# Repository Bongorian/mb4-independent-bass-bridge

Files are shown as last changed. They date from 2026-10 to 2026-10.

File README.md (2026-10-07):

# MB4 — 各弦独立・ピエゾ対応の4弦ベース用ブリッジ

4弦ベースのブリッジを、**1弦ずつ独立したアルミ切削部品と市販ステンレス金物**で構成する試作設計です。各弦に裏面ピエゾを追加でき、高さとオクターブを個別に調整できます。球端から弦を伸ばす構成はRay Rossを参考にしています。

This repository documents a prototype four-string bass bridge with independent modules, optional per-string piezo pickups, adjustable height, and 20 mm of intonation travel. It includes CNC STEP files, drawings, hardware lists, reproducible CAD sources, and the complete Rev A–L design history. Documentation is primarily in Japanese; the current shop drawings and quotation brief are in English.

**最新版はRev Lです。ボールエンド保持部を、丸い入口と半円の奥を持つ一つの座へ再設計しました。球端後方の不要な溝をなくしています。** 汎用Jazz Bass／Precision Bass系を想定していますが、既存のFender系5穴への互換設計ではありません。取付位置は実機で決める、新規穴あけ用の試作です。CADの形状・干渉を確認した段階で、実機強度・耐久性・音響とJLC CNCの正式な加工受託は未確認です。

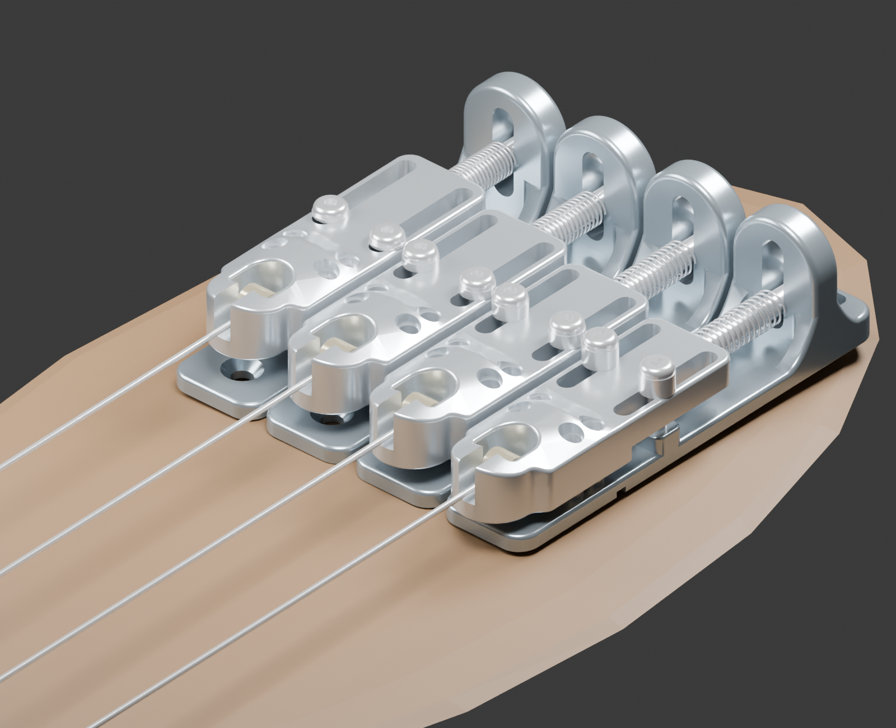
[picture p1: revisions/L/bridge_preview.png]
Rev LのCADプレビュー


## まず読む資料

| 知りたいこと | 資料 |
| --- | --- |
| 仕組み・寸法・設計の狙い | [設計説明](docs/design.md) |
| 組立・弦高・オクターブ調整 | [組立と調整](docs/assembly.md)、[図入りガイド](revisions/L/pdf/MB4_RevL_guide.pdf) |
| CNCの見積・発注に使うファイル | [加工と調達](docs/manufacturing.md) |
| Rev AからLまでの変更 | [開発履歴](docs/revision-history.md) |
| 確認済みの範囲と残る評価 | [検証記録](docs/validation.md) |
| ソースからSTEPなどを作り直す | [再生成手順](docs/reproduction.md) |

## Rev Lの主要仕様

| 項目 | 設計値・構成 |
| --- | --- |
| 弦数・弦間 | 4弦、19 mmピッチ、全幅75 mm |
| 機械加工部品 | B10ベース＋A10アンカー、各弦2部品・合計8部品 |
| 材質 | 両部品ともアルミ6061-T6 |
| 各ベースの外形 | 幅18 × 長さ86 × 最大高さ25 mm |
| アンカーの外形 | 幅18 × 長さ55 × 最大高さ10.5 mm（包絡上限） |
| 参考弦中心高さ | ボディ表面から8〜20 mm。球端と巻き部の実物で変わる |
| オクターブ調整 | 20 mm連続、中央から前後各10 mm |
| 高さ・固定金物 | M4平先4本／弦、M3固定ねじ2本／弦 |
| 後方調整 | M4×45全ねじ＋UY6-35圧縮ばね |
| ボディ固定 | 前1穴＋後1穴／弦、合計8穴 |
| ピエゾ | 各弦裏面にφ12以下、接着・配線込み厚さ1.2 mm以下を想定 |

**ベース板の長さ86 mmと、可動部を含む全長は別です。** 前方限界ではアンカーが15 mm張り出し、モジュール全長は101 mmになります。

機能に必要な取付面・固定座・高さねじの走行面は平面です。凸曲面の仕上げ工程が増えるため、Rev Jと同じ加工費を想定せず見積で確認します。

## ダウンロードと加工用データ

- [Rev L JLC見積用ZIP](downloads/MB4_JLCCNC_upload_RevL.zip)：B10とA10の単品STEP＋対応する英文加工図。各4個。
- [Rev L 6面プレビューZIP](downloads/MB4_RevL_six_views.zip)：同倍率の正投影画像。
- [Releases](https://github.com/Bongorian/mb4-independent-bass-bridge/releases)：Blenderモデルなどを含む元のRev Lフルパッケージも配布。
- [B10ベースSTEP](revisions/L/cad/step/B10_streamlined_base.step)／[B10加工図](revisions/L/pdf/B10_streamlined_base.pdf)
- [A10アンカーSTEP](revisions/L/cad/step/A10_sculpted_ball_anchor.step)／[A10加工図](revisions/L/pdf/A10_sculpted_ball_anchor.pdf)
- [部品表](revisions/L/BOM.csv)、[ミスミ購入候補](revisions/L/MISUMI_purchase_options.csv)、[原寸取付DXF](revisions/L/MB4_mount_template_1to1.dxf)

加工に提出するのは**Rev Lの単品STEPと同名の加工図**です。組立STEP・STL・外観画像は参考資料です。STEPのねじ穴は下穴径なので、加工図のタップ指示も必要です。旧版と最新版の部品・図面を混ぜないでください。

## Rev A〜Iの発展とRev J/K/L

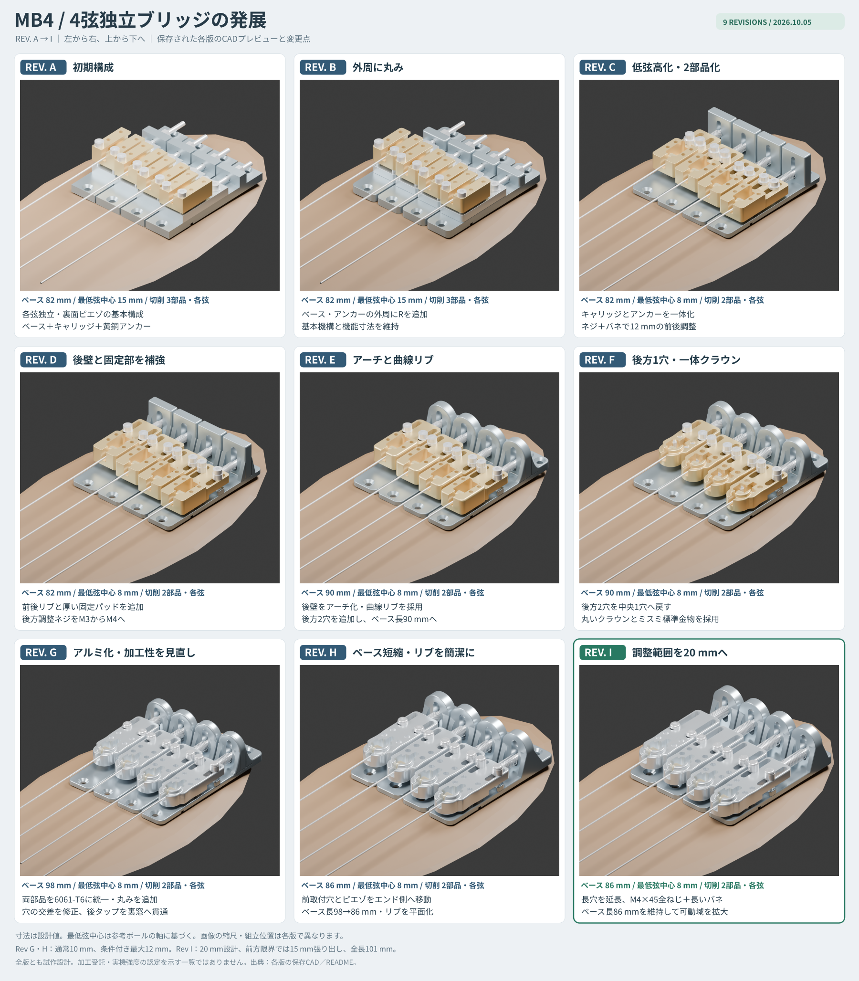
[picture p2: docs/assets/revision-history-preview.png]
Rev A〜Iの開発一覧


[高解像度の一覧PNG](docs/assets/revision-history.png) ／ [変更点の詳細](docs/revision-history.md)

Rev Jでは稜線にRを追加し、Rev Kでは上面を前から後ろへ流線的につなぎました。[Rev I→J](docs/assets/rev-i-to-j.png) ／ [Rev J→K](docs/assets/rev-j-to-k.png)で確認できます。

Rev Lは球端保持部を改訂しました。[保持部の拡大画像](revisions/L/ball_cradle_empty.png)と[装着参考](revisions/L/ball_cradle_loaded.png)を参照してください。

## リポジトリ構成

```text
README.md              プロジェクトの入口と最新版へのリンク
docs/                  設計・組立・加工・検証・履歴の説明
docs/assets/           Rev A〜Iの一覧画像
revisions/A/ ... L/    各版の保存STEP・PDF・ソース・部品表・プレビュー
downloads/             Rev Lの見積用ZIPと6面画像ZIP
tools/                 整合性確認と一覧画像の再生成
```

過去版は開発記録です。各フォルダの元READMEは当時の寸法・判断を保存しています。現行のファイル構成や発注手順はこのREADMEと`docs/`を参照してください。大きなBlenderファイル、再生成できるSTL、作業ログ、ローカルPython環境はGitの管理対象から外しています。

更新日：2026-10-07。試作の実物評価・加工先の審査結果が出たら、対応する改訂版として記録する想定です。

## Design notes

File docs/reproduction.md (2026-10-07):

# 再生成とファイルの扱い

## 環境

現在のSTEPはCadQuery 2.8.0で生成しています。保存プレビューはBlender 4.5.9を使用しています。Python依存の固定バージョンは[Rev L requirements](../revisions/L/cad/requirements.txt)を参照してください。動作確認環境はUbuntu・Python 3.12です。

```bash
python3 -m venv .venv
.venv/bin/pip install -r revisions/L/cad/requirements.txt
```

画像の日本語ラベルにはNoto Sans CJKのフォントが必要です。6面画像の合成ソースはLinuxの標準フォントパスを使用しています。別のOSではフォントパスを環境に合わせて変更します。

## Rev LのCAD再生成

```bash
.venv/bin/python revisions/L/cad/build_bridge.py
.venv/bin/python revisions/L/cad/verify_travel.py
```

部品STEP・組立STEP・プレビュー用STL・scene manifest・検証JSONが`revisions/L/cad/`以下に生成されます。`parameters.json`は設計値の一覧ですが、寸法の一部は生成コード内にもあります。全寸法が自動連動するパラメトリックモデルではありません。形状変更時にはコード・図面・金物選択を合わせて更新します。

保存STEPを生成し直さず検査する場合は、`build_bridge.py --verify-existing`で、現行ソースから作るB-repとの一致と9条件の機能確認を行えます。

## プレビューと加工資料

```bash
blender --background --python-exit-code 1 --python revisions/L/cad/render_bridge.py
blender --background --python-exit-code 1 --python revisions/L/cad/render_ball_cradle.py
blender --background --python-exit-code 1 --python revisions/L/cad/render_six_views.py
.venv/bin/python revisions/L/cad/compose_six_views.py
.venv/bin/python revisions/L/cad/make_documents.py
.venv/bin/python revisions/L/cad/package_outputs.py
```

CAD生成→通常プレビュー→6面プレビュー→画像合成→PDF/部品表→パッケージの順で実行します。`render_six_views.py`は通常プレビューで保存するBlenderモデルを読みます。生成後はPDFの全ページをレンダーし、図・寸法・文字の重なりと、STEPと同じ改訂になっていることを目視確認します。

再生成したZIPは`revisions/L/`以下にできます。トップレベルの`downloads/`は公開用に保存したコピーなので、自動で差し替わりません。変更を配布する場合は対応ZIPをコピーし、資料・保存ファイルのチェックサムを更新してからコミットします。加工形状を変える場合は、新しい改訂として記録することを推奨します。

## 歴史的版

各版は独立した`revisions/<版>/cad/build_bridge.py`と`parameters.json`を持ちます。その版の`requirements.txt`を使用します。過去READMEの相対パスや元の配布名は当時の記録です。現在は`output_revH/...`ではなく`revisions/H/...`を使用します。

Rev HのA06加工図はRev Gから変更せず流用したため、図面の版表示がRev Gです。Rev LはB10/A10双方の新しい図面を持ちます。保存PDFを最新版と混ぜないでください。

## 開発一覧画像

```bash
python3 tools/make_revision_overview.py
```

各版の保存PNGをそのまま配置し、日本語説明を加えたSVGレイアウトを作ります。Ubuntuのlibrsvg・Cairo・Noto Sans CJKを使用してPNGへ描画します。画像の形状を生成AIで描き直す処理はありません。

## 資料の整合性確認

```bash
python3 tools/check_repository.py
```

このチェックは標準ライブラリだけで実行できます。リンクと配布物の整合性を確認し、加工可否や実物の強度判定は行いません。

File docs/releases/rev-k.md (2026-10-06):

# Rev K — 流線的な外形と高さ穴の縁

丸い前部から低い後部へ滑らかにつながる上面と、単純なアーチ・曲線リブを持つ試作版です。アンカー中央の盛り上がった筋や、支柱の別の座ボスを設けず、穴の縁が外周や隣の加工部へ切れない形に整理しました。

- 上面は連続したBezier面、後部は一段の固定平面Z8。上限10.5 mm（切欠き後のSTEP最高値は約10.42 mm）。
- 後壁は厚さ6のR9アーチ、前後縁R1.2。一続きの3 mm曲線リブを支柱内部へ2 mm重ね、固定パッド根元も底板へつなげます。
- 高さ穴をアンカー座標X±5.5/Y19・24へ移し、入口φ4.2・床Z8に変更。床周囲0.5 mm、タップ主径周囲0.8 mmの材料をCAD確認。
- ベース86 mm、参考弦中心8〜20 mm、オクターブ20 mm、木ねじ・ピエゾ位置、市販金物候補を維持。

加工対象はB09_streamlined_baseとA09_streamlined_anchor、両方6061-T6、各4個です。最新版の単品STEPと同名英文PDFを併用してください。前方限界の張り出し15 mm、モジュール全長101 mmです。

## ダウンロード

- `MB4_CNC_prototype_RevK.zip`：CAD・STEP・図面・部品表・ガイド・Blender・STL・プレビューの一式。
- `MB4_JLCCNC_upload_RevK.zip`：B09/A09の単品STEP＋同名英文加工図、計4ファイル。
- `MB4_RevK_six_views.zip`：6面プレビューと画像生成ソース。
- `rev-j-to-k.png`：Rev JとKの同条件のCADレンダー比較。

[README](https://github.com/Bongorian/mb4-independent-bass-bridge#readme)から設計説明・組立・調達・検証・再生成手順を読めます。過去版は保存しています。

## 確認範囲

9つの位置／高さ条件、1 mm刻み21位置、入口床の縁とねじ周囲の材料、高さ足の接地、座面接触、STEP再読込を確認しました。元CADとSTEPの両方向の形状差分は0、外形座標差は1e-5 mm未満です。体積数値積分は診断値として記録します。

曲面仕上げの加工量は増えます。JLCの工具到達性・受託可否・価格、実物の強度・疲労・弦の球端適合・木部保持・ピエゾ性能は未確認です。STEP＋対応図面で手動見積審査を依頼する資料です。

## 配布物のSHA-256

```text
04e64b7c81280b9260a139cd08f7b878d53910644a1df4d1c6e72b4872af992e  MB4_CNC_prototype_RevK.zip
0aff2bb30ec78b04c7777be666f19021fa927c6372cc8626bd08be98724e24f5  MB4_JLCCNC_upload_RevK.zip
40939c0831099249c68dbce3949f1855e0372b30fb1f3a133ace95b778d89680  MB4_RevK_six_views.zip
6c2ca22163dc0604c4ab6a724325f499ec6b36fb4377719d1634a07c94e5cb18  rev-j-to-k.png
```

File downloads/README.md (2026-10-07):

# Rev Lのダウンロード

- [MB4_JLCCNC_upload_RevL.zip](MB4_JLCCNC_upload_RevL.zip)：B10とA10の単品STEPと同名PDF、計4ファイル。各4個で見積依頼するための資料。
- [MB4_RevL_six_views.zip](MB4_RevL_six_views.zip)：6面画像、一覧画像、視点情報、説明と画像生成ソース。
- [Releases](https://github.com/Bongorian/mb4-independent-bass-bridge/releases)：元のRev Lフルパッケージ。CADソース、Blenderモデル、プレビュー、加工資料、組立ガイド等を含む。

最新版の仕様と未評価事項は[トップREADME](../README.md)と[加工説明](../docs/manufacturing.md)を参照してください。見積用ZIPの存在はJLCの加工受託や発注完了を示しません。

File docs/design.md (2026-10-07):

# 設計説明 — MB4 Rev L

## 何を作る設計か

MB4は、4弦ベースの各弦を独立したブリッジモジュールで保持する試作設計です。複雑な専用金物を増やさず、アルミ部品2種類と市販のねじ・座金・圧縮ばねで、高さ・オクターブ調整とピエゾ取付を成立させることを目的としています。

弦間は19 mm、各ベース幅18 mmなので、隣のベースとの間に1 mmあります。中央の弦間基準に対する各弦のX座標は−28.5、−9.5、9.5、28.5 mmです。

## 1弦分の構成

| 構成要素 | 役割 |
| --- | --- |
| B10ベース | 木部へ固定する板、調整ねじを受ける後壁、リブ、固定ねじのパッド、裏面ピエゾ窪み |
| A10アンカー | 凸上面とカプセル状の球端保持部、弦の逃げ、前後移動用長穴、高さねじ、後方M4タップ |
| M4平先4本 | アンカーをベース上に支持し、高さを変える |
| M3固定ねじ2本 | 長穴を通して位置を固定する |
| 後方M4×45＋ばね | 前後位置を調整する。ねじを締めるとエンド側へ引き、緩めるとばねが前へ押す |
| 前後の木ねじ | モジュールをボディへ固定する |

Ray Rossの球端から弦を伸ばす構成を参考に、従来のサドルに相当する保持部を一体の保持部にしています。メーカー製品のtone pinと同じ機構・音響特性を再現したと確認した設計ではありません。実際の支点は球端・巻き部によって変わるため、実弦で評価します。

## ボールエンド保持部の再設計

Rev Lは、角丸四角形の窪みと後方へ延びる細溝を、一つのカプセル状の保持座へ整理しました。前には弦張力を受ける肩を残し、奥は大きな半円、上面との境界は実形状のR0.6でつなぎます。後方の不要な細溝をなくしたため、球端の後ろに連続した材料が残ります。

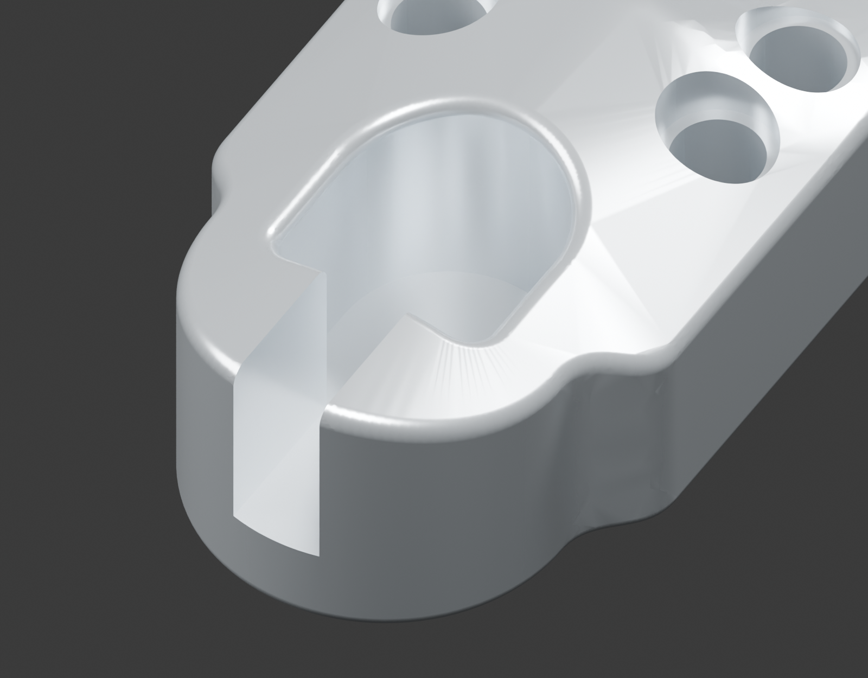
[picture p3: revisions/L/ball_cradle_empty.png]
球端保持座の拡大


窪みの基準形状は幅8.2、Y6〜15、底Z2、前内隅R1.1、奥R4.1（中心Y10.9）です。前の保持肩はY6、幅6を前向きの幅3.4の弦出口で二分します。弦出口の底Z3.3は維持し、後方へは延ばしません。入口のRによる広がりはSTEPを参照します。

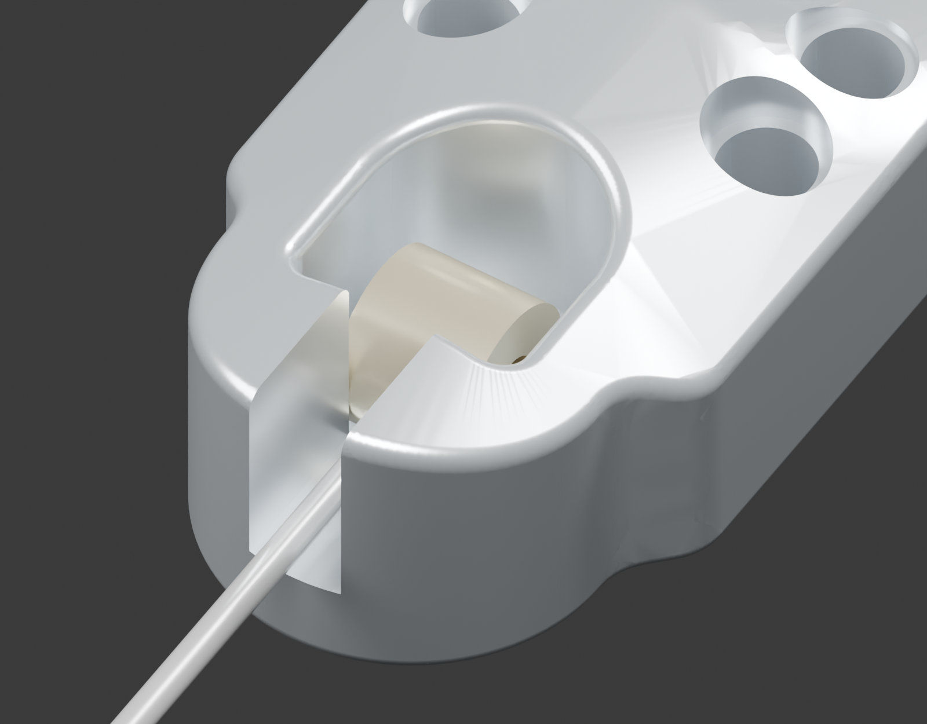
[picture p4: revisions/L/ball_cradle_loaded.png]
球端装着の参考


球端を上からY11へ入れ、前の肩へ寄せます。参考球端は外径6・横幅4.75の円筒、横軸X、着座中心Y9/Z5です。CADでは縦挿入とY11から9への移動、肩による前方への抜け止め、前方の弦出口を確認しました。弦張力で肩に保持する構成であり、球端を締め付ける追加のねじはありません。無張力で上方へ取り出せるため、完全な包囲や無張力時の脱落防止は保証しません。

実物の球端・巻き部の寸法と接触は未確定です。市販の全弦に対応するとの保証ではなく、使用弦で収まり・接触・弦高・必要なオクターブ補正を評価します。保持肩Y6と底Z2を保ち、参考弦高8〜20 mmと調整20 mmは維持しています。B10ベースはRev KのB09と同形状で、A10との組合せを明確にするため品番・版を揃えています。

## 低い弦高と調整域

ベース下面をZ0、主板上面をZ3とします。アンカー下面と主板上面の隙間を`g`とすると、参考弦中心は`H = 8 + g` mmです。`g = 0〜12`で参考高さ8〜20 mmになります。後壁の高さ25 mmは構造物の全高であり、最低弦高ではありません。

各アンカーの前端位置を、ベース前端Y0に対して`q`とします。Rev Lでは`q = −15〜5`、移動量20 mmです。中央は`q = −5`です。固定長穴は全長23.4 mm・幅3.4 mmで、M3軸中心が20 mm移動した両端に公称0.2 mmの余裕を持たせています。

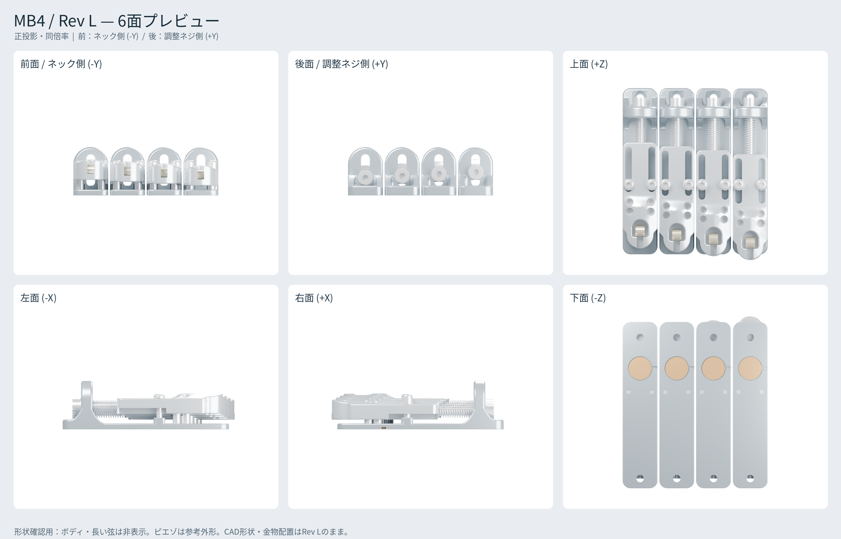
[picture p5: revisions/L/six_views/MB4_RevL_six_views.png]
Rev Lの6面図


Rev Iでベース長を増やさず可動域を広げるため、アンカー長を50→55 mm、後壁位置を7.5 mmエンド側へ移し、ネジ先端が移動できる裏面開放窓を延長しました。Rev Lでもその機構を維持しています。前方限界ではアンカーが15 mm張り出し、モジュール全長は101 mmです。ネック側の余白とピックガードとの干渉も取付時に確認します。

## 流線的な外形と穴の縁

Rev Kから継続して、丸い前部から低い後部へつながる一枚の上面を持ちます。前側は放物線の断面で、側端X±9/Z7.8、頂部X0/Z10.5です。Y21〜27.8で接線が滑らかにつながる面を使い、後部上面Z8へ下げます。独立した円柱クラウン、後部中央の盛り上がった筋と、個別の固定座の段差をなくしました。最高部は10.5 mm、弦の保持位置は維持するので参考最低弦高は8 mmです。

支柱は厚さ6の単純なR9アーチ、前後縁R1.2です。座金・ばねは前後の平面で受け、追加の座ボスを設けません。左右の3 mmリブは一続きの曲線で支えます。外稜線R0.8、内側縦根元R2、内稜線はC0.2 MAXのバリ取りです。曲線の詳細はSTEPを基準にします。根元下の装飾的な溝は作りません。

高さ穴をX±5.5/Y19・24へ移し、上側入口をφ4.2にしています。輪郭のくびれをなくし、外周・隣の穴・固定座へ入口が切れ込む形を避けました。床Z8から下面まで8 mmのM4ねじ領域を保ち、入口床周囲の0.5 mm材料と、タップ主径周囲の0.8 mm材料をCAD確認します。穴周辺の最終バリ取り・丸みは図面指示の範囲で行います。

必要な取付面・固定座・走行面・接着面は平面です。曲面仕上げが増えるため、加工費と工具到達性は手動見積審査で確認します。リブの曲線化後の荷重下剛性と疲労は未評価です。材料ガードのCAD確認を実物強度保証として扱いません。

## 各弦ピエゾ

ベース裏面の中心X0/Y24にφ12.5・深さ1.5 mmの窪みがあります。φ12以下の素子を金属面へ接着し、接着・配線を含めた厚さを1.2 mm以下にする想定です。木部と挟み込む構成ではありません。

4個の素子を各々の高インピーダンス入力・バッファへ接続する想定です。具体的なピエゾ品番と電子回路はこのリポジトリでは確定していません。機械的に独立したモジュールでも共通木部から振動が回り込むため、完全な弦間分離を保証しません。

## 座標と取付

各部品のX0は幅の中央、Y0はその部品のネック側前端、Z0は下面です。アンカーの寸法とベースの寸法はそれぞれの原点で記載します。アンカーをベースへ組むときはY方向へ`q`、Z方向へ`3 + g`移動します。

ベースの木ねじ中心はX0/Y8とX0/Y81、前後間隔73 mmです。既存ブリッジを交換する場合にも取付位置の実測が必要です。参考保持肩はベース座標で`Y = q + 6`です。最終位置は実弦、ネック、必要な補正量から決定してください。

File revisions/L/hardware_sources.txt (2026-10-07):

REV L NOTE / 2026-10-07: hardware choices unchanged from Rev J.
Catalogue/price dates below are historical; no new live price claim.

Rev J：市販金物はRev Iから変更なし。以下は2026-10-05に確認した参照記録です。

MB4 Rev I / MISUMI reference / 2026-10-05

Rev Iで後方ねじとばねを変更。型式と仕様を公式公開表で確認。新2品の現在価格・見積は未取得、注文はしていません。
以下の従来金物の価格は同日Rev Hで確認した条件付きの参考値です。購入時に数量・納期・送料を再確認。

1. 後方ねじ：ミスミ SNSS-M4X45-FT（メーカー NBK SNSS-M4-45-FT）
https://jp.misumi-ec.com/vona2/detail/221000236253/
https://www.nbk1560.com/products/specialscrew/nedzicom/captivescrew/SNSS-FT/SNSS-M4-FT/
SUSXM7（SUS304相当）、A2-50、M4x0.7、全ねじ45、頭径7、高さ4、六角3。4本。
通常の半ねじSCB4-45は使用不可。首下の非ねじ部がタップ域へ入るためです。
公称ボルト先端Y32。最前q=-15で全周8のかかり、長さが短い側0.5なら7.5。
最後q=5で先端はアンカー局所Y27。長い側0.5なら26.5で、開放窓内に収まる。
メーカー表示価格とミスミ表示価格は条件が違うため購入合計として混同しません。

2. ばね：ミスミ UY6-35
https://jp.misumi-ec.com/vona2/detail/110302604820/
OD6、線径0.4、自由長35±1.5、k0.098±10% N/mm、密着長参考6.8、許容たわみ26.25。
SUS304-WPB。クローズエンド無研削。UY6-20/E-GUY6-20は20 mm案に流用しない。
作動長15.5-q =30.5〜10.5。最短の自由長33.5でも最前位置に予圧3が残る。
最長の自由長36.5・最短作動10.5でたわみ26.0≤26.25。CAD公称の残り0.25なので実寸でも確認。
寸法公差・加工座位置の積み重なりで可動端を少し制限する場合があります。密着まで潰さない。
参考ねじ内径：OD下限5.5-線径2x0.4=4.7。線径・端部の実物適合は別途照合。

3. 高さ：MSSFS4-8 / MSSFS4-12 / MSSFS4-16（SUSXM7、平先）
https://jp.misumi-ec.com/vona2/detail/110302679970/?HissuCode=MSSFS4-8
https://jp.misumi-ec.com/vona2/detail/110302679970/?HissuCode=MSSFS4-12
https://jp.misumi-ec.com/vona2/detail/110302679970/?HissuCode=MSSFS4-16
六角2、各弦4本。g≤4は8、4<g≤8は12、8<g≤12は16。
10〜199本の通常価格は8が117円、12/16が118円。納期割引はいずれも38円／本。1〜9本は通常160円、納期割引80円。必要4本なら320円、10本380円より少額。必要12本なら12本456円。
単価4〜7円のエコノミーE-GMSSFSは最低500本等なので、1本分の試作では購入総額が増える。M3×16のSSHH-SUS品は販売終了、推奨代替SSHHI-SUS-M3-16は1000本箱14,743円の表示だったため、M4標準3長さへ変更した。

4. 固定：SCB3-16（安価なキャップ頭の代案）（SUS304相当、A2-70）
https://jp.misumi-ec.com/vona2/detail/110300239250/?HissuCode=SCB3-16
画像初期設定g=5/4/3/2は全8本L16。10本通常550円、納期割引150円。
gを大きく変える場合はSCB3-12/20/25もガイド3頁から選択。シリーズ規格表で寸法候補を確認、これら3型番の個別価格は未確認。L25の半ねじ18はクランプの通し長穴では使える（基部Z0〜6はねじ域）。

5. 小径座金：WSJS-SUS-M3 / WSJS-SUS-M4（SUS304）
https://jp.misumi-ec.com/vona2/detail/221000552007/?HissuCode=WSJS-SUS-M3
https://jp.misumi-ec.com/vona2/detail/221000552007/?HissuCode=WSJS-SUS-M4
M3はOD6/ID3.3/t0.5、固定ねじの高さ合わせに重ねる。画像初期設定はt0.5/1.5/2.5/3.5を各2組、計32枚。50枚×60円=3000円、100枚×30円=3000円（確認した数量別価格表の計算）。100枚のほうが追加高さ調整に使える。厚さは実測し、ねじ先端の突出を避ける。
M4はOD8/ID4.5/t0.5、後方4枚×228円=912円。
座金は今回のミスミ小ロット金物費の大きい部分。同寸法の手持ちSUS品を使える。大径M3座金へ無条件に置換せず、外径6以下を守る。
厚いUUW-0306-35は外径6/内径3.2/t3.5が適合するが50個以上、薄いUUW-0306-05Hは1個からでも表示314円。初期4弦用ではJIS小形の厚さスタックを候補とする。

6. 木ねじ：コノエ270011003520
https://jp.misumi-ec.com/vona2/detail/221006330995/?HissuCode=270011003520
ステンレス皿木ねじ3.5×20、85本入り1パック1200円、6日目。前4＋後4=8本使用。頭径・90°皿との適合は購入前または現物で照合（掲載寸法の3.5/20と材質は確認、頭径の詳細は未確認）。木部の下穴・厚さ・空洞・既存穴との位置を実測する。

7. 丸い低頭の固定ねじ（Rev Iの参考組立）
https://jp.misumi-ec.com/vona2/detail/110302280450/
SSBCB3-12 / SSBCB3-16 / SSBCB3-20（SUS316、A4-070）、SBCB3-25（SUSXM7、A2-50）。M3頭径5.7/高さ1.65、六角2。系列の規格表と寸法表で確認。SSBCBのM3に25はなく、SBCBのM3に16はありません。型番を混同しないこと。
個別の現在価格は未確認。系列の価格表には「25年8月時点」と記載されているため、それを現在の見積額として採用していません。初期画像は8本ともSSBCB3-16。購入前に8本・10本・20本の総額と納期を比較。価格優先なら、確認済みSCB3-16の10本150円（納期割引条件）はCADを変えずに使える代案。
ボタン頭の外形は丸い参考モデルで、メーカーCADそのものではありません。頭径・高さ・六角を公称包絡に合わせています。

8. 初期配置
q=3/1/-1/-3、g=5/4/3/2。高さM4x12を4本、x8を12本。固定M3x16を8本、座金0.5を32枚。
後方M4x45全ねじ4本、M4座金4枚、UY6-35を4個、木ねじ8本。
価格合計は未確定。旧Rev F/G/Hの合計は新構成の購入額として使用しません。

Rev L: cradle only changed; hardware candidates retained from Rev K. No fresh price/stock lookup on 2026-10-07.

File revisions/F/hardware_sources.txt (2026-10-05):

MB4 Rev F — MISUMI部品参照・購入メモ（2026-10-05）

公開ページと「価格を確認」の見積表示を確認。発注・カート追加は行っていません。税別、購入時再確認。価格には表示上の特別配送料が含まれる場合があります。送料・アカウント条件・在庫・出荷日は注文時に確認。以下は確認した候補内での購入総額比較で、ミスミ全商品中の最安を保証する選定ではありません。

1. ばね：UY6-20（SUS304-WPB）
https://jp.misumi-ec.com/vona2/detail/110302604820/?HissuCode=UY6-20
OD6、線径0.35、内径公称5.3、L20、k0.098 N/mm、密着長参考3.85、許容たわみ15、端面非研削。外径0/−0.5、L±1.5、k±10%。外径下限と公称線径からの内径参考4.8はM4より大きい（線径公差・ばね端の実物適合は別途）。
通常250円／個。納期割引10日目：1〜3個125円、4〜9個87円。1弦試作1個125円、4弦4個348円。
代案E-GUY6-20：
https://jp.misumi-ec.com/vona2/detail/110310903599/?HissuCode=E-GUY6-20
公称寸法・荷重は同じ。通常78円／個、10個単位・最低10。購入10個780円。急ぐ場合はUY4個通常1000円より少額。
作動長17〜5は公称寸法。実測自由長−作動長≤15を守る。L21.5なら最短6.5（q最大18.5）。密着長まで潰して使わない。固定する弦張力とは別の小荷重ばねです。

2. 後方調整ねじ：SCB4-30（SUS304相当、A2-70）
https://jp.misumi-ec.com/vona2/detail/110300239250/?HissuCode=SCB4-30
M4×30、半ねじ20、頭D7/H4、六角3。10〜29本：通常77円、納期割引19円。使用4本でも10本買190円は、4本×140円=560円より少額。1弦試作では1本140円が少額。
M4×35の半ねじは同じ20でも首下15がタップ域に入り得るため、そのまま置換しない。M4×30に合わせCADを改訂。公称重なり6.5〜18.5、首下とアンカー最大後端の隙間1.5。実物の有効ねじ6以上を確認する。

3. 高さ：MSSFS4-8 / MSSFS4-12 / MSSFS4-16（SUSXM7、平先）
https://jp.misumi-ec.com/vona2/detail/110302679970/?HissuCode=MSSFS4-8
https://jp.misumi-ec.com/vona2/detail/110302679970/?HissuCode=MSSFS4-12
https://jp.misumi-ec.com/vona2/detail/110302679970/?HissuCode=MSSFS4-16
六角2、各弦4本。g≤4は8、4<g≤8は12、8<g≤12は16。
10〜199本の通常価格は8が117円、12/16が118円。納期割引はいずれも38円／本。1〜9本は通常160円、納期割引80円。必要4本なら320円、10本380円より少額。必要12本なら12本456円。
単価4〜7円のエコノミーE-GMSSFSは最低500本等なので、1本分の試作では購入総額が増える。M3×16のSSHH-SUS品は販売終了、推奨代替SSHHI-SUS-M3-16は1000本箱14,743円の表示だったため、M4標準3長さへ変更した。

4. 固定：SCB3-16（SUS304相当、A2-70）
https://jp.misumi-ec.com/vona2/detail/110300239250/?HissuCode=SCB3-16
画像初期設定g=5/4/3/2は全8本L16。10本通常550円、納期割引150円。
gを大きく変える場合はSCB3-12/20/25もPDF5頁から選択。シリーズ規格表で寸法候補を確認、これら3型番の個別価格は未確認。L25の半ねじ18はクランプの通し長穴では使える（基部Z0〜6はねじ域）。

5. 小径座金：WSJS-SUS-M3 / WSJS-SUS-M4（SUS304）
https://jp.misumi-ec.com/vona2/detail/221000552007/?HissuCode=WSJS-SUS-M3
https://jp.misumi-ec.com/vona2/detail/221000552007/?HissuCode=WSJS-SUS-M4
M3はOD6/ID3.3/t0.5、固定ねじの高さ合わせに重ねる。画像初期設定はt0.5/1.5/2.5/3.5を各2組、計32枚。50枚×60円=3000円、100枚×30円=3000円（確認した数量別価格表の計算）。100枚のほうが追加高さ調整に使える。厚さは実測し、ねじ先端の突出を避ける。
M4はOD8/ID4.5/t0.5、後方4枚×228円=912円。
座金は今回のミスミ小ロット金物費の大きい部分。同寸法の手持ちSUS品を使える。大径M3座金へ無条件に置換せず、外径6以下を守る。
厚いUUW-0306-35は外径6/内径3.2/t3.5が適合するが50個以上、薄いUUW-0306-05Hは1個からでも表示314円。初期4弦用ではJIS小形の厚さスタックを候補とする。

6. 木ねじ：コノエ270011003520
https://jp.misumi-ec.com/vona2/detail/221006330995/?HissuCode=270011003520
ステンレス皿木ねじ3.5×20、85本入り1パック1200円、6日目。前4＋後4=8本使用。頭径・90°皿との適合は購入前または現物で照合（掲載寸法の3.5/20と材質は確認、頭径の詳細は未確認）。木部の下穴・厚さ・空洞・既存穴との位置を実測する。

7. 初期設定の購入総額の例
MISUMI_initial_setup_example.csv：g=5/4/3/2、q=18/16/14/12（画像の配置）。納期割引を適用できるものに適用し、公開数量別価格から計算すると金物合計6576円（税別）。CNC2部品、ピエゾ、接着・配線・電子部品は含まない。1台完成までの総費用や見積確定額ではありません。高い弦高へ交換するM4×16とM3の別長さはこの初期購入例に含まない。

8. Ray Ross参照
開発者の説明： https://www.deviser.co.jp/rayross/about
Kemp2023研究： https://journals.plos.org/plosone/article?id=10.1371/journal.pone.0292515
本案は独自の一体クラウン保持部。Ray Rossのtone pin構造と同一ではなく、同じ音響特性を認定していません。

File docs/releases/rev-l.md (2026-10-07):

# Rev L — ボールエンド保持部の再設計

ボールエンドの保持部を、前の平らな肩と奥の大きな半円を持つ一つのカプセル座にしました。上面との入口境界を実形状R0.6でつなぎ、球端の後方へ延びていた不要な細い溝をなくしています。

- 保持窪み：幅8.2、Y6〜15、前内隅R1.1、奥R4.1、底Z2。
- 保持肩Y6と参考弦軸Z5を維持。弦出口は幅3.4・底Z3.3の前方だけです。
- 外径6・幅4.75の参考円筒球端で、縦挿入、前の肩へ寄せる経路、前方抜け止めをCAD確認。
- 参考弦中心8〜20 mm、オクターブ20 mm、ベース86 mmと市販金物を維持。
- B10ベースはRev KのB09と同形状。保持部を変えたA10と版・品番を揃えています。

加工対象はB10_streamlined_baseとA10_sculpted_ball_anchor、6061-T6、各4個です。同名の単品STEPと英文加工図を併用します。最前位置の張り出し15 mm、モジュール全長101 mmです。

## ダウンロード

- `MB4_CNC_prototype_RevL.zip`：CAD・STEP・加工図・部品表・ガイド・Blender・STL・通常／拡大プレビューの一式。
- `MB4_JLCCNC_upload_RevL.zip`：B10/A10単品STEPと同名英文加工図、計4ファイル。
- `MB4_RevL_six_views.zip`：6面プレビューと画像生成ソース。
- `ball_cradle_empty.png`：球端保持座を空の状態で確認するCAD拡大画像。

[README](https://github.com/Bongorian/mb4-independent-bass-bridge#readme)から設計説明・組立・調達・検証・再生成手順を読めます。過去版は保存しています。

## 確認範囲

各部品の有効性とSTEP再読込、9つの位置／高さ条件、1 mm刻み21位置、4本の高さ足、ねじ周辺の材料、機能座面と入口床の縁を確認しました。球端の縦挿入11高さと着座経路11位置を参考形状で検査し、前方へ0.3 mm変位した球端が保持肩に当たることを確認しました。新旧ベースの両方向Boolean差分体積は0です。

弦張力で肩へ保持する開放構造です。締め付けねじや無張力時の上方脱落防止機構は追加していません。実物の球端・巻き部適合、接触、強度・疲労、木部保持、ピエゾ性能、JLCの加工受託・価格は未確認です。CADは試作見積資料であり、発注はしていません。

## 配布物のSHA-256

```text
0f81e32088d3af8071832b93dffd80d3daf665328a75f05430c7ffd8c2e29471  MB4_CNC_prototype_RevL.zip
52262cb1fd562b846dd3924ec171d557de436239c5b17c7e62464229f67fe6eb  MB4_JLCCNC_upload_RevL.zip
172108623f4a4e9c7c14cdda41dab48ba1f72c3cf8765c681fdd490755602e7f  MB4_RevL_six_views.zip
cac7d3ac1d2cf34d5facabf0720da819a4b5480ff3ed958083c93bca99c99a80  ball_cradle_empty.png
```

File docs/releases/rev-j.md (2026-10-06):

# Rev J — 外周・アーチ・リブとアンカーの丸み

Rev Iの機構を維持し、外周と後壁・リブ・アンカーの稜線を一定Rで丸めた試作版です。

- 後壁アーチ縁R1.2、リブ外側R0.8・内側R0.5、自由な前板上縁R0.5。
- アンカー上縁R1.2・下縁R0.6、クラウン上縁R1.2・根元R0.6。
- ベース長86 mm、20 mmのオクターブ調整、参考弦中心8〜20 mm、穴位置・ピエゾ位置・金物はRev Iと共通。
- リブの基本面は簡潔な平面を維持。曲線の膨らみや根元下の溝は追加していません。

加工対象はB08_rounded_baseとA08_rounded_anchor、両方6061-T6、各4個です。新しい単品STEPと同名の英文加工図を併用してください。前方限界ではアンカーが15 mm張り出し、モジュール全長101 mmです。

## ダウンロード

- `MB4_CNC_prototype_RevJ.zip`：CAD・STEP・図面・部品表・ガイド・Blender・STL・プレビューの一式。
- `MB4_JLCCNC_upload_RevJ.zip`：B08/A08の単品STEP＋同名英文PDF、計4ファイル。
- `MB4_RevJ_six_views.zip`：6面プレビューと生成ソース。
- `rev-i-to-j.png`：Rev IとJの比較画像。

[README](https://github.com/Bongorian/mb4-independent-bass-bridge#readme)に、文脈なしで読める設計説明・組立・調達・検証・再生成手順を整理しています。過去版は開発履歴として保存しています。

## 確認範囲

9つの前後位置・高さ条件、1 mm刻み21位置、M4周辺材料、高さ足の接地、STEP再読込を確認しました。丸みの曲面について元ソリッドとSTEPの両方向Boolean差分は体積0、外形座標差は1e-5 mm未満です。

一定Rの仕上げパスは増えます。JLCの加工受託・工具到達性・価格、実物の強度・疲労・球端適合・木部保持・ピエゾ性能は未確認です。Rev Iの図面とは混ぜないでください。

## SHA-256

```text
7b65bbe42676a487e3f9052490c8d40ead28eaad107a8ed2b524325313ed0627  MB4_CNC_prototype_RevJ.zip
ab7b4e9c57ca968b28b27881d6b1a4822d5bbc315503f346f7cf4f189f40c46a  MB4_JLCCNC_upload_RevJ.zip
ab24897194916a0cecbef8d11a3664640be46f4d6773b3b2e711626f29d4ee69  MB4_RevJ_six_views.zip
d7162a3460deec55edbec67f03354f49b57dc14550c576853ecbbd51c6a71e0d  rev-i-to-j.png
```

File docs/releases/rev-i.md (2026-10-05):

# Rev I — 20 mm調整とRev A〜Iの設計資料

各弦独立・ピエゾ対応の4弦ベース用ブリッジの試作設計です。ベース長86 mmのままオクターブ調整範囲を20 mmへ拡大したRev Iと、Rev A〜Iの保存CAD・図面・開発履歴を公開します。

[README](https://github.com/Bongorian/mb4-independent-bass-bridge#readme)から設計説明、組立・調整、加工・部品調達、検証範囲、再生成手順へ進めます。

## 添付ファイル

- `MB4_CNC_prototype_RevI.zip`：元のRev Iフルパッケージ。STEP、加工PDF、部品表、ガイド、CADソース、STL、Blenderモデル、プレビュー。元の配布ディレクトリ構成を保持しています。
- `MB4_JLCCNC_upload_RevI.zip`：B07ベースとA07アンカーの単品STEP＋英文加工図、計4ファイル。2種類を各4個で見積依頼します。
- `MB4_RevI_six_views.zip`：6面プレビューと視点情報・生成ソース。
- `revision-history.png`：Rev A〜Iの発展一覧、3600×4110 px。

GitHubのSource code ZIP/TARは整理後のリポジトリ全体で、A〜Iの保存データと新しい説明資料を含みます。元のフルパッケージとファイル配置が異なります。

## 仕様と評価段階

両切削部品はアルミ6061-T6、弦間19 mm、各弦2部品、参考弦中心8〜20 mm。前方限界ではアンカーが15 mm張り出し、モジュール全長101 mmです。後方はM4×45全ねじとUY6-35ばねを使用します。

CADの干渉確認・STEP再読込を実施しています。荷重・疲労・実弦適合・木部保持・ピエゾの感度と分離度は未評価です。JLCの見積・加工受託・発注は未実施です。旧版の部品や図面と混ぜないでください。

## 添付ファイルのSHA-256

```text
319a7b376d95de474a8513af2a0e5a0c840293bac8c61157ca2935c93aa96914  MB4_CNC_prototype_RevI.zip
324d667b94bea5a883e1dbc90f82b83b5c560085ba9352a642665661eed917d0  MB4_JLCCNC_upload_RevI.zip
baa7da487169ea34584f2419ecf6429733881d2921c9ffcfaab547fe5ae87ecc  MB4_RevI_six_views.zip
ae5dc7ef1dc507fb8415ac4d3a79e0a0bd267b09a514d441e56a566cd063f4fe  revision-history.png
```

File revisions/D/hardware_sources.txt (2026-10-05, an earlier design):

MB4 Rev D 金物の仕様参照（2026-10-05調査）
型番例は寸法と規格の参照。価格・国内在庫・発送先は未確認。
同等規格の一般的なステンレス金物から調達してください。

M4×35全ねじ 六角穴付：Accu SSCF-M4-35-A2-BL 等
https://www.accu.co.uk/metric-cap-head-screws/159430-SSCF-M4-35-A2-BL
標準キャップ頭φ7×4、六角3、ピッチ0.7。全ねじ指定が必要。

M3小径座金：DIN433 φ6/内径3.2/厚0.5
https://www.accu.co.uk/metric-flat-washers/404911-HRDW-M3-A4
M4小径座金：DIN433 φ8/内径4.3/厚0.5
https://www.accu.co.uk/metric-flat-washers/404944-HRDW-M4-A4-BL
M3は一般φ7では隣弦の座金との余裕が小さいため、外径6以下を使用。

圧縮ばね：MBA CS-0500-0200-03-S4-C
https://minibearings.com/products/5-20-0-3-springs-cs0500020003s4c
メーカーPDF p.20：
https://files.minibearings.au/pdf/catalogues/Springs.pdf
OD5、自由長20、線0.3、内径4.4参考、作動5で荷重1.47 N、密着3.15、定数0.1 N/mm。
外形だけで代用せず、M4軸の通過と使用作動長5〜17の条件を購入品で確認。

ねじ引張応力断面積：Bossard Materials screws & nuts の並目ねじ表
M3 5.03 mm2、M4 8.78 mm2。
https://www.bossard.com.cn/-/media/bossard-group/website/documents/technical-resources/en/f-009-en.pdf
参照寸法は概算比較用。強度等級・締付け・局所応力を含む全体強度保証ではありません。

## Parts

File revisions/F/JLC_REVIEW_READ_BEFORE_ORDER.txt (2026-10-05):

MB4 Rev F / JLCCNC加工性確認 / 2026-10-05

結論
アルミ製ブリッジをJLCCNCへ依頼する方向は成立する。ただし現行Rev Fは、そのまま確定発注する版として扱わない。
公開加工条件とローカルSTEPを照合した設計側の判定。JLCCNCによる個別ファイルの受注承認、見積回答、CAM確認は取得していない。

対象
B04_single_rear_base：18×90×25 mm、板厚3、固定パッド6、後方座面5。
A05_crown_anchor：18×42×10 mm、本体8。
ユーザーの希望はアルミ。両部品6061-T6を試作の見積候補とする。JLCCNCは6061と7075に対応する。
現行Rev FのPDF、BOM、features.csvではアンカーがC3604真鍮。両部品をアルミにする発注用図面へ改訂が必要。材質変更だけでは、以下の形状の問題は解消しない。

修正が必要：高さタップと窪みの重なり
前側M4高さタップ：中心(±5,15)、ボール窪み側壁X±4、窪み底Z2。
M4の外径半径2に対し、タップ中心から窪み側壁まで1しかないため、内側で約1 mm重なる。
STEPのφ3.3下穴も窪みに開口する。上部の穴は全周を囲まれたタップではない。
実STEP検査：右前穴の内側点(2.98,15,1)には材料があり、(2.98,15,3)/(2.98,15,6)には材料がない。左前穴も同様。
前穴の全周を囲む部分は公称約2 mmに限られる。高い設定でねじ掛かりが上部だけになる場合もある。
後側穴(±5,20.5)も、下面の逃げへねじ外径の後方が一部開口する。実点(±5,22.52,1)に材料なし。
タップ位置、窪み幅・長さ、裏逃げを同時に変更し、ねじ外径に対する連続した肉厚と各高さでの掛かりを再確認する。
この欠肉は前回のCAD干渉確認で拾えていなかった問題。ソリッドが有効であることは、タップの加工性や強度の保証ではない。
検査ログ：jlc_thread_wall_check.json / 再検査：cad/check_jlc_thread_walls.py。
図解：JLC_thread_wall_issue.png。

技術審査が必要：後尾の深いM4
A05後端Y42、X0/Z4からM4×0.7-6H、有効20 mm、下穴φ3.3深さ22＋先端1。
有効ねじ長20はM4の呼び径の5倍。JLCCNCの推奨3D以内という目安を超える。
特殊工具・追加費用・加工時間の懸念があるが、推奨値を超えたことだけで加工不可能とは断定しない。
現行M4×30の最大公称侵入18.5に対応するため、単にタップを12へ浅くする変更は不可。
盲穴底の余長も確認し、ねじ／調整幅／アンカー形状をまとめて見直すか、現行深さの受注可否をJLCへ確認する。

内側の角と小R
B04：壁とリブの交点X±6/Y67およびY73に、鋭角の内側縦エッジが残る。
STEPの直線縦エッジ：前Z3.8〜13.6298、後Z3〜14.0939。上方から加工する場合の到達深さと工具径を併せて検討。
この壁・リブ内隅に工具用の平面Rを設計側で追加し、ばねと座金の包絡域を再確認する。
重要：中央根元R0.8は底面と壁の丸み。平面の内隅Rと異なり、R0.8だけを根拠に工具径φ1.6しか使えないとは判断しない。コーナR付きエンドミルなどで加工する方法があり、JLCの工具・段取り確認が必要。
A05：弦スリット幅3.4、底Z3.3、終端Y22の内側縦角は工具Rの指示が必要。終端を丸める場合、後尾タップと球受けの機能を再確認する。
球受けはR1.5、最大深さ8。小径工具での加工候補だが、工具長・加工費は個別審査。
クラウン根元R0.4の仕上げ方法は確認対象。外周の凸R、底面・壁のR、平面内隅Rを混同して判定しない。
指定R±0.05を外観用の全Rへ要求すると費用が増える可能性がある。機能に必要なRを特定し、外観Rの許容差は別にする。

公開条件上、見通しがよい部分
部品全体寸法はJLCCNCの寸法範囲内。
板厚3、後方座面5、ピエゾ窪み底の残厚1.5は、金属壁厚推奨0.8を上回る。ただしこれは加工上の目安でありブリッジの許容荷重ではない。
ピエゾ窪みφ12.5深さ1.5、配線溝幅2.2深さ1.2は浅い開放形状。
M3×0.5貫通6、M4×0.7貫通8は一般的なサイズ。ただし周囲の肉の問題を解消してから依頼する。
先端R7、後壁R9、有機的な輪郭は切削できる種類の形状。段取り・工具パスの費用は別途。

発注データの整え方
1. B04とA05を別々の単一ソリッドSTEPで登録。MB4_assembly.stepは製作登録に使わない。
2. 部品ごとにSTEPと同名のPDFを用意し、両方の材質をアルミへ統一する。
3. Web選択をThreads=YES、材質6061-T6、数量各1個（試作）または各4個にする。
4. PDFへM3×0.5-6H / M4×0.7-6H、位置、貫通／有効深さ、必要公差を明記。現行のφ2.5／φ3.3下穴表現はJLCの要求に合う。
5. 一般寸法±0.10と機能寸法±0.05の範囲を図示。必要面だけ平面度・Raを指定。
6. ボール保持肩・接触面・支持面・穴口は、標準の約0.2 mmバリ取りではなく必要なC0.1以下などを個別指定する。
7. 初回は無処理を見積候補にする。アルマイトを選ぶ場合はタップ、支持・固定面、ピエゾ接着面、電気的導通箇所と仕上がり寸法を合わせて確認する。
8. JLCの技術審査が完了し、形状変更と材料指定が一致してから確定発注する。
従来のMB4_CNC_order_RevF.zipは一般の試作見積用で、上記問題を修正したJLC確定発注版ではない。JLCはアップロードZIPの中身をSTEP/PDF/DWG/DXF等の対応形式に限定しているため、CSV・画像・READMEを含む旧ZIPをそのままアップロードしない。

JLCへの確認用メモ（未送信）
Both parts are intended to be machined in Aluminum 6061-T6. Please review each single-body STEP with its matching PDF.
Please confirm the available internal corner radii and tool access at the wall/rib intersections, the crown root, and the end of the string slot.
Please confirm whether the rear M4x0.7-6H hole with 20 mm minimum usable thread and a 22 mm cylindrical pilot depth is supported, and whether it adds tooling costs.
Please identify any required radius, blind-hole clearance or tolerance changes before manufacturing.
The current height-hole/pocket overlaps are under design revision; do not release the unchanged Rev F geometry for production.

参照：2026-10-05閲覧のJLCCNC公式情報
設計ガイド：https://jlccnc.com/help/article/cnc-machining-design-guideline
タップ穴：https://jlccnc.com/help/article/threaded-hole-guideline
注文・ファイル・優先規則：https://jlccnc.com/help/article/cnc-machining-ordering-guidelines
加工能力：https://jlccnc.com/capabilities/cnc-machining-service
6061：https://jlccnc.com/help/article/aluminum-6061-cnc-machining
7075：https://jlccnc.com/help/article/aluminum-7075-cnc-machining

未確認
実機工具・CAM・治具・受注可否・価格・納期、実弦のボール端／巻き部、強度・疲労・木ねじ保持力、アルミでの接触部摩耗とねじ寿命、ピエゾの出力とクロストーク。

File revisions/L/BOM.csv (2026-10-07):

ID | item | quantity_for_4_strings | specification
B10 | Streamlined arch base 6061-T6 | 4 | 18x86x25; STEP + matching PDF
A10 | Refined ball-end anchor 6061-T6 | 4 | 18x55x10.5; STEP + matching PDF
H01 | SNSS-M4X45-FT | 4 | M4x45; FULL THREAD required; capheadD7/H4
H02 | WSJS-SUS-M4 | 4 | OD8/ID4.5/t0.5
H03 | UY6-35 | 4 | SUS304-WPB; OD6/wire0.4/L35+/-1.5/k0.098/solid6.8/deflection26.25
H04 | MSSFS4-8/12/16 | 16 | 4/string; length by g; flat end
H05 | SSBCB3-12/16/20 or SBCB3-25 | 8 | 2/string; buttonheadD5.7/H1.65; 2mm hex; length by g
H06 | WSJS-SUS-M3 | height dependent | OD6/ID3.3/t0.5; stack by g; OD6 maximum
H07 | 270011003520 | 8 | SUS flathead wood screw3.5x20; verify headD<=7/90deg
P01 | Piezo reference envelope | 4 | OD<=12; total mounted thickness<=1.2; individual channels

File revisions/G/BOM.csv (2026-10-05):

ID | item | quantity_for_4_strings | specification
B05 | Smooth base 6061-T6 | 4 | 18x98x25; STEP + matching PDF
A06 | Smooth anchor 6061-T6 | 4 | 18x50x10; STEP + matching PDF
H01 | SCB4-30 | 4 | M4x30; threaded20/plain10; capheadD7/H4
H02 | WSJS-SUS-M4 | 4 | OD8/ID4.5/t0.5
H03 | UY6-20 | 4 | SUS304-WPB; OD6/wire0.35/L20/k0.098/solid3.85
H04 | MSSFS4-8/12/16 | 16 | 4/string; length by g; flat end
H05 | SSBCB3-12/16/20 or SBCB3-25 | 8 | 2/string; buttonheadD5.7/H1.65; 2mm hex; length by g
H06 | WSJS-SUS-M3 | height dependent | OD6/ID3.3/t0.5; stack by g; OD6 maximum
H07 | 270011003520 | 8 | SUS flathead wood screw3.5x20; verify headD<=7/90deg
P01 | Piezo reference envelope | 4 | OD<=12; total mounted thickness<=1.2; individual channels

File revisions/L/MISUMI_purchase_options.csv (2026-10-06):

用途 | 型番 | 価格適用数量 | 販売単位 | 最小注文数量 | 通常単価_税別円 | 納期割引単価_税別円 | 納期条件 | 仕様と選び方（Rev J：金物同じ） | 確認状態 | 確認日 | URL
後方オクターブねじ | SNSS-M4X45-FT | 4個見積要確認 | 本 | 1 |  |  | 現在見積は未取得 | NBK SNSS-M4-45-FT; SUSXM7/A2-50; M4x45 FULL THREAD; headD7/H4/hex3 | 公開仕様・規格表確認。現価格は未確認 | 2026-10-05 | https://jp.misumi-ec.com/vona2/detail/221000236253/
圧縮ばね | UY6-35 | 4個見積要確認 | 個 | 1 |  |  | 現在見積は未取得 | SUS304-WPB; OD6/wire0.4/L35+/-1.5/k0.098/solid6.8/Fmax26.25 | 公開仕様・規格表確認。23年価格は現在価格として採用しない | 2026-10-05 | https://jp.misumi-ec.com/vona2/detail/110302604820/
固定：価格優先のキャップ頭代案 | SCB3-16 | 10〜29 | 本 | 1 | 55 | 15 | 1日目／納期割引10日目 | M3x16; SUS304相当 A2-70; 全ねじ; 頭D5.5 H3 hex2.5; 8本使用 | 数量10の見積表示確認 | 2026-10-05 | https://jp.misumi-ec.com/vona2/detail/110300239250/?HissuCode=SCB3-16
高さ調整：gで長さ選択 | MSSFS4-8 | 10〜199 | 本 | 1 | 117 | 38 | 1日目／納期割引10日目 | SUSXM7; M4x0.7; 平先; hex2; L8; 有効掛かり公称4..8 | 数量10または20の見積表示確認 | 2026-10-05 | https://jp.misumi-ec.com/vona2/detail/110302679970/?HissuCode=MSSFS4-8
高さ調整：必要数購入 | MSSFS4-8 | 1〜9 | 本 | 1 | 160 | 80 | 1日目／納期割引10日目 | 同上。4本使用なら4本320円、10本380円より少額 | 見積表示の公開数量別価格表 | 2026-10-05 | https://jp.misumi-ec.com/vona2/detail/110302679970/?HissuCode=MSSFS4-8
高さ調整：gで長さ選択 | MSSFS4-12 | 10〜199 | 本 | 1 | 118 | 38 | 1日目／納期割引10日目 | SUSXM7; M4x0.7; 平先; hex2; L12; 有効掛かり公称4..8 | 数量10または20の見積表示確認 | 2026-10-05 | https://jp.misumi-ec.com/vona2/detail/110302679970/?HissuCode=MSSFS4-12
高さ調整：必要数購入 | MSSFS4-12 | 1〜9 | 本 | 1 | 160 | 80 | 1日目／納期割引10日目 | 同上。4本使用なら4本320円、10本380円より少額 | 見積表示の公開数量別価格表 | 2026-10-05 | https://jp.misumi-ec.com/vona2/detail/110302679970/?HissuCode=MSSFS4-12
高さ調整：gで長さ選択 | MSSFS4-16 | 10〜199 | 本 | 1 | 118 | 38 | 1日目／納期割引10日目 | SUSXM7; M4x0.7; 平先; hex2; L16; 有効掛かり公称4..8 | 数量10または20の見積表示確認 | 2026-10-05 | https://jp.misumi-ec.com/vona2/detail/110302679970/?HissuCode=MSSFS4-16
高さ調整：必要数購入 | MSSFS4-16 | 1〜9 | 本 | 1 | 160 | 80 | 1日目／納期割引10日目 | 同上。4本使用なら4本320円、10本380円より少額 | 見積表示の公開数量別価格表 | 2026-10-05 | https://jp.misumi-ec.com/vona2/detail/110302679970/?HissuCode=MSSFS4-16
固定：価格優先のキャップ頭代案 | SCB3-12 | 選択数 | 本 | 1 |  |  | 型番確定後確認 | M3x0.5; Lはガイド3頁で選択。L25半ねじも可（基部はねじ域） | シリーズ規格表の寸法候補。個別価格未確認 | 2026-10-05 | https://jp.misumi-ec.com/vona2/detail/110300239250/?HissuCode=SCB3-12
固定：価格優先のキャップ頭代案 | SCB3-20 | 選択数 | 本 | 1 |  |  | 型番確定後確認 | M3x0.5; Lはガイド3頁で選択。L25半ねじも可（基部はねじ域） | シリーズ規格表の寸法候補。個別価格未確認 | 2026-10-05 | https://jp.misumi-ec.com/vona2/detail/110300239250/?HissuCode=SCB3-20
固定：価格優先のキャップ頭代案 | SCB3-25 | 選択数 | 本 | 1 |  |  | 型番確定後確認 | M3x0.5; Lはガイド3頁で選択。L25半ねじも可（基部はねじ域） | シリーズ規格表の寸法候補。個別価格未確認 | 2026-10-05 | https://jp.misumi-ec.com/vona2/detail/110300239250/?HissuCode=SCB3-25
固定M3の座金スタック | WSJS-SUS-M3 | 100〜9999 | 個 | 1 | 30 |  | 1日目／納期割引10日目 | SUS304; OD6/ID3.3/t0.5。画像の初期設定は計32枚、100枚3000円 | 数量50見積の公開数量別価格表。100枚合計は計算 | 2026-10-05 | https://jp.misumi-ec.com/vona2/detail/221000552007/?HissuCode=WSJS-SUS-M3
固定M3の座金スタック | WSJS-SUS-M3 | 50〜99 | 個 | 1 | 60 |  | 1日目／納期割引10日目 | 同上。50枚も3000円。100枚購入なら追加調整にも使える | 数量50の見積表示確認 | 2026-10-05 | https://jp.misumi-ec.com/vona2/detail/221000552007/?HissuCode=WSJS-SUS-M3
後方M4の小形座金 | WSJS-SUS-M4 | 4 | 個 | 1 | 228 |  | 1日目／納期割引10日目 | SUS304; OD8/ID4.5/t0.5。4枚912円 | 数量4の見積表示確認 | 2026-10-05 | https://jp.misumi-ec.com/vona2/detail/221000552007/?HissuCode=WSJS-SUS-M4
ボディ取付・木ねじ | 270011003520 | 1 | パック(85本) | 1 | 1200 |  | 6日目 | コノエSUS皿木ねじ3.5x20。85本入り、8本使用。頭径/皿角は実物照合 | 数量1パックの見積表示確認 | 2026-10-05 | https://jp.misumi-ec.com/vona2/detail/221006330995/?HissuCode=270011003520
厚い座金の代案（少量非推奨） | UUW-0306-35 | 50以上 | 個 | 50 | 63 |  | 8日目 | SUS303; OD6/ID3.2/t3.5。50個3150円は表示単価の計算。用途ごとMOQを確認 | 仕様・最小注文数・通常表示価格確認。見積未確認 | 2026-10-05 | https://jp.misumi-ec.com/vona2/detail/221006201172/?HissuCode=UUW-0306-35
薄い座金の代案（個別購入高価） | UUW-0306-05H | 1以上 | 個 | 1 | 314 |  | 1日目／納期割引10日目 | SUS304; OD6/ID3.2/t0.5。形状適合候補 | 仕様・最小注文数・通常表示価格確認。見積未確認 | 2026-10-05 | https://jp.misumi-ec.com/vona2/detail/221006201172/?HissuCode=UUW-0306-05H
固定：丸いボタン頭 | SSBCB3-12 | 見積要確認 | 本 | 1 |  |  | 現在見積は未取得 | 頭D5.7/H1.65/六角2; 首下長に応じ座金スタック | 公開シリーズ寸法確認・現在価格未確認 | 2026-10-05 | https://jp.misumi-ec.com/vona2/detail/110302280450/
固定：丸いボタン頭 | SSBCB3-16 | 見積要確認 | 本 | 1 |  |  | 現在見積は未取得 | 頭D5.7/H1.65/六角2; 首下長に応じ座金スタック | 公開シリーズ寸法確認・現在価格未確認 | 2026-10-05 | https://jp.misumi-ec.com/vona2/detail/110302280450/
固定：丸いボタン頭 | SSBCB3-20 | 見積要確認 | 本 | 1 |  |  | 現在見積は未取得 | 頭D5.7/H1.65/六角2; 首下長に応じ座金スタック | 公開シリーズ寸法確認・現在価格未確認 | 2026-10-05 | https://jp.misumi-ec.com/vona2/detail/110302280450/
固定：丸いボタン頭 | SBCB3-25 | 見積要確認 | 本 | 1 |  |  | 現在見積は未取得 | 頭D5.7/H1.65/六角2; 首下長に応じ座金スタック | 公開シリーズ寸法確認・現在価格未確認 | 2026-10-05 | https://jp.misumi-ec.com/vona2/detail/110302280450/

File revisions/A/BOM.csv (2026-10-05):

ID | 品名・材質 | 4弦分の数量 | 備考
B01 | 固定ベース A6061-T6 | 4 | 18×82×12
C01 | キャリッジ A6061-T6 | 4 | 18×40×5
A01 | アンカー C3604 | 4 | 18×26×10
H01 | M3×10 平先 六角穴付き止めねじ SUS | 16 | 高さ調整
H02 | M3×16 六角穴付きボルト SUS | 8 | アンカー保持 g<=3
H03 | M3×20 六角穴付きボルト SUS | 8予備 | アンカー保持 g>3
H04 | M3×10 六角穴付きボルト SUS | 8 | キャリッジ固定
H05 | M3 DIN562 薄形四角ナット SUS | 8 | 5.5角×厚さ1.8
H06 | M3全ねじ棒 SUS、長さ40 | 4 | キャリッジへ10ねじ込む
H07 | M3六角ナット SUS | 8 | 後面調整＋ジャムロック
H08 | M3平座金 φ7×厚さ0.5 SUS | 12 | 固定用8、後面用4
H09 | M3小形平座金 φ6×厚さ0.5 SUS | 32予備 | アンカー保持用の長さ合わせ
H10 | 3.5×20 皿木ねじ SUS | 8 | 頭φ7以下／下穴は木部に合わせる
P01 | φ12以下・接着型ピエゾ接触センサ | 4別途 | 参考外形、品番未確定

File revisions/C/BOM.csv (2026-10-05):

ID | 品名 | 4弦数量 | 仕様
B01 | 固定ベース A6061-T6 | 4 | 18×82×23、板厚3、一体切削
A02 | 一体アンカー C3604 | 4 | 18×42×10、後尾高さ6
H01 | SUS M3×30 六角穴付 全ねじ | 4 | 後方調整用、頭φ5.5×3、六角2.5
H02 | SUS M3用座金 φ7/3.2/t0.5 | 4 | 後方ねじ用
H03 | SUS圧縮ばね OD5/線径0.3/自由長20 | 4 | 使用長5〜17、密着長3.15、定数0.1 N/mm
H04 | SUS M3平先止めねじ×10 | 16 | g=0〜6、高さ用、六角1.5
H05 | SUS M3平先止めねじ×16 | 16 | g>6〜12用の交換セット
H06 | SUS M3全ねじ×10/12/16/20/25 | 8使用 | 高さに応じて5ページから選択
H07 | SUS M3座金／標準スペーサ | 8組 | OD7以下、ID3.2程度、合計t0.5〜5.5
H08 | SUS皿木ねじ3.5×20 | 8 | 頭φ7以下、木部厚・下穴は実測
P01 | ピエゾφ12以下＋接着・配線 | 4 | 実装総厚1.2以下、接触センサとして接着

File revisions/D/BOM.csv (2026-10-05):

ID | 品名 | 4弦数量 | 仕様
B02 | 補強ベース A6061-T6 | 4 | 18×82×25、板3／固定部6
A03 | 強化アンカー C3604 | 4 | 18×42×10、後尾8／裏逃げ3
H01 | SUS M4×35 六角穴付 全ねじ | 4 | A2-70等、頭φ7×4、六角3
H02 | SUS DIN433 M4座金 | 4 | φ8/4.3/t0.5、後方用
H03 | SUS圧縮ばね OD5/線径0.3/自由長20 | 4 | 作動5〜17、内径4.4参考、密着3.15
H04 | SUS M3平先止めねじ×10 | 16 | g=0〜6、高さ用、六角1.5
H05 | SUS M3平先止めねじ×16 | 16 | g>6〜12への交換セット
H06 | SUS M3全ねじ×12/16/20/25 | 8使用 | gに応じて5ページから選択
H07 | SUS DIN433 M3座金／スペーサ | 8組 | 外径6以下、内径3.2、t0.5〜5.5
H08 | SUS皿木ねじ3.5×20 | 8 | 頭φ7以下、木部厚と下穴は実測
P01 | ピエゾφ12以下＋接着・配線 | 4 | 実装総厚1.2以下、各弦個別

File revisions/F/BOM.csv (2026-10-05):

ID | 品名 | 4弦数量 | 仕様
B04 | 一穴・曲線ベース A6061-T6 | 4 | 18×90×25、板3／固定6／後座5
A05 | 一体クラウン C3604 | 4 | 18×42×10、本体8／裏逃げ3
H01 | SCB4-30 SUS M4×30 半ねじ | 4 | ねじ部20、頭φ7×4／六角3
H02 | WSJS-SUS-M4 小形座金 | 4 | φ8/4.5/t0.5、後方用
H03 | UY6-20 または E-GUY6-20 | 4 | OD6/線径0.35/L20、k0.098 N/mm
H04 | MSSFS4-8/12/16 SUS平先 | 16使用 | 高さ用、六角2、gで交換
H05 | SCB3-12/16/20/25 SUS | 8 | 固定用、gに応じ5頁から選択
H06 | SUS小径座金／スペーサ | 8組 | OD6以下／ID3.2以上、合計t選択
H07 | SUS皿木ねじ 3.5×20 | 8 | 前4＋後4、頭φ7以下／90°
P01 | ピエゾφ12以下＋接着・配線 | 4 | 実装総厚1.2以下、各弦個別

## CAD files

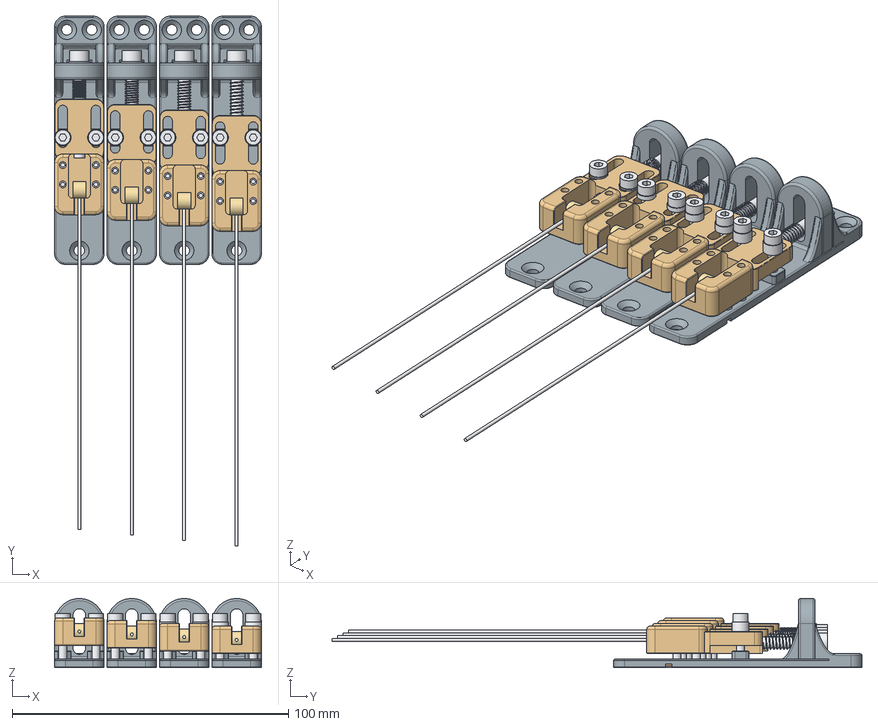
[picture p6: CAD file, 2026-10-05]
revisions/E/cad/step/MB4_assembly.step
75.0 x 192.0 x 25.0 mm
S1_B03_organic_base_0
S1_A04_organic_anchor_1
S1_clamp_washer_stack_2
S1_clamp_M3_3
S1_clamp_washer_stack_4
S1_clamp_M3_5
S1_height_M3_6
S1_height_M3_7
S1_height_M3_8
S1_height_M3_9
S1_intonation_M4x35_10
S1_intonation_washer_11
S1_compression_spring_REFERENCE_12
S1_string_reference_13
S1_ball_reference_ONLY_14
S1_piezo_envelope_ONLY_15
S2_B03_organic_base_0
S2_A04_organic_anchor_1
S2_clamp_washer_stack_2
S2_clamp_M3_3
S2_clamp_washer_stack_4
S2_clamp_M3_5
S2_height_M3_6
S2_height_M3_7
S2_height_M3_8
S2_height_M3_9
S2_intonation_M4x35_10
S2_intonation_washer_11
S2_compression_spring_REFERENCE_12
S2_string_reference_13
S2_ball_reference_ONLY_14
S2_piezo_envelope_ONLY_15
S3_B03_organic_base_0
S3_A04_organic_anchor_1
S3_clamp_washer_stack_2
S3_clamp_M3_3
S3_clamp_washer_stack_4
S3_clamp_M3_5
S3_height_M3_6
S3_height_M3_7
S3_height_M3_8
S3_height_M3_9
S3_intonation_M4x35_10
S3_intonation_washer_11
S3_compression_spring_REFERENCE_12
S3_string_reference_13
S3_ball_reference_ONLY_14
S3_piezo_envelope_ONLY_15
S4_B03_organic_base_0
S4_A04_organic_anchor_1
S4_clamp_washer_stack_2
S4_clamp_M3_3
S4_clamp_washer_stack_4
S4_clamp_M3_5
S4_height_M3_6
S4_height_M3_7
S4_height_M3_8
S4_height_M3_9
S4_intonation_M4x35_10
S4_intonation_washer_11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

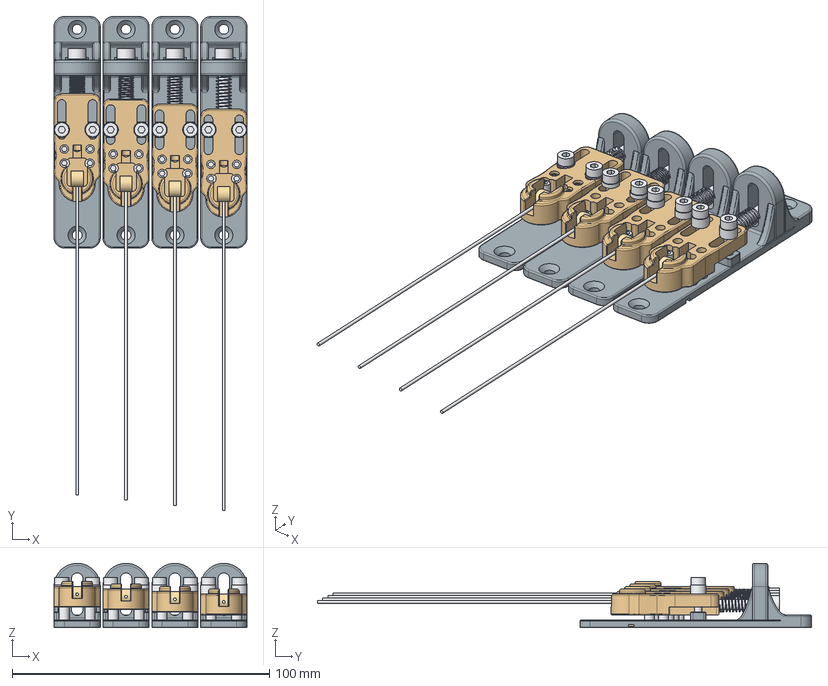
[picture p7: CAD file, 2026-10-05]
revisions/F/cad/step/MB4_assembly.step
75.0 x 192.0 x 25.0 mm
S1_B04_single_rear_base_0
S1_A05_crown_anchor_1
S1_clamp_washer_stack_2
S1_clamp_M3_3
S1_clamp_washer_stack_4
S1_clamp_M3_5
S1_height_M4_6
S1_height_M4_7
S1_height_M4_8
S1_height_M4_9
S1_intonation_M4x30_10
S1_intonation_washer_11
S1_compression_spring_REFERENCE_12
S1_string_reference_13
S1_ball_reference_ONLY_14
S1_piezo_envelope_ONLY_15
S2_B04_single_rear_base_0
S2_A05_crown_anchor_1
S2_clamp_washer_stack_2
S2_clamp_M3_3
S2_clamp_washer_stack_4
S2_clamp_M3_5
S2_height_M4_6
S2_height_M4_7
S2_height_M4_8
S2_height_M4_9
S2_intonation_M4x30_10
S2_intonation_washer_11
S2_compression_spring_REFERENCE_12
S2_string_reference_13
S2_ball_reference_ONLY_14
S2_piezo_envelope_ONLY_15
S3_B04_single_rear_base_0
S3_A05_crown_anchor_1
S3_clamp_washer_stack_2
S3_clamp_M3_3
S3_clamp_washer_stack_4
S3_clamp_M3_5
S3_height_M4_6
S3_height_M4_7
S3_height_M4_8
S3_height_M4_9
S3_intonation_M4x30_10
S3_intonation_washer_11
S3_compression_spring_REFERENCE_12
S3_string_reference_13
S3_ball_reference_ONLY_14
S3_piezo_envelope_ONLY_15
S4_B04_single_rear_base_0
S4_A05_crown_anchor_1
S4_clamp_washer_stack_2
S4_clamp_M3_3
S4_clamp_washer_stack_4
S4_clamp_M3_5
S4_height_M4_6
S4_height_M4_7
S4_height_M4_8
S4_height_M4_9
S4_intonation_M4x30_10
S4_intonation_washer_11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

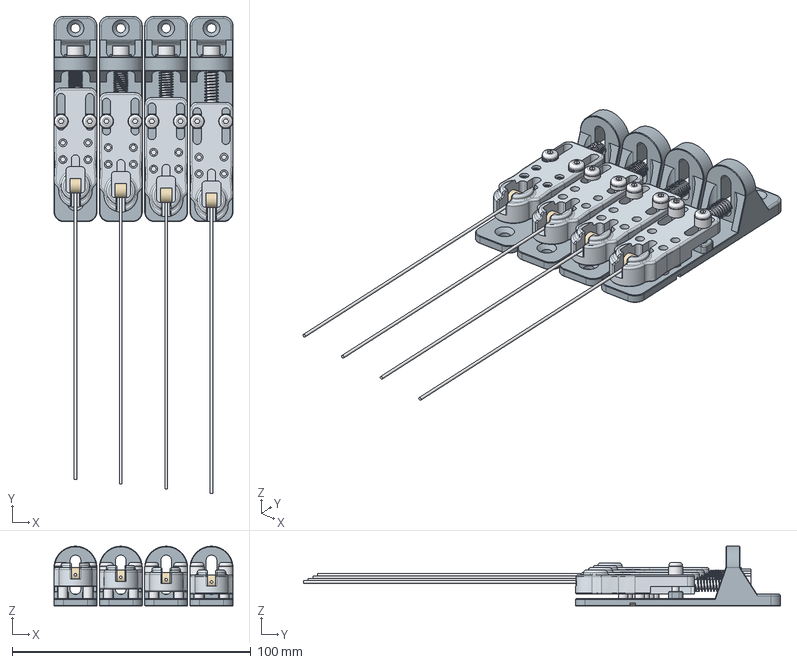
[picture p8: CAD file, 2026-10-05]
revisions/H/cad/step/MB4_assembly.step
75.0 x 200.0 x 25.0 mm
S1_B06_compact_base_0
S1_A06_smooth_anchor_1
S1_clamp_washer_stack_2
S1_clamp_M3_3
S1_clamp_washer_stack_4
S1_clamp_M3_5
S1_height_M4_6
S1_height_M4_7
S1_height_M4_8
S1_height_M4_9
S1_intonation_M4x30_10
S1_intonation_washer_11
S1_compression_spring_REFERENCE_12
S1_string_reference_13
S1_ball_reference_ONLY_14
S1_piezo_envelope_ONLY_15
S2_B06_compact_base_0
S2_A06_smooth_anchor_1
S2_clamp_washer_stack_2
S2_clamp_M3_3
S2_clamp_washer_stack_4
S2_clamp_M3_5
S2_height_M4_6
S2_height_M4_7
S2_height_M4_8
S2_height_M4_9
S2_intonation_M4x30_10
S2_intonation_washer_11
S2_compression_spring_REFERENCE_12
S2_string_reference_13
S2_ball_reference_ONLY_14
S2_piezo_envelope_ONLY_15
S3_B06_compact_base_0
S3_A06_smooth_anchor_1
S3_clamp_washer_stack_2
S3_clamp_M3_3
S3_clamp_washer_stack_4
S3_clamp_M3_5
S3_height_M4_6
S3_height_M4_7
S3_height_M4_8
S3_height_M4_9
S3_intonation_M4x30_10
S3_intonation_washer_11
S3_compression_spring_REFERENCE_12
S3_string_reference_13
S3_ball_reference_ONLY_14
S3_piezo_envelope_ONLY_15
S4_B06_compact_base_0
S4_A06_smooth_anchor_1
S4_clamp_washer_stack_2
S4_clamp_M3_3
S4_clamp_washer_stack_4
S4_clamp_M3_5
S4_height_M4_6
S4_height_M4_7
S4_height_M4_8
S4_height_M4_9
S4_intonation_M4x30_10
S4_intonation_washer_11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

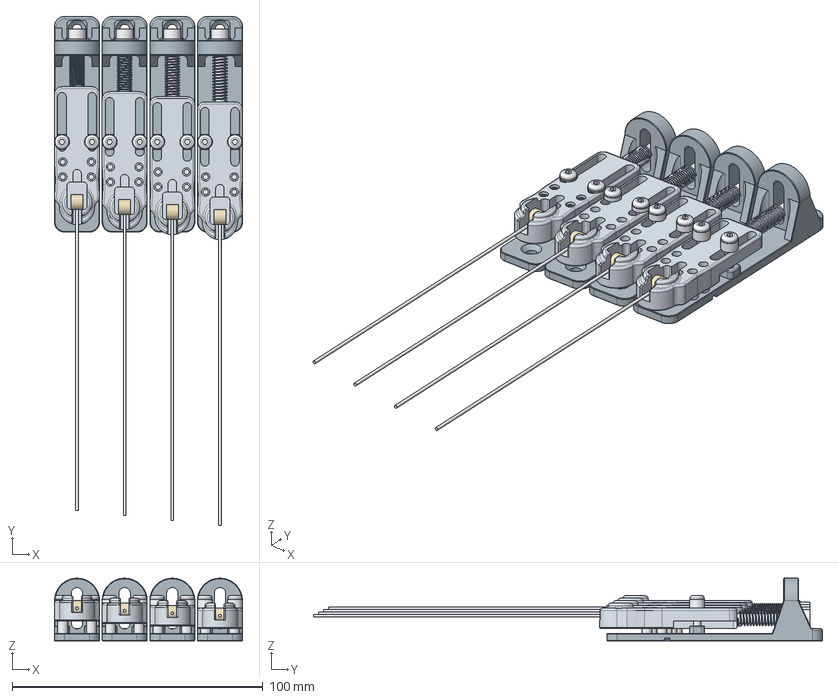
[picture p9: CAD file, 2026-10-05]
revisions/I/cad/step/MB4_assembly.step
75.0 x 203.0 x 25.0 mm
S1_B07_long_travel_base_0
S1_A07_long_travel_anchor_1
S1_clamp_washer_stack_2
S1_clamp_M3_3
S1_clamp_washer_stack_4
S1_clamp_M3_5
S1_height_M4_6
S1_height_M4_7
S1_height_M4_8
S1_height_M4_9
S1_intonation_M4x45_FULL_THREAD_10
S1_intonation_washer_11
S1_compression_spring_REFERENCE_12
S1_string_reference_13
S1_ball_reference_ONLY_14
S1_piezo_envelope_ONLY_15
S2_B07_long_travel_base_0
S2_A07_long_travel_anchor_1
S2_clamp_washer_stack_2
S2_clamp_M3_3
S2_clamp_washer_stack_4
S2_clamp_M3_5
S2_height_M4_6
S2_height_M4_7
S2_height_M4_8
S2_height_M4_9
S2_intonation_M4x45_FULL_THREAD_10
S2_intonation_washer_11
S2_compression_spring_REFERENCE_12
S2_string_reference_13
S2_ball_reference_ONLY_14
S2_piezo_envelope_ONLY_15
S3_B07_long_travel_base_0
S3_A07_long_travel_anchor_1
S3_clamp_washer_stack_2
S3_clamp_M3_3
S3_clamp_washer_stack_4
S3_clamp_M3_5
S3_height_M4_6
S3_height_M4_7
S3_height_M4_8
S3_height_M4_9
S3_intonation_M4x45_FULL_THREAD_10
S3_intonation_washer_11
S3_compression_spring_REFERENCE_12
S3_string_reference_13
S3_ball_reference_ONLY_14
S3_piezo_envelope_ONLY_15
S4_B07_long_travel_base_0
S4_A07_long_travel_anchor_1
S4_clamp_washer_stack_2
S4_clamp_M3_3
S4_clamp_washer_stack_4
S4_clamp_M3_5
S4_height_M4_6
S4_height_M4_7
S4_height_M4_8
S4_height_M4_9
S4_intonation_M4x45_FULL_THREAD_10
S4_intonation_washer_11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

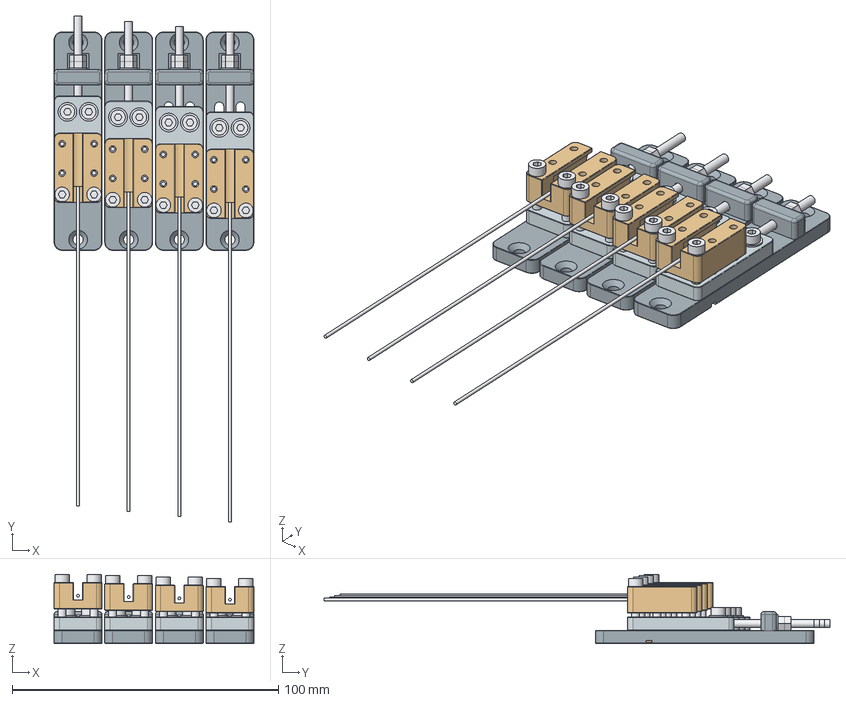
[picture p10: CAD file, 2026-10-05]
revisions/B/cad/step/MB4_assembly.step
75.0 x 190.0 x 26.0 mm
S1_B01_base_0
S1_C01_carrier_1
S1_A01_anchor_2
S1_slide_clamp_3
S1_slide_washer_4
S1_DIN562_nut_5
S1_slide_clamp_6
S1_slide_washer_7
S1_DIN562_nut_8
S1_height_M3x10_9
S1_height_M3x10_10
S1_hold_M3_11
S1_height_M3x10_12
S1_height_M3x10_13
S1_hold_M3_14
S1_intonation_M3x40_15
S1_intonation_washer_16
S1_intonation_nut_17
S1_intonation_jam_nut_18
S1_string_reference_19
S1_piezo_envelope_ONLY_20
S2_B01_base_0
S2_C01_carrier_1
S2_A01_anchor_2
S2_slide_clamp_3
S2_slide_washer_4
S2_DIN562_nut_5
S2_slide_clamp_6
S2_slide_washer_7
S2_DIN562_nut_8
S2_height_M3x10_9
S2_height_M3x10_10
S2_hold_M3_11
S2_height_M3x10_12
S2_height_M3x10_13
S2_hold_M3_14
S2_intonation_M3x40_15
S2_intonation_washer_16
S2_intonation_nut_17
S2_intonation_jam_nut_18
S2_string_reference_19
S2_piezo_envelope_ONLY_20
S3_B01_base_0
S3_C01_carrier_1
S3_A01_anchor_2
S3_slide_clamp_3
S3_slide_washer_4
S3_DIN562_nut_5
S3_slide_clamp_6
S3_slide_washer_7
S3_DIN562_nut_8
S3_height_M3x10_9
S3_height_M3x10_10
S3_hold_M3_11
S3_height_M3x10_12
S3_height_M3x10_13
S3_hold_M3_14
S3_intonation_M3x40_15
S3_intonation_washer_16
S3_intonation_nut_17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

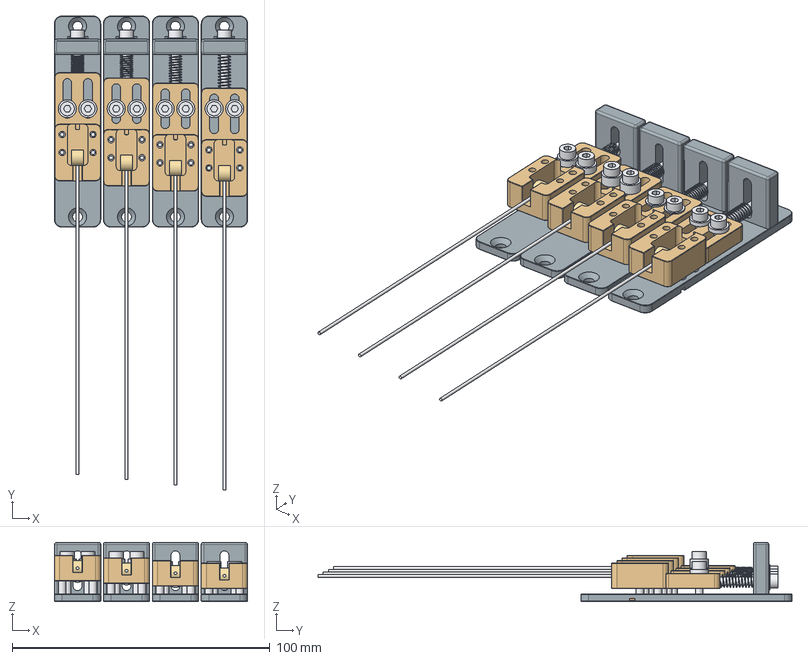
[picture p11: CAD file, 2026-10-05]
revisions/C/cad/step/MB4_assembly.step
75.0 x 184.0 x 23.0 mm
S1_B01_base_0
S1_A02_integrated_anchor_1
S1_clamp_washer_stack_2
S1_clamp_M3_3
S1_clamp_washer_stack_4
S1_clamp_M3_5
S1_height_M3_6
S1_height_M3_7
S1_height_M3_8
S1_height_M3_9
S1_intonation_M3x30_10
S1_intonation_washer_11
S1_compression_spring_REFERENCE_12
S1_string_reference_13
S1_ball_reference_ONLY_14
S1_piezo_envelope_ONLY_15
S2_B01_base_0
S2_A02_integrated_anchor_1
S2_clamp_washer_stack_2
S2_clamp_M3_3
S2_clamp_washer_stack_4
S2_clamp_M3_5
S2_height_M3_6
S2_height_M3_7
S2_height_M3_8
S2_height_M3_9
S2_intonation_M3x30_10
S2_intonation_washer_11
S2_compression_spring_REFERENCE_12
S2_string_reference_13
S2_ball_reference_ONLY_14
S2_piezo_envelope_ONLY_15
S3_B01_base_0
S3_A02_integrated_anchor_1
S3_clamp_washer_stack_2
S3_clamp_M3_3
S3_clamp_washer_stack_4
S3_clamp_M3_5
S3_height_M3_6
S3_height_M3_7
S3_height_M3_8
S3_height_M3_9
S3_intonation_M3x30_10
S3_intonation_washer_11
S3_compression_spring_REFERENCE_12
S3_string_reference_13
S3_ball_reference_ONLY_14
S3_piezo_envelope_ONLY_15
S4_B01_base_0
S4_A02_integrated_anchor_1
S4_clamp_washer_stack_2
S4_clamp_M3_3
S4_clamp_washer_stack_4
S4_clamp_M3_5
S4_height_M3_6
S4_height_M3_7
S4_height_M3_8
S4_height_M3_9
S4_intonation_M3x30_10
S4_intonation_washer_11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

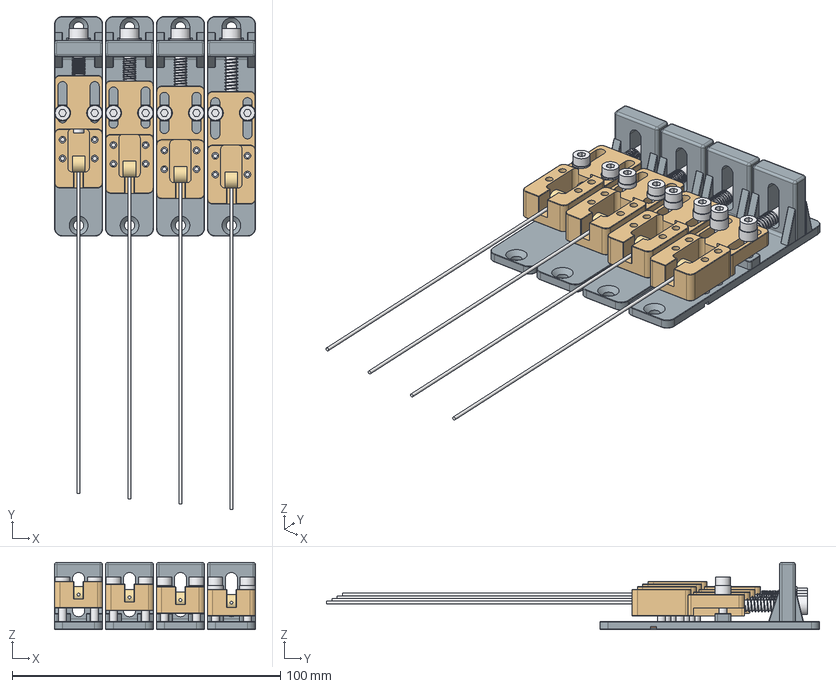
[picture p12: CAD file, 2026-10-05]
revisions/D/cad/step/MB4_assembly.step
75.0 x 184.0 x 25.0 mm
S1_B02_reinforced_base_0
S1_A03_strengthened_anchor_1
S1_clamp_washer_stack_2
S1_clamp_M3_3
S1_clamp_washer_stack_4
S1_clamp_M3_5
S1_height_M3_6
S1_height_M3_7
S1_height_M3_8
S1_height_M3_9
S1_intonation_M4x35_10
S1_intonation_washer_11
S1_compression_spring_REFERENCE_12
S1_string_reference_13
S1_ball_reference_ONLY_14
S1_piezo_envelope_ONLY_15
S2_B02_reinforced_base_0
S2_A03_strengthened_anchor_1
S2_clamp_washer_stack_2
S2_clamp_M3_3
S2_clamp_washer_stack_4
S2_clamp_M3_5
S2_height_M3_6
S2_height_M3_7
S2_height_M3_8
S2_height_M3_9
S2_intonation_M4x35_10
S2_intonation_washer_11
S2_compression_spring_REFERENCE_12
S2_string_reference_13
S2_ball_reference_ONLY_14
S2_piezo_envelope_ONLY_15
S3_B02_reinforced_base_0
S3_A03_strengthened_anchor_1
S3_clamp_washer_stack_2
S3_clamp_M3_3
S3_clamp_washer_stack_4
S3_clamp_M3_5
S3_height_M3_6
S3_height_M3_7
S3_height_M3_8
S3_height_M3_9
S3_intonation_M4x35_10
S3_intonation_washer_11
S3_compression_spring_REFERENCE_12
S3_string_reference_13
S3_ball_reference_ONLY_14
S3_piezo_envelope_ONLY_15
S4_B02_reinforced_base_0
S4_A03_strengthened_anchor_1
S4_clamp_washer_stack_2
S4_clamp_M3_3
S4_clamp_washer_stack_4
S4_clamp_M3_5
S4_height_M3_6
S4_height_M3_7
S4_height_M3_8
S4_height_M3_9
S4_intonation_M4x35_10
S4_intonation_washer_11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

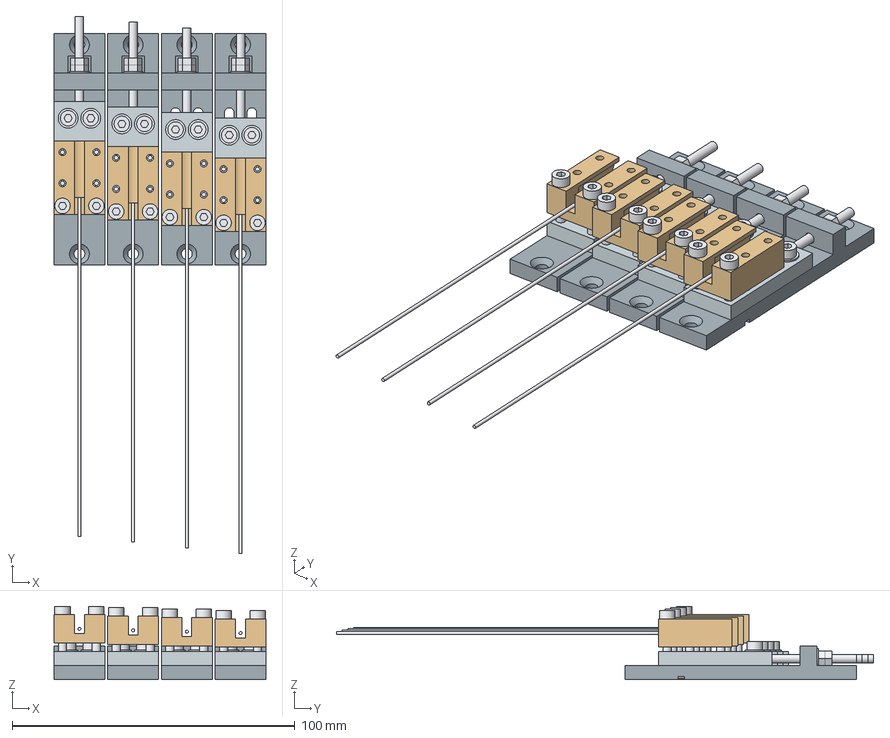
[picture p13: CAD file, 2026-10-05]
revisions/A/cad/step/MB4_assembly.step
75.0 x 190.0 x 26.0 mm
S1_B01_base_0
S1_C01_carrier_1
S1_A01_anchor_2
S1_slide_clamp_3
S1_slide_washer_4
S1_DIN562_nut_5
S1_slide_clamp_6
S1_slide_washer_7
S1_DIN562_nut_8
S1_height_M3x10_9
S1_height_M3x10_10
S1_hold_M3_11
S1_height_M3x10_12
S1_height_M3x10_13
S1_hold_M3_14
S1_intonation_M3x40_15
S1_intonation_washer_16
S1_intonation_nut_17
S1_intonation_jam_nut_18
S1_string_reference_19
S1_piezo_envelope_ONLY_20
S2_B01_base_0
S2_C01_carrier_1
S2_A01_anchor_2
S2_slide_clamp_3
S2_slide_washer_4
S2_DIN562_nut_5
S2_slide_clamp_6
S2_slide_washer_7
S2_DIN562_nut_8
S2_height_M3x10_9
S2_height_M3x10_10
S2_hold_M3_11
S2_height_M3x10_12
S2_height_M3x10_13
S2_hold_M3_14
S2_intonation_M3x40_15
S2_intonation_washer_16
S2_intonation_nut_17
S2_intonation_jam_nut_18
S2_string_reference_19
S2_piezo_envelope_ONLY_20
S3_B01_base_0
S3_C01_carrier_1
S3_A01_anchor_2
S3_slide_clamp_3
S3_slide_washer_4
S3_DIN562_nut_5
S3_slide_clamp_6
S3_slide_washer_7
S3_DIN562_nut_8
S3_height_M3x10_9
S3_height_M3x10_10
S3_hold_M3_11
S3_height_M3x10_12
S3_height_M3x10_13
S3_hold_M3_14
S3_intonation_M3x40_15
S3_intonation_washer_16
S3_intonation_nut_17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

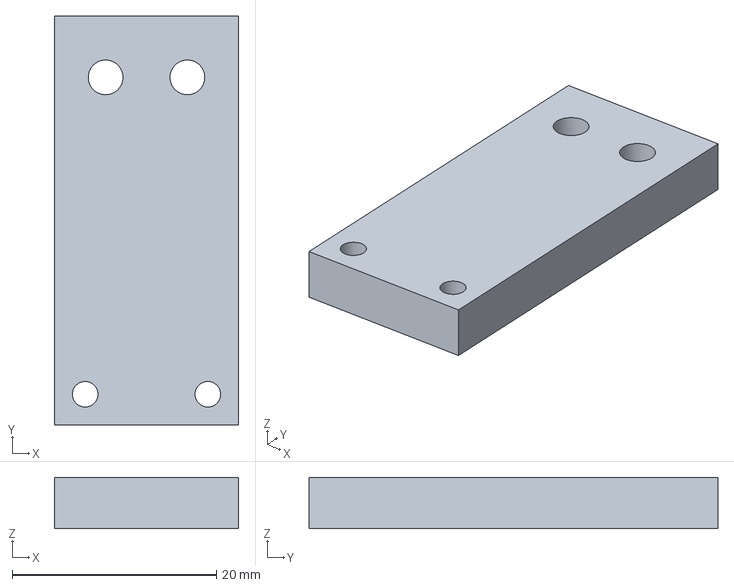
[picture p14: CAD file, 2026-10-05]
revisions/A/cad/step/C01_carrier.step
18.0 x 40.0 x 5.00 mm

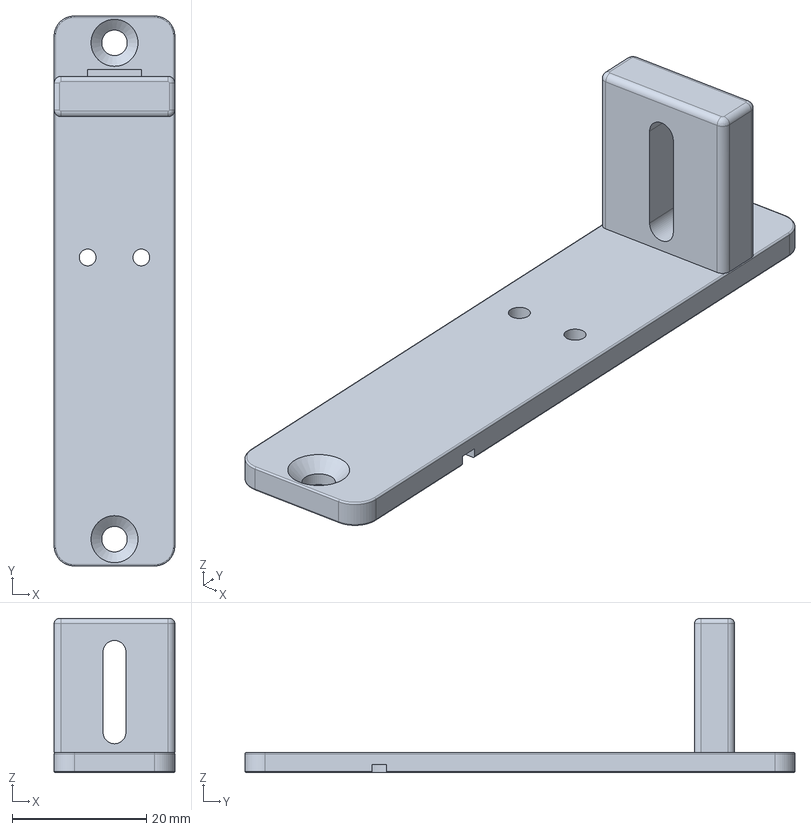
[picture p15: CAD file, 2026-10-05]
revisions/C/cad/step/B01_base.step
18.0 x 82.0 x 23.0 mm

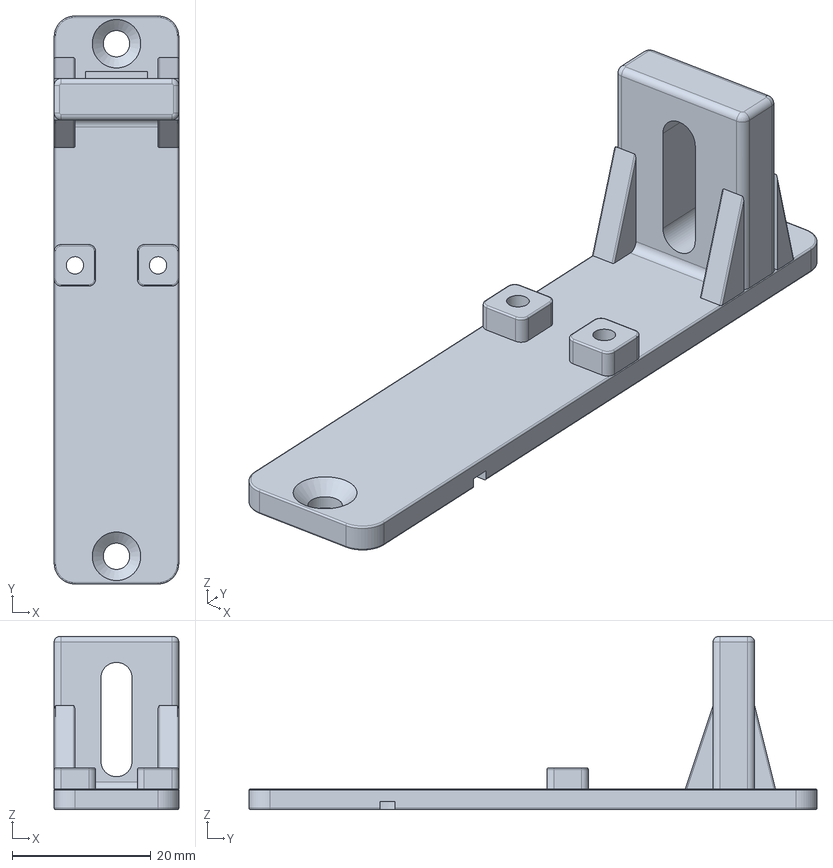
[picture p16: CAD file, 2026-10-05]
revisions/D/cad/step/B02_reinforced_base.step
18.0 x 82.0 x 25.0 mm

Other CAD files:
revisions/K/cad/step/MB4_assembly.step
revisions/J/cad/step/MB4_assembly.step
revisions/G/cad/step/MB4_assembly.step
revisions/L/cad/step/MB4_assembly.step
revisions/B/cad/step/C01_carrier.step
revisions/A/MB4_mount_template_1to1.dxf
revisions/A/cad/step/A01_anchor.step
revisions/A/cad/step/B01_base.step
revisions/B/MB4_mount_template_1to1.dxf
revisions/B/cad/step/A01_anchor.step
revisions/B/cad/step/B01_base.step
revisions/C/MB4_mount_template_1to1.dxf
revisions/C/cad/step/A02_integrated_anchor.step
revisions/D/MB4_mount_template_1to1.dxf
revisions/D/cad/step/A03_strengthened_anchor.step
revisions/E/MB4_mount_template_1to1.dxf
revisions/E/cad/step/A04_organic_anchor.step
revisions/E/cad/step/B03_organic_base.step
revisions/F/MB4_mount_template_1to1.dxf
revisions/F/cad/reference/RevE_A04_anchor.step
revisions/F/cad/reference/RevE_B03_base.step
revisions/F/cad/step/A05_crown_anchor.step
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

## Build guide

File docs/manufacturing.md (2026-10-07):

# 加工と調達 — Rev L

## CNCへ渡す2品

| 部品 | 材料・数量 | 加工データ |
| --- | --- | --- |
| B10ベース | 6061-T6、4個 | [STEP](../revisions/L/cad/step/B10_streamlined_base.step)、[英文加工図](../revisions/L/pdf/B10_streamlined_base.pdf) |
| A10アンカー | 6061-T6、4個 | [STEP](../revisions/L/cad/step/A10_sculpted_ball_anchor.step)、[英文加工図](../revisions/L/pdf/A10_sculpted_ball_anchor.pdf) |

[JLC見積用ZIP](../downloads/MB4_JLCCNC_upload_RevL.zip)にはこの4ファイルだけを収録しています。B10とA10を別々の品目として各4個で見積依頼します。全組立を表す`MB4_assembly.step`は切削対象として提出しません。

まず1弦分を実物評価する場合は各1個で見積依頼してください。Rev K以前のアンカーSTEP・図面は最新版の加工には使用しません。Rev LのB10ベースはRev KのB09と同形状です。保持部を変えたA10は新しい図面が必要です。

## 見積設定と図面の役割

材料はAluminum 6061-T6、単位mm、表面はAs-machined、ねじ加工はYESを想定します。一般寸法はISO 2768-m、図面で指定する機能軸・幅は±0.05 mm、ボディ座面平面度0.05 mm、Ra3.2目標です。詳細は各加工図が優先します。

STEPのねじ穴は下穴径で表現しています。M3下穴φ2.5、M4下穴φ3.3のまま納品する指示ではありません。加工図どおりM3×0.5-6H、M4×0.7-6Hに加工します。STEPは3D形状、同名PDFはねじ・寸法公差・仕上げ指示を担います。

[英文見積依頼文](../revisions/L/RFQ_JLC.txt)と[加工フィーチャー表](../revisions/L/features.csv)も参照してください。図面にはリブを削除しないこと、機能座面を研磨しないこと、指定逃げとRを維持することを記載しています。

## 球端保持部の加工

A10の保持座は幅8.2、Y6〜15、底Z2、前内隅R1.1、奥R4.1、入口R0.6です。上面から加工する開放ポケットとし、球端後方の細溝を削除しました。前の保持肩Y6、弦出口幅3.4・底Z3.3を保ちます。入口RはSTEPでモデル化しています。工具径と到達性は業者の審査で確認してください。球端・巻き部の実適合と表面接触は試作で評価します。

## 丸みと加工上の確認点

Rev Kから継続する外形は、丸い前部から低い後部へ滑らかにつながるBezier上面と、単純なアーチ支柱・曲線リブを持ちます。多重の膨らみ、追加の座ボスや中央の筋を設けません。ボールエンドミル等による3D仕上げパスは増えるため、従来と同じ加工費は想定しません。

M3固定は一段の後部平面Z8、高さ穴の入口はφ4.2・床Z8です。高さねじの軸をX±5.5/Y19・24へ調整し、入口が外周や隣の加工部へ欠けないようにしています。タップねじ領域Z0〜8と後壁の座金・ばね受け面、ボディ取付面とピエゾ接着面を保護します。

上面・下面・後端の加工段取りを想定します。後方M4はY55から−Yへ下穴経路12 mm、裏面開放窓へ抜けます。全周ねじ領域Y47〜55は8 mm、出口の一部ねじ壁もタップし、下面からバリ取りします。細い逃げ・リブ根元・曲面の工具到達と固定は業者へ審査依頼します。受託と価格は確定していません。

**JLCへ送信・見積確定・発注はしていません。** 保存図面は試作見積用です。設計・ねじガイドは2026-10-06に再読込、注文・材料ガイドは2026-10-05に確認したJLC公式資料は次のとおりです。最新条件は依頼時に確認してください。

- [CNC注文ガイド](https://jlccnc.com/help/article/cnc-machining-ordering-guidelines)
- [CNC設計ガイド](https://jlccnc.com/help/article/cnc-machining-design-guideline)
- [ねじ穴ガイド](https://jlccnc.com/help/article/threaded-hole-guideline)
- [Aluminum 6061](https://jlccnc.com/help/article/aluminum-6061-cnc-machining)

## 市販金物

数量と高さによる長さの選択は[部品表](../revisions/L/BOM.csv)、[購入候補表](../revisions/L/MISUMI_purchase_options.csv)、[参照元と選定理由](../revisions/L/hardware_sources.txt)に記載しています。

| 用途 | Rev Lの候補 | 4弦分 |
| --- | --- | --- |
| 後方調整ねじ | NBK SNSS-M4-45-FT／ミスミSNSS-M4X45-FT、M4×45全ねじ | 4本 |
| 後方座金 | WSJS-SUS-M4、外径8・厚さ0.5 | 4枚 |
| 圧縮ばね | UY6-35、SUS304-WPB、外径6・自由長35 | 4個 |
| 高さ調整 | MSSFS4-8/12/16、M4平先 | 使用高さで計16本 |
| 固定ねじ | SSBCB3-12/16/20、25 mmのみSBCB3-25 | 計8本 |
| 固定座金 | WSJS-SUS-M3、外径6・厚さ0.5、必要枚数を積層 | 高さによる |
| ボディ木ねじ | ステンレス皿3.5×20候補、頭φ7以下・90° | 8本 |

後方ねじを半ねじM4×45で代用すると、非ねじ部がアンカーへ入り成立しません。ばねも長さだけで置換せず、外径・線径・許容たわみと自由長公差を確認します。表中の金物はステンレスですが、鋼種や強度区分は品番ごとに異なります。

購入候補表の価格確認日は2026-10-05です。新しい後方全ねじとUY6-35の現在の見積価格は未取得です。過去版の価格・品番を最新版へ読み替えないでください。

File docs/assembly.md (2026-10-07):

# 組立と調整 — Rev L

図で確認する場合は[4ページの組立ガイド](../revisions/L/pdf/MB4_RevL_guide.pdf)と[6面プレビュー](../revisions/L/six_views/MB4_RevL_six_views.png)を参照してください。

## 組立順序

1. 実機のネック・弦間・必要な弦高・スケール補正量を測り、取付位置を決めます。[原寸DXF](../revisions/L/MB4_mount_template_1to1.dxf)を使い、印刷する場合は50 mmの確認枠を測ります。木部の厚さ、空洞、既存穴、ボディ端の余白も確認します。
2. ピエゾを使う場合は金属裏面の窪みへ接着し、必要な配線経路を確保します。素子・接着・配線の総厚を1.2 mm以下にし、木部と挟み込みません。
3. **アンカーと後方調整ボルトを付ける前に、前後の木ねじでベースを固定します。** 前木ねじはアンカーの下、後木ねじの工具域は調整ボルト頭と重なります。皿頭を座面Z3に完全に収めます。
4. 高さM4平先4本をアンカーへ入れ、ベース上で4本とも支持するように合わせます。
5. ばね・後方M4×45全ねじ・後方座金を組み、固定M3ねじ2本と座金を長穴に通します。
6. 使用する実弦の球端と巻き部が保持ポケットに適合することを確認して装填します。弦を緩めた状態で高さ・前後位置を調整し、固定してチューニングします。

ピエゾを付けない状態でも機械部は組み立てられます。使用する木ねじや木部下穴はボディの材質・厚さ・既存穴を踏まえて決めます。金属のφ3.8穴は木部の下穴径ではありません。

球端は上から保持座に入れ、前方の肩へ寄せて弦張力で保持します。参考モデルでは中心Y11からY9への着座経路を確認しています。球端を締め付ける専用ねじはありません。使用弦の球端・巻き部が入ることと、前方出口で弦を傷めないことを試作で確認します。無張力では上から取り出せます。

## 高さ調整

参考弦中心は`8 + g` mmです。高さ調整はX±5.5/Y19・24にある4本の平先を均等に当て、M3固定ねじを緩めて行います。高くするほど長い高さねじ・固定ねじと座金厚の変更が必要です。

| 隙間g mm | 参考弦中心 mm | 高さM4長さ mm | 固定M3長さ mm | 固定座金合計厚 mm |
| --- | --- | --- | --- | --- |
| 0 | 8 | 8 | 12 | 1.5 |
| 2 | 10 | 8 | 16 | 3.5 |
| 4 | 12 | 8 | 16 | 1.5 |
| 6 | 14 | 12 | 20 | 3.5 |
| 8 | 16 | 12 | 20 | 1.5 |
| 10 | 18 | 16 | 25 | 4.5 |
| 12 | 20 | 16 | 25 | 2.5 |

表は公称寸法の例です。固定ねじ先端は`Z = 11 + g + 座金合計厚 − ねじ長さ`で計算します。ガイドでは先端Z0.2〜0.7を目安とし、例はZ0.5です。実物のねじ長・座金厚を測り、ベース下面から木部へ突出させません。座金やスペーサの外径は6 mm以下とします。

## オクターブ調整

弦を緩め、長穴のM3固定ねじ2本を緩めてから、後方M4を回します。締めるとエンド側へ引き、緩めるとばねが前方へ押します。M4×0.7なので公称1回転0.7 mm移動します。調整後にM3を固定し、再チューニングしてオクターブを確認します。

アンカー前端`q = −15〜5`が設計調整域です。前方限界で15 mm張り出すため、弦張力を掛ける前に周辺との干渉を確認します。参考肩位置は`q + 6`ですが、必要なスケール補正量を全弦同じとは考えません。

UY6-35の公称作動長は30.5〜10.5 mmです。自由長公差±1.5 mmの長い側では最大たわみ26.0 mm、許容26.25 mmまでの余裕は公称0.25 mmです。実物のばね・座面を測り、許容を超える場合は端位置を制限します。密着するまで締め込みません。

## 脱着と実物評価

ベースを外す際は、先に弦を緩め、アンカーと後方ボルトを外して木ねじに工具を届かせます。締付トルクはこの設計では確定していません。

初回の試作では、球端保持、4本の高さ足の接地、タップ掛かり、調整の全域、木ねじ保持、緩み・変形、ピエゾ感度と弦間の回り込みを確認します。CADの干渉確認だけで実機の耐久性が確定するものではありません。

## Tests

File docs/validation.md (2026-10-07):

# 検証記録と未評価事項

## Rev Lで確認したこと

| 確認項目 | 方法・記録 |
| --- | --- |
| 参考球端の装着・保持 | 外径6・幅4.75の円筒で、上からの挿入とY11→9の着座移動、前方への抜け止め、弦出口を確認。実弦適合は未確認 |
| ベースの継続 | Rev K B09とRev L B10の両方向Boolean差分体積0。品番・版を揃えた同形状 |
| CNC部品の有効性 | B10/A10各1ソリッド。STEP再読込、両方向の差分体積1e−6 mm³未満、外形座標差1e−5 mm未満。曲面の体積数値積分差は診断値として記録し、形状一致は差分と外形で判定 |
| 組立参考モデル | 64ソリッドの組立 |
| 位置・高さの組合せ | q=−15/−5/5とg=0/6/12の9条件で部品・金物・ばね外径包絡の干渉を確認 |
| 移動途中の確認 | 輸出STEPをq=−15〜5、1 mm刻み21位置、g=0で検査 |
| 高さの支持 | 全4本のφ4平先の全面接地を確認 |
| 長穴と後方ねじ | M3が連続長穴を通ること、長さ45.5 mm側の後方ねじが当たらないことを確認 |
| 入口の縁 | 高さ穴の入口床周囲0.5 mmの連続材料を確認 |
| 穴と材料 | 実下穴、指定タップ主径の周囲0.8 mm材料ガード、リブ根元の材料連続性 |
| 金物の高さ選択 | g=0〜12を0.01 mm刻みの1201点で選択・先端位置を確認 |
| 流線形部の機能座 | M3平面座を5位置で、後壁の座金座・ばね座を3高さで接触確認 |
| 木ねじと工具 | 皿頭の包絡と、アンカー・後方ボルトを付ける前の工具域を確認 |

元の記録：[geometry_check.json](../revisions/L/cad/geometry_check.json)、[travel_sweep_check.json](../revisions/L/cad/travel_sweep_check.json)。検査ソース：[build_bridge.py](../revisions/L/cad/build_bridge.py)、[verify_travel.py](../revisions/L/cad/verify_travel.py)。

ねじの噛合いに相当する指定主径領域は、干渉判定から除外しています。ばねは外径包絡と作動長で確認し、レンダーの螺旋は参考形状です。21位置の確認と直線長穴の寸法関係に基づく検証であり、全位置の荷重下の挙動を実測した結果ではありません。

凸曲面・フィレットのSTEP再パラメータ化で、体積の数値積分結果に微小差が生じます。そのためRev Lも積分値だけでなく、元ソリッドと再読込STEPの両方向のBoolean差分と外形座標も検査しています。積分公差を厳しくしても、曲面の数値積分差が残る場合があります。両方向の形状差分を確認します。合否は有効な差分体積と外形で判定し、積分値の差だけで同一形状を否定しません。結果をgeometry_check.jsonに記録します。

## 未評価の事項

- 特定のJazz/P Bassボディへの取付位置・高さ・穴・空洞・木部厚。
- 使用する弦の球端、巻き部分、弦軸と保持肩の接触状態。
- 荷重下の剛性、応力集中、疲労、アルミねじと木ねじの保持、緩み。
- ピエゾの品番、接着方法、出力、周波数特性と弦間の振動の回り込み。
- JLCの工具到達性・固定方法・加工可否・価格・納期。

球端保持部を変更したRev Lの強度は未検証です。CNC形状とねじ周辺の材料が残ることは確認していますが、強度保証と同じ意味ではありません。

## リポジトリと配布ZIPの整合性

`python3 tools/check_repository.py`で、ローカルMarkdownリンク、各版の保存ファイルのSHA-256、Rev L見積ZIPと元STEP/PDFの一致、ZIPのCRC、12版の揃いを確認できます。これは資料と配布ファイルの整合性確認です。

`python revisions/L/cad/verify_travel.py`はCadQueryが必要なCAD確認です。ソースを変更した場合はSTEPを再生成してから検査します。CADを変更していない資料整理だけで、すべての歴史的版の強度計算や加工見積をやり直したと解釈しません。

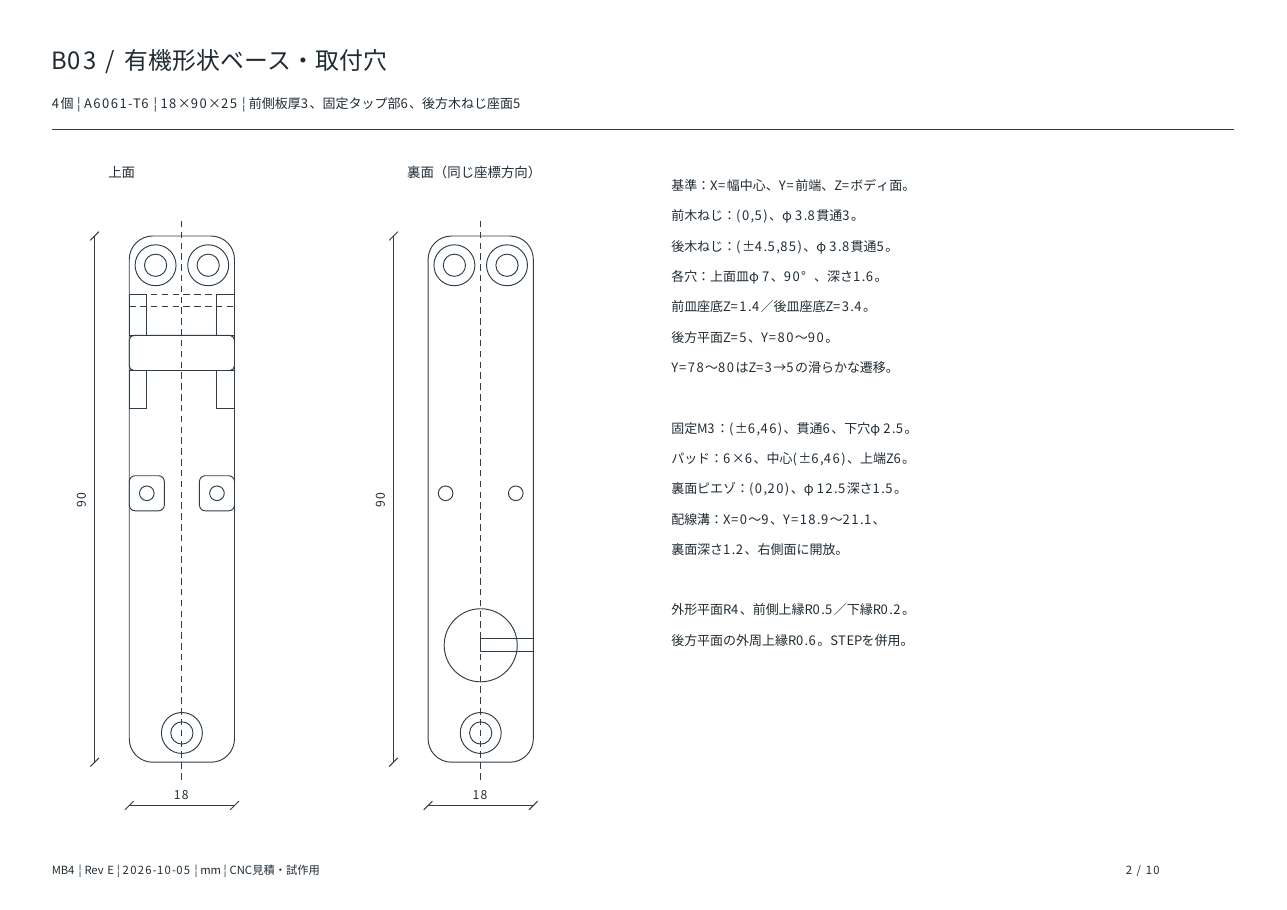
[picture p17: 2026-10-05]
revisions/E/pdf/qa/page-02.png

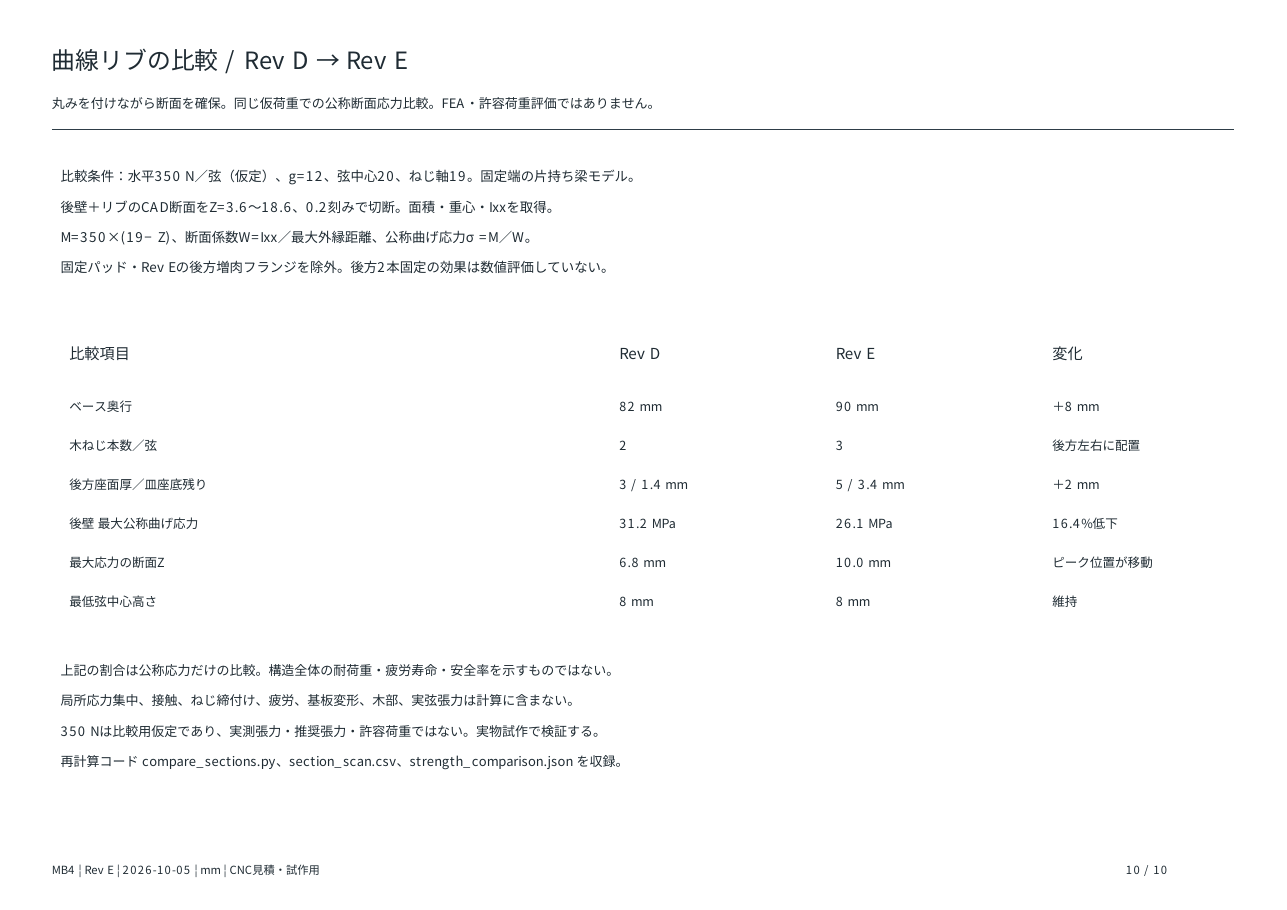
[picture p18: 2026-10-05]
revisions/E/pdf/qa/page-10.png

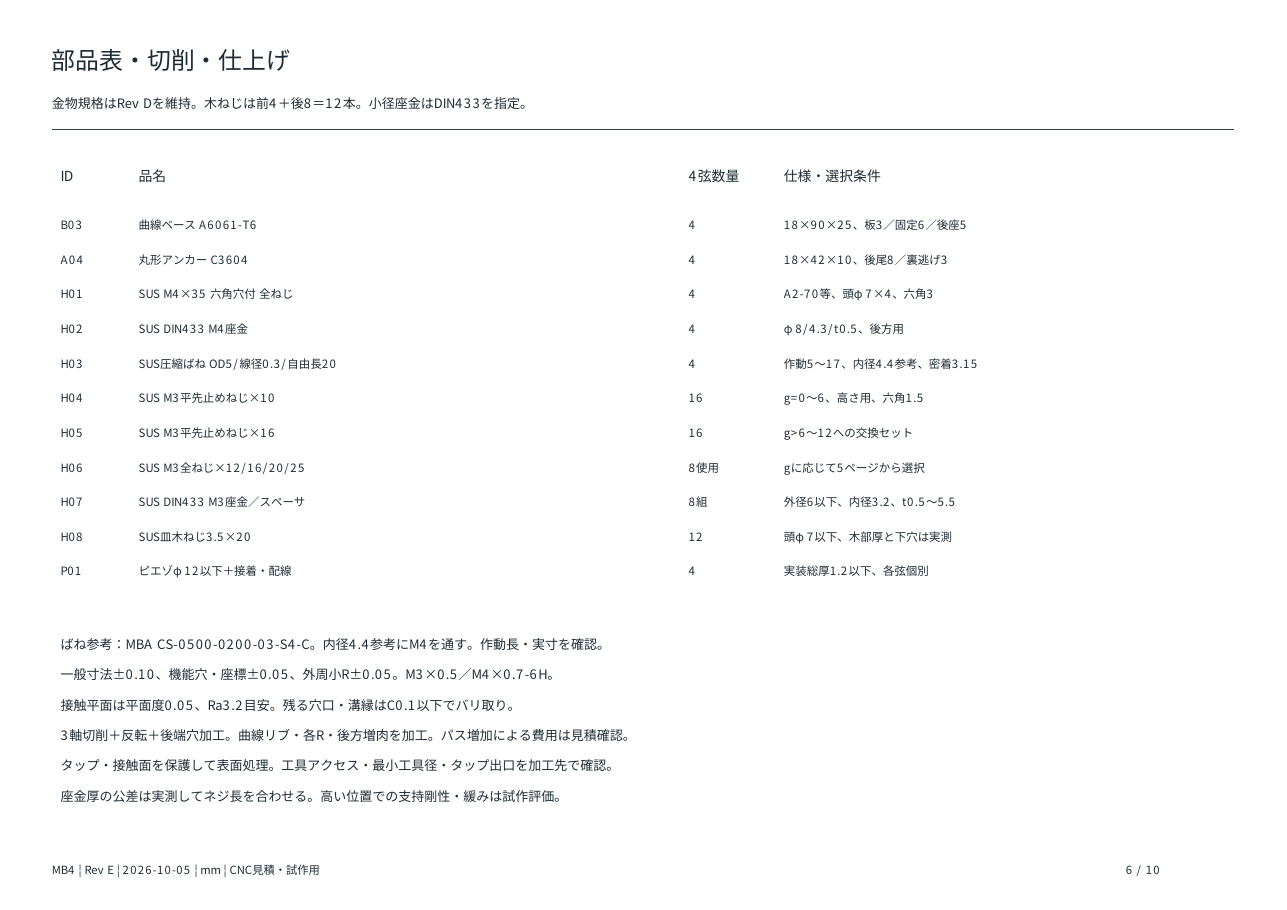
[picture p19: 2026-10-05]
revisions/E/pdf/qa/page-06.png

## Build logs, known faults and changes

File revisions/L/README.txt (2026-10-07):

MB4 Rev L / refined ball-end cradle / 2026-10-07 / mm

ボールエンド保持部の再設計版。B10_streamlined_baseとA10_sculpted_ball_anchor。
6061-T6、各4個。B10はRev KのB09と同じ形状、版と品番を揃えて再出力。
最新版STEPと同名英文PDFを併用し、旧版のアンカー図面と混ぜない。

保持部
角丸四角形の窪みを、前に平らな保持肩、奥に大きな半円を持つカプセル座へ変更。
幅8.2、前Y6、奥Y15、前の内隅R1.1、奥R4.1（中心Y10.9）。
上面との境界は実形状のR0.6でつなぐ。底Z2、前の保持肩Y6を維持。
弦出口は幅3.4、底Z3.3、Y-2..8の前方だけ。球端の後方へ延びる不要な細溝を削除。
球端は上からY11へ入れ、前のY9へ寄せる。押さえねじで締め付ける構成ではない。
参考球端は外径6・横幅4.75の円筒、軸X、着座中心Y9/Z5。
実際の弦の球端・巻き部寸法は未確定で、互換性と実接触は実弦で確認が必要。
参考モデルの縦挿入、前への移動、保持肩による前方抜け止め、前方弦出口をCAD確認。
無張力時の球端脱落防止や完全な把持を保証するものではない。

継続仕様
ベース18x86x25、アンカー18x55x最高10.5、弦間19、全幅75。
参考弦中心8..20、オクターブ20mm(q=-15..5)、最前位置全長101mm。
高さ穴X+/-5.5/Y19・24、入口D4.2・床Z8、M4タップ深さ8。
木ねじX0/Y8・81、ピエゾX0/Y24、各弦2穴。裏窓と市販金物はRev Kと同じ。
後壁は厚6のR9アーチ、縁R1.2。3mmの曲線リブ、外R0.8、内縦根元R2。
金物M4x45全ねじ、UY6-35、M4平先、M3ボタン頭は従来の候補を継続。
CAD9条件、STEP21移動位置、ねじ肉厚、足の接地、座面・入口床の材料、再読込を確認。
実物強度/疲労・球端適合・ピエゾ性能・JLC工具アクセス/受託/価格は未確認。
加工費と工具の到達性は、STEPと対応図面で手動見積審査を依頼。

再生成
python cad/build_bridge.py
python cad/verify_travel.py
blender --background --python-exit-code 1 --python cad/render_bridge.py
blender --background --python-exit-code 1 --python cad/render_ball_cradle.py
blender --background --python-exit-code 1 --python cad/render_six_views.py
python cad/compose_six_views.py
python cad/make_documents.py
python cad/package_outputs.py

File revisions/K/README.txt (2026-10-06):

MB4 Rev K / streamlined exterior, intact access mouths / 2026-10-06 / mm

B09_streamlined_baseとA09_streamlined_anchor。6061-T6、各4個。
STEPと同名英文PDFを併用し、旧版と混ぜない。
上面は複数の膨らみを重ねず、前側の丸みから低い後部まで一枚の滑らかな面にする。
前側上面Z=7.8+2.7*(1-(X/9)^2)、Y0..21。後部上面Z8。
Y21..27.8はt=(Y-21)/6.8、G=1-3t^2+2t^3、
Z=8+G*(-0.2+2.7*(1-(X/9)^2))。両端で傾きが滑らかにつながる。
先端の円柱クラウン、後部の盛り上がった筋、個別の固定座段差は設けない。
外周上縁R0.7・下縁R0.6。取付面・固定座・ねじ走行面・接着面は平面を保護。

支柱は単純なR9アーチ、厚6、頂部Z25、前後縁R1.2。追加の座ボスはない。
リブは幅3で一続きの三次曲線。内側縦根元R2、外稜線R0.8、内稜線C0.2 MAX。
前リブ(Y,Z)：(64,3),(68,3),(71.5,11),(72.5,16)。
後リブ：(81.5,5),(79.5,5),(75.5,11),(74.5,16)。STEPが正。
固定パッド根元はZ2まで底板へ重ね、パッド下の縁Rによる隙間を埋める。
底板上縁R0.8は自由縁に続く。支持の根元下に装飾的な溝は作らない。

穴の欠け対策
アンカーの左右輪郭のくびれをなくし、高さ穴をX+/-5.7から+/-5.5へ内側へ移動。
後列はY25からY24へ。穴はY19・24。上面の入口D4.5からD4.2、床Z8。
高さタップM4x0.7-6HはZ8からZ0の8mmを維持。入口床周囲に0.5mmの材料をCAD確認。
固定長穴への接続・外縁の欠けを避け、穴間と外周に肉を残す。

ベース18x86x25、アンカー18x55x最高10.5、弦間19、全幅75。
参考弦中心8..20、オクターブ20mm(q=-15..5)、最前位置全長101mm。
木ねじX0/Y8・81、ピエゾX0/Y24、各弦2穴。金物・球受け・裏窓を維持。
金物M4x45全ねじ、UY6-35、M4平先、M3ボタン頭はRev Jの候補を継続。
CAD9条件、STEP21移動位置、ねじ肉厚、足の接地、座面と入口床の材料、再読込を確認。
実物強度/疲労・球端適合・ピエゾ性能・JLC工具アクセス/受託/価格は未確認。
曲面加工パスは増える。CNCの加工費を従来同等とは想定せず手動見積審査を依頼。

再生成
python cad/build_bridge.py
python cad/verify_travel.py
blender --background --python-exit-code 1 --python cad/render_bridge.py
blender --background --python-exit-code 1 --python cad/render_six_views.py
python cad/compose_six_views.py
python cad/make_documents.py
python cad/package_outputs.py

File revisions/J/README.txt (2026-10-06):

MB4 Rev J / rounded exterior, 20 mm travel / 2026-10-06 / mm

Rev Iの機構と取付位置を維持し、外周と後壁・リブ・アンカーの稜線を丸めた試作改訂。
加工対象：B08_rounded_baseとA08_rounded_anchor。6061-T6、各4個。
単品STEPと同名英文PDFを併用。Rev Iの加工図とは混ぜない。

外形の変更
後壁アーチの前後縁：C0.25からR1.2。
リブ外側の斜辺：C0.25からR0.8。内側の斜辺：R0.5を追加。
自由な前板上縁：C0.25からR0.5。下面外縁R0.2と後端R0.9は維持。
アンカー上縁R0.8からR1.2、下縁R0.4からR0.6。
クラウン上縁R1.0からR1.2、根元R0.8からR0.6。
高さ2 mmのクラウン内で上縁と根元のRを重ねない組合せ。
リブの基本形は平面のまま。二次曲線の膨らみ・段差・根元下の溝は設けない。

維持する寸法
ベース18x86x25、アンカー18x55x最高10、弦間19、全幅75。
オクターブ20 mm（q=-15..5）、参考弦中心8..20（g=0..12）。
最前位置の前方張り出し15 mm、モジュール全長101 mm。
木ねじX0/Y8・81、裏面ピエゾX0/Y24、取付は各弦2穴、計8穴。
M4高さX+/-5.7/Y19・25、M3長穴X+/-6/Y41、固定パッドY36。
後壁Y70.5..76.5、幅3のリブ、壁との内角R2を維持。
球受け、保持肩、長穴、裏窓、ねじ座、接着面を機能寸法として保護。
金物はRev Iと共通：SNSS-M4X45-FT全ねじ、UY6-35、M4平先、M3ボタン頭。

組立
アンカーと後方ボルトを付ける前に前後の木ねじでベースを固定する。
球端や巻き部の実物で適合と弦中心を確認。調整時は弦とM3固定を緩める。
ピエゾはphi12以下、接着配線込み厚1.2以下、金属裏へ接着し木部と挟まない。
具体的な加工受託・価格・実機強度・疲労・ピエゾ分離度は未確認。

再生成
python cad/build_bridge.py
python cad/verify_travel.py
blender --background --python-exit-code 1 --python cad/render_bridge.py
blender --background --python-exit-code 1 --python cad/render_six_views.py
python cad/compose_six_views.py
python cad/make_documents.py
python cad/package_outputs.py
Python依存はcad/requirements.txt。生成後は同じ版のSTEP・図面・プレビューを確認。

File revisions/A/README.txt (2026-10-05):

MB4 / 4弦独立サドルレス・ブリッジ 試作設計 Rev A
================================================
用途：汎用ジャズベ／プレベを想定した、新規取付穴を使う試作。
弦間19 mm。既存Fender系5穴への互換性はありません。
完成品寸法・実弦・木部の状態を確認する前の量産発注用ではありません。
まずPDFの1ページ目と、仕様・組立手順をご覧ください。

cad/step/ の部品STEP 3種類を各4個ずつ加工します。
ねじ穴はCAD上では下穴径。M3x0.5の指示はPDFとfeatures.csvが優先します。
STEPはmmのソリッドです。STLとblendは説明・表示用で、CNCの加工原本ではありません。
assembly STEPには市販金物の簡略形状とピエゾの参考外形を含みます。
弦高はボディ表面から15-20 mmを想定。弦の実際の支点はボールエンド／巻き部分で
変わるため、最後は実弦で高さ・オクターブを測ります。

cad/parameters.json と cad/build_bridge.py が再生成用ソースです。
python -m venv .venv
.venv/bin/pip install -r cad/requirements.txt
.venv/bin/python cad/build_bridge.py
弦間はparameters.jsonで変更できます。その他寸法を変える際は、穴座標・逃げ寸法も
build_bridge.pyとPDF生成用ソースで合わせて更新してください。

加工のポイント：ベース／キャリッジはA6061-T6、アンカーは快削黄銅C3604。
3軸フライス＋反転＋側面の穴加工で作成。旋盤専用部品、5軸加工、特殊なリングは不要。
ただしM3下穴・長穴には細径工具を使います。必ず加工業者に保持方法を含めて見積依頼。
各弦のピエゾは接着型の接触センサ用。張力を薄いセラミックに直接負担させません。
ピエゾ品番・接着層・出力・分離度は未確定。ポケットはφ12以下の参考外形用です。

納品物：PDF図面、部品／組立STEP、原寸DXF、部品表CSV、穴・加工フィーチャーCSV、
再生成ソース、Blender表示モデル、外観PNG、geometry_check.json。
PDFで示す組立寸法・標準金物寸法を参照。ソリッド整合性と可動限界の干渉は確認済。
実機取付、強度保証、音質保証、完全な各弦分離、CAM工具経路の保証は含みません。
ボールは外径6 mm、厚さ4.75 mmを参考にφ8の穴を設計。
上側スリットから抜けないため、ボールの最小厚さ3.8 mm以上を想定します。
この寸法は全メーカー共通の保証値ではありません。使用する弦で必ず確認してください。

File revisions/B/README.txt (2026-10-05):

MB4 / 4弦独立サドルレス・ブリッジ 試作設計 Rev B
================================================
用途：汎用ジャズベ／プレベを想定した、新規取付穴を使う試作。
弦間19 mm。既存Fender系5穴への互換性はありません。
完成品寸法・実弦・木部の状態を確認する前の量産発注用ではありません。
外周にRを追加した改訂版です。まずPDFの1ページ目と9ページ目をご覧ください。

cad/step/ の部品STEP 3種類を各4個ずつ加工します。
ねじ穴はCAD上では下穴径。M3x0.5の指示はPDFとfeatures.csvが優先します。
STEPはmmのソリッドです。STLとblendは説明・表示用で、CNCの加工原本ではありません。
assembly STEPには市販金物の簡略形状とピエゾの参考外形を含みます。
弦高はボディ表面から15-20 mmを想定。弦の実際の支点はボールエンド／巻き部分で
変わるため、最後は実弦で高さ・オクターブを測ります。

cad/parameters.json と cad/build_bridge.py が再生成用ソースです。
python -m venv .venv
.venv/bin/pip install -r cad/requirements.txt
.venv/bin/python cad/build_bridge.py
弦間はparameters.jsonで変更できます。その他寸法を変える際は、穴座標・逃げ寸法も
build_bridge.pyとPDF生成用ソースで合わせて更新してください。

加工のポイント：ベース／キャリッジはA6061-T6、アンカーは快削黄銅C3604。
3軸フライス＋反転＋側面の穴加工で作成。旋盤専用部品、5軸加工、特殊なリングは不要。
ただしM3下穴・長穴には細径工具を使います。必ず加工業者に保持方法を含めて見積依頼。
各弦のピエゾは接着型の接触センサ用。張力を薄いセラミックに直接負担させません。
ピエゾ品番・接着層・出力・分離度は未確定。ポケットはφ12以下の参考外形用です。

納品物：PDF図面、部品／組立STEP、原寸DXF、部品表CSV、穴・加工フィーチャーCSV、
再生成ソース、Blender表示モデル、外観PNG、geometry_check.json。
PDFで示す組立寸法・標準金物寸法を参照。ソリッド整合性と可動限界の干渉は確認済。
実機取付、強度保証、音質保証、完全な各弦分離、CAM工具経路の保証は含みません。
ボールは外径6 mm、厚さ4.75 mmを参考にφ8の穴を設計。
上側スリットから抜けないため、ボールの最小厚さ3.8 mm以上を想定します。
この寸法は全メーカー共通の保証値ではありません。使用する弦で必ず確認してください。

Rev Bの追加形状：
ベース外周四隅R3、キャリッジ／アンカー外周四隅R2、外周の上下稜線R0.2。
後壁の四隅R1.5、上面外周R1。アンカー上側のスリット長辺にR0.2。
これらのRは加工用STEPに含まれます。外周平面Rは輪郭加工、稜線Rは仕上げパスを追加。
主要穴・溝の寸法と、座面・弦保持肩・ピエゾ接着面の高さはRev Aから維持。
残る穴口等はC0.1以下でバリ取り。PDFとfeatures.csvの指定Rは省略しないでください。
2D図では小Rと側面Rの遷移を簡略表示しています。STEPとR一覧を合わせて参照。

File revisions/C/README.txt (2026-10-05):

MB4 Rev C - 4弦独立・低弦高・ネジ＋バネ・サドルレス試作
2026-10-05 / mm

変更点
・設計弦中心高さ8〜20 mm（Rev Bは15〜20 mm）。ベース板厚3＋ボール軸5＋隙間g。
・1弦の切削部品をベースB01と一体アンカーA02の2点に統合。
・後方M3×30全ねじと標準SUS圧縮ばねで前後12 mm調整。
・高さ追従の後壁縦長穴。後壁全高23 mmは弦中心高さとは別。
・ボールを上から入れる8×16開放ポケットにし、横φ8穴の加工を廃止。
・外周R3/R2、外周稜線R0.2、後壁外形R1・上面R0.8をSTEPに反映。
・各弦ピエゾ用の裏面φ12.5窪み・配線溝を維持。

同梱
cad/step/B01_base.step：アルミ固定ベース、数量4。
cad/step/A02_integrated_anchor.step：黄銅一体アンカー、数量4。
cad/step/MB4_assembly.step：4弦全体、汎用金物と参考弦・ボール・ピエゾを含む。
pdf/MB4_design_and_drawings.pdf：8ページの寸法・調整・部品表・原寸取付図。
BOM.csv / features.csv / RFQ.txt：調達と加工先への指示。
MB4_mount_template_1to1.dxf：mm・原寸取付配置。
cad/MB4_RevC_preview.blend / bridge_preview.png：外観確認用。
cad/build_bridge.py / parameters.json / geometry_check.json：再生成・設計値・検証記録。
STLは外観用。CNC見積にはSTEPと図面、加工指示を一緒に送る。

加工
ねじはモデリングせず下穴φ2.5を表現。M3×0.5-6Hのタップ加工が必要。
ベース取付穴φ3.8は木部下穴ではない。木部厚・材質に応じて下穴を決める。
一般寸法±0.10、機能穴・座標±0.05、平面度0.05、Ra3.2目安。
加工先で工具アクセスとタップ有効長を確認。最初は1弦分の試作を推奨。

金物・調整
高さg=0〜6：M3平先×10。g>6〜12：M3平先×16へ交換（4本とも）。
固定はM3全ねじ2本／弦。L10/12/16/20/25から高さに合わせる。
座金・標準スペーサの合計厚tを調整：先端Z=9＋g＋t−Lが0.2〜0.7。
金物厚の公差を実測して木部へ突出させない。最小タップ掛かり2.3 mm。
ばねOD5・線径0.3・自由長20・密着長3.15・作動長5〜17・定数0.1 N/mm。
参考MBA CS-0500-0200-03-S4-C。同じ外形だけで異なる線径のばねに置換しない。
CADばねは定ピッチ参考形状。閉じ端と購入品の実寸・荷重曲線は現物確認。
ネジを締めると後へ引き、緩めるとばねが前へ押す。バネは弦張力を負担しない。
弦を緩めて高さとオクターブを調整し、最後に固定ねじ2本を軽く締める。

取付
弦間19 mm、全幅75、各ベース18×82、X=-28.5/-9.5/9.5/28.5。
各弦取付穴Y=4,78。既存5穴とは非互換、新規穴あけ用。
アンカー前端q=8〜20、保持肩Y=14〜26。
前端位置はナットからスケール長−16 mmを初期候補とし実弦で補正範囲を確認。
配線落とし穴候補は各弦X+7,Y20,φ3。内部配線と干渉を確認して決定。

検証と限界
9条件で切削部品・金物の干渉、STEP再読込を確認（ねじの噛合い部を除く）。
0〜12 mmの高さ1201点で固定ねじ先端Zを確認。
参考φ6×厚4.75のボールでポケット5位置の装填・移動の干渉を確認。
8 mmはこの参考ボール中心の設計値。実弦のボール・巻き形状で変わり得る。
既存J/Pボディへの取付、張力・疲労強度、音響・ピエゾ出力は未検証。
各ピエゾを接着し個別バッファで読み出す。木部を介するクロストークは残る。

再生成
Python環境にcad/requirements.txtをインストール。
python cad/build_bridge.py
blender --background --python-exit-code 1 --python cad/render_bridge.py
python cad/make_documents.py
parameters.jsonは設計値の一覧。一部はコード内の固定寸法であり、全寸法の自動変更には未対応。

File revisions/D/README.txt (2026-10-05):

MB4 Rev D - 補強・低弦高・各弦独立サドルレスブリッジ試作
2026-10-05 / mm

Rev Cからの補強
・後壁左右に前後各2本、計4本の三角リブを一体切削。中央前根元R1。
・固定M3タップを厚さ6のパッドに移し、掛かりを2.3〜2.8から5.3〜5.8 mmへ。
・固定長穴をX±4からX±6へ移し、アンカー中央の連結部を幅広にする。
・後尾高さを6から8へ、後方調整ネジをM3からM4×35全ねじへ。
・アンカー裏面に深さ3の逃げを設け、ベース増肉を避けて弦中心8〜20を維持。
・後壁高さ23から25へ。M4座金の支持面を最高弦高まで確保。
・1弦あたり切削部品2個。前後調整12、ネジ＋バネ、外周R、ピエゾ用窪みを維持。

主な寸法
ベースB02：A6061-T6、18×82×25。前部板厚3、固定タップ部厚さ6。
アンカーA03：C3604、18×42×10、後尾高さ8。
弦間19、全幅75、各弦X=-28.5/-9.5/9.5/28.5。
木部取付穴は各弦(0,4),(0,78)金属φ3.8、上面皿座φ7 90°。
既存J/Pの5穴とは非互換。新規穴あけ位置は実機で決定。
アンカー前端q=8〜20、保持肩Y=q+6=14〜26。
前端位置はナットからスケール長−16を初期候補とし実弦で補正範囲を確認。

ファイル
cad/step/B02_reinforced_base.step：各4個。最初の試作は1個。
cad/step/A03_strengthened_anchor.step：各4個。最初の試作は1個。
cad/step/MB4_assembly.step：全体、参考金物・弦・ボール・ピエゾ付き。
pdf/MB4_design_and_drawings.pdf：9ページの加工図・調整・部品・補強比較。
BOM.csv / features.csv / RFQ.txt：調達・加工指示。
MB4_mount_template_1to1.dxf：原寸mm取付パターン。
bridge_preview.png / cad/MB4_RevD_preview.blend：外観確認。
cad/build_bridge.py / parameters.json / geometry_check.json：再生成・寸法・検査記録。
cad/compare_sections.py / strength_comparison.json / section_scan.csv：比較計算。
cad/reference/RevC_B01_base.step：比較用旧形状のみ、発注対象ではありません。
STLは表示用。CNC発注は個別STEPとPDF、RFQ、features.csvを併用。

加工
STEPはM3下穴φ2.5／M4下穴φ3.3の表現。M3×0.5-6H、M4×0.7-6Hへタップ。
基本は3軸切削＋反転＋後端穴加工。追加はリブ斜面・根元R・増肉・裏面逃げのパス。
一般寸法±0.10、機能穴・座標±0.05、小R±0.05、接触平面平面度0.05、Ra3.2目安。
残る穴口と溝縁C0.1以下バリ取り。前肩と機能座面を削り過ぎない。

汎用金物
後方：SUS M4×35全ねじ、頭φ7×4、六角3、DIN433 M4座金φ8/4.3/t0.5。
部分ねじのM4×35は代用不可。全ねじを指定して購入。
圧縮ばね：OD5、線0.3、自由長20、密着3.15、内径4.4参考、定数0.1 N/mm。
作動5〜17。MBA CS-0500-0200-03-S4-C参考。寸法だけで他線径へ代用しない。
M4軸を通すためばね内径、端末形状、荷重曲線を現物確認。CADは定ピッチ参考。
高さ：M3平先×10（g=0〜6）、M3平先×16（g>6〜12）、4本とも同じ高さへ。
固定：M3全ねじ×12/16/20/25から選択、2本／弦。
固定座金はDIN433 M3 φ6/3.2/t0.5、スペーサも外径6以下。
固定の頭下高さ=11+g+t。先端Z=11+g+t−Lを0.2〜0.7に調整。
ベース厚さ6なので掛かり=6−先端Z=5.3〜5.8。
ねじ長・座金厚の公差を実測し木部への突出を避ける。

組立・調整
まずベースを木部に固定。後側木ねじの工具空間のため後方M4は後で入れる。
アンカー、高さねじ、固定ねじ、ばね、後方M4を組み立てる。
φ6×厚4.75参考ボールは中央Y14付近から入れ、前肩Y6まで滑らせる。
弦を緩める→固定ねじを緩める→弦高→オクターブ→固定ねじを締める。
M4後方ねじ1回転で0.7移動。締めて後ろへ、緩めてバネで前へ。
弦張力を受けるのは後方ねじ。バネは位置決め用。

比較の結果と限界
仮荷重350 N/弦、g12（弦中心20）、後壁を固定端片持ち梁として比較。
実CAD断面Z3.6〜18.6、0.2刻み。固定パッドは断面から除外。
最大公称曲げ応力：C51.0 MPa、D31.2 MPa、約39%減。
後尾中央有効断面概算20.5→48.4 mm2（約2.36倍）。後方ねじ谷径相当を控除。
M3/M4ねじ引張応力断面積5.03/8.78 mm2（約1.75倍）。構造全体の耐荷重倍率ではない。
局所応力集中・ねじ締付・支持/接触/ベース剛性・木部・疲労を含まない簡易比較。
350 Nは比較仮定で実弦荷重の測定値でも許容荷重でもありません。FEAと実試験は未実施。

CAD検査
9組の高さ・前後位置で部品/金物の干渉（ねじ噛合い除外）、STEP再読込。
1201高さ点で固定ネジ先端Z、参考ボール4装填位置の通過を確認。
実弦ボール/巻き部分の適合、木部保持、強度/疲労、音響は初回1弦試作で評価。
弦中心8はφ6参考ボールによる設計値。実弦形状で変わり得る。
各ピエゾは裏面に接着、個別バッファで読み出す。木部経由のクロストークは残る。

再生成
cad/requirements.txtをPython環境にインストールして実行。
python cad/build_bridge.py
python cad/compare_sections.py
blender --background --python-exit-code 1 --python cad/render_bridge.py
python cad/make_documents.py
parameters.jsonは主要設計値一覧で、一部寸法はコード内に固定されています。

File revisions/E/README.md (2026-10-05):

# MB4 Rev E — 曲線・後方左右固定の試作設計

4弦ベース用、弦間19 mm、各弦独立、CNC切削2部品／弦。Jazz Bass／Precision Bass系の新規穴あけ用の提案です。特定機種・既存取付穴への適合は未確認です。単位mm。2026-10-05。

## 今回の変更

後壁頂部を真円R9のアーチへ変更し、左右リブを押出しの二次曲線にしました。リブの露出縁R0.6、壁の前後外周R0.8、中央前根元R1。ベース外形R4、前上縁R0.5、後方上縁R0.6。アンカー外形R3、前上縁R1.2、下面R0.3。丸みは表示だけでなく個別STEPの実ソリッドに含まれます。ねじ座・ボール保持肩・支持平面は機能寸法を優先します。

後リブの後ろに左右2穴を採用。各弦は前1＋後2＝3本、4弦で12本の木ねじです。後方穴はX=±4.5,Y=85、座面板厚5、皿座深さ1.6、底残り3.4。中央のM4調整ねじ頭から離して、組立状態で縦にφ6のドライバー進入域を確認しました。

この配置のため奥行82→90 mmに延長。前穴も(0,4)→(0,5)へ移動しました。旧版のテンプレートは使用せず、Rev E専用のPDF／DXFで位置を実測してください。全幅75 mm、弦中心X=−28.5,−9.5,9.5,28.5。既存5穴とは非互換です。

## 維持する機構

- 弦中心高さH=8+g、g=0〜12、設計上の最低8／最高20 mm。φ6×厚4.75の参考ボールに基づくため、実弦の巻き・ボール形状で弦軸は変わります。
- アンカー前端q=8〜20、肩Y=q+6=14〜26、前後調整12 mm。
- M4×35全ねじ＋DIN433小径座金＋圧縮ばね。ばね作動長17〜5。弦張力は後方ねじが受け、ばねは位置決め用です。
- 高さはM3平先4本／弦。固定はM3全ねじ2本／弦、座金／スペーサ外径6以下。高さに応じた長さと座金厚はPDF5頁で選択。
- 裏面φ12.5／深さ1.5の個別ピエゾ窪み。素子・接着・配線の総厚1.2以下を想定。4chの信号読出しは個別バッファを使用し、共通木部からのクロストークは実測評価します。

## 加工・発注

`cad/step/B03_organic_base.step`（A6061-T6）×4、`A04_organic_anchor.step`（C3604）×4。組立STEPは組付け参照用で、金物・弦・ボール・ピエゾ外形は参考形状です。タップはCADでは下穴のみ：図面指示どおりM3×0.5-6H／M4×0.7-6Hへ加工してください。

`RFQ_CNC.md`、`features.csv`、10頁PDFをSTEPと一緒に渡してください。曲線は平面押出しと一定Rを中心に構成し、3軸切削・反転・後端穴加工を想定しています。曲線・R・増肉の加工パスは増えるため、加工先で工具径・段取り・費用を確認します。今回は試作見積用であり、量産・実機強度の認定済み設計ではありません。

## 確認済みと評価範囲

個別部品の有効ソリッドとSTEP再読込、64ソリッドの組立、q=8/14/20×g=0/6/12の9条件で干渉を確認しました（ねじの嵌合は除外）。高さ1201点で固定ねじ先端Z0.2〜0.7、参考ボールの装填4位置、後方工具進入域も確認。`cad/geometry_check.json`に記録しています。

350 N／弦、最大弦高20、同じM4軸高さ19の片持ち梁断面比較では、後壁の最大公称曲げ応力はRev D 31.2→Rev E 26.1 MPa、約16.4%低下しました。断面係数からの簡易比較でありFEAではありません。後方増肉フランジ・固定パッドを除外し、局所応力集中・ねじ締付け・接触・基板変形・疲労・木部を考慮していません。後方木ねじ追加の強度効果は定量化していません。350 Nは比較用仮定で、実測・推奨・許容張力ではありません。

まず1弦分を試作し、実弦保持・支持剛性・木ねじ保持力・緩み・疲労・ピエゾの感度と分離度を評価してください。ボディ端余白、穴位置、木部厚、既存穴や空洞、必要な弦高は実機で確認します。

## データの再生成

CadQuery/OCP・ezdxf・ReportLab等は`cad/requirements.txt`参照。Blenderは別途必要です。

```bash
.venv/bin/python output_revE/cad/build_bridge.py
.venv/bin/python output_revE/cad/compare_sections.py
blender --background --python-exit-code 1 --python output_revE/cad/render_bridge.py
.venv/bin/python output_revE/cad/make_documents.py
```

`parameters.json`は設計寸法の一覧で、全寸法が自動連動するパラメトリックモデルではありません。形状変更には`build_bridge.py`のスケッチ・R選択と図面も更新し、干渉検査を再実行してください。`cad/reference/RevD_B02_base.step`は断面比較の参照専用で、発注対象外です。

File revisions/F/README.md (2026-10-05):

# MB4 Rev F — 後方1穴・一体クラウン・ミスミ標準金物

4弦、弦間19 mm、各弦独立、CNC切削2部品／弦。汎用Jazz/P Bass系の新規穴あけ用の試作案です。特定機種・既存穴への適合は未確認。単位mm、2026-10-05。

## 変更点

- 後方の木ねじ穴を左右2穴から中央1穴（X0/Y85）へ。前X0/Y5と合わせて2本／弦、計8本。後方座面厚5、皿座底残り3.4、曲線リブを維持。奥行90は工具域を残すため維持。
- アンカーを先端R7・丸いφ12クラウン・ゆるいくびれへ変更。本体高さ8、保持部だけ最高10。一体加工なので別のtone pin、横穴、止め輪は追加しません。球受けの窪みをY6〜17へ短くして後方タップ前の肉を残しました。
- 高さはM4平先（穴X±5/Y15,20.5）へ。MSSFS4-8/12/16を小ロットで購入でき、M3×16の1000本箱を避けられます。外側の肉を残すため穴を内側へ移動。
- 後方ねじはM4×35全ねじから、汎用SCB4-30（M4×30・半ねじ20）へ。前後の調整12 mmを維持し、首下の非ねじ部がアンカーへ入らない配置にしました。
- ばねはMISUMI UY6-20（急ぐ場合はE-GUY6-20）を参照。外径6、線径0.35、自由長20、k=0.098 N/mm。中央壁の前根元Rを0.8にして最低位置のばね外径を逃がしました。

丸みはSTEPの実ソリッドに含まれます。Ray Rossの球端から弦を伸ばす構成を参考にした独自のクラウン保持構造です。同製品のtone pin機構、音質、低摩擦、弦寿命を再現したとの評価はしていません。

## 調整と購入

弦中心H=8+g、g=0〜12（公称8〜20）。φ6×厚4.75参考ボールの軸に基づくため、実弦の結び・巻き部で弦軸は変わり得ます。高さ平先はg≤4でL8、4<g≤8でL12、8<g≤12でL16。ねじ掛かりは公称4〜8。

前端q=8〜20、保持肩Y=q+6=14〜26。SCB4-30の頭座Y73.5、先端Y43.5。アンカーへの公称ねじ重なり6.5〜18.5、非ねじ部先端Y63.5とアンカー最大後端Y62の隙間1.5。実物の面取りと不完全ねじを除いた有効掛かり6以上、首下の干渉を試作で確認します。

ばね作動長17〜5。公称力0.294〜1.47 N。自由長公差±1.5を考慮し、作動長≥実測自由長−15に合わせます。自由長21.5の場合は最短6.5、q最大18.5まで。**12 mmは公称寸法での前後調整幅で、全ロットで保証する幅ではありません。** ばねは位置を戻す部品で、弦張力の受けは後方ねじと固定部です。

固定用はM3頭付き2本／弦。長さ12/16/20/25と外径6以下の座金・スペーサで合わせます。PDF5頁の式・表を使い、ねじ先端Z0.2〜0.7に調整して木部への突出を防止。実測したgと金物の公差で厚さを微調整します。高い弦高では金物の交換が必要です。

MISUMI_purchase_options.csvに型番、数量条件、通常価格・納期割引価格、確認状態とURLを記載。hardware_sources.txtには小ロット向けの選び方を記載。価格は2026-10-05の公開表示・見積表示、税別、購入時再確認。発注・購入は行っていません。

## CNC発注

個別STEP：cad/step/B04_single_rear_base.step（A6061-T6）×4、A05_crown_anchor.step（C3604）×4。まず各1個の試作推奨。RFQ_CNC.md、features.csv、10頁PDFを併用。組立STEPの金物、弦、ばね、ピエゾは参考外形で切削対象外。ねじは螺旋を省略し、タップは下穴のみ表現：M3×0.5／M4×0.7-6Hで加工。

平面曲線の押出し、円筒、一定Rを中心に3軸切削＋反転＋後端穴加工を想定。Rは工具パス・段取りが増えるため、加工先で精度・工具径・費用を確認します。一般寸法±0.10、機能穴・座標±0.05、指定R±0.05、接触面平面度0.05／Ra3.2目安。

PDF7頁とDXFは新規取付用。全幅75、奥行90、弦中心X=−28.5,−9.5,9.5,28.5。既存5穴とは非互換。原寸100%で印刷して50 mm枠を実測し、ボディ端余白・木部厚・既存穴・空洞・スケール補正量を確認して穴位置を決定します。

## ピエゾと確認範囲

裏面φ12.5深さ1.5の窪みへ、各φ12以下の素子を金属裏面に接着。素子・接着・配線の総厚1.2以下、木部まで0.3以上離して圧壊を避けます。各素子を別バッファで読み、共通木部を通るクロストークを4ch録音で評価します。

個別STEPの有効ソリッドと再読込、64ソリッドの組立、q=8/14/20×g=0/6/12の9条件、高さ1201点、参考ボールの装填4位置を確認。後方のドライバーφ6進入域とばね外径φ6の包絡域を9条件で追加確認。cad/geometry_check.jsonとcatalogue_envelope_check.jsonに記録。ねじ嵌合部分は干渉判定から除外。

実物の公差、球端・巻き部との適合、強度、疲労、緩み、木ねじ保持力、音響は未検証。Rev Eの簡易断面応力値を本版の強度値に転用していません。まず1弦分で確認後に4弦へ進みます。

## 再生成

```bash
.venv/bin/python output_revF/cad/build_bridge.py
.venv/bin/python output_revF/cad/verify_catalogue_envelopes.py
blender --background --python-exit-code 1 --python output_revF/cad/render_bridge.py
.venv/bin/python output_revF/cad/make_documents.py
```

parameters.jsonは寸法一覧。多数の寸法はbuild_bridge.py内のスケッチに直接記載され、全寸法が自動連動するモデルではありません。形状変更時は図面・購入表も更新し、干渉確認を再実行。cad/referenceは前版参照用で発注対象外。

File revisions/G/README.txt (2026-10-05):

MB4 Rev G - smooth aluminum independent bass bridge prototype
2026-10-05 / mm

今回の版はRev FのJLC加工確認で見つかった穴の交差と長い止まりタップを修正し、外観の丸みを増した試作版です。Rev FのSTEPは今回の発注には使用しないでください。

製作対象：
B05_smooth_base: 6061-T6、18×98×25、4個
A06_smooth_anchor: 6061-T6、18×50×最高10、4個
各部品は単一の有効ソリッド。組立STEPは金物参考形状を含む64ソリッドで、JLCへは提出しません。

見た目：後壁外周R1.4、壁とリブの内角R2、外側の曲線リブ稜線R0.8、アンカー本体上縁R0.8/下縁R0.4、クラウン上縁R1/根元R0.8。弦溝後端も丸くしました。固定M3を高さ1.65のボタン頭にした参考組立。部品を追加せず2種類/弦を維持。

修正：
高さM4穴をX±5.25、Y20/27へ移し、ボール窪みと側面裏逃げから離しました。
後方M4をY50から裏面開放窓へ通すタップに変更。下穴加工経路12、全周有効ねじ8以上（Y42..50）。出口の一部ねじ部分もタップを通して加工します。
中央裏窓は幅4.4×長15×深6.3。屋根の残り1.7。後方ネジは窓内を移動。高さM4主径から窓まで公称の最小バルク肉厚1.05。
ベース長90→98、アンカー長42→50。調整量と最低高さを維持するため後壁・固定パッドを8移動。後木ネジはリブ後ろ中央1穴、X0/Y93。前X0/Y5と合わせ2穴/弦（4弦計8）。

調整：
弦中心参考H=8+g、g=0..12（実弦とボール・巻き部により変わる）。
通常の前後位置q=8..18、10 mm調整。ばねを実測して条件を満たす場合だけq=20まで、公称12 mm。
UY6-20自由長20±1.5、許容たわみ15なので、作動長25-q >= 実測自由長-15。
M4×30頭座Y81.5、先端Y51.5、首下非ねじ先端Y71.5。アンカー後端はq+50。
後方タップの全周ねじ領域との公称重なりは6.5..8。先端面取りを含む実際の有効掛かり6以上を確認。
高さM4平先長8（g<=4）、12（4<g<=8）、16（8<g<=12）。公称掛かり4..8。4本/弦。
固定M3長12/16/20/25とOD6以下の座金スタックはガイド表から選択。公称先端Z0.2..0.7。公差を含め現物で木部に突き出さないことを確認。

JLCへ：
jlc_upload内の各部品専用ZIPはSTEPと同名PDFだけです。2種類を別々の品目として各4個で見積。
材料6061-T6、Threads=YES、As-machined。図面のねじ/位置/表面条件をWeb設定にも一致させてください。
JLCは複数部品の組立ファイルを受け付けないため、cad/step/MB4_assembly.stepはアップロードしません。
価格・工具到達性・受託可否は手動審査で確定。こちらからアップロード・見積送信・発注はしていません。

確認：
cad/geometry_check.json：STEP再読込有効、体積一致（相対1e-6）、9条件の組立干渉確認、バネ外径6の包絡、後木ネジD6工具域、1201高さ点の金物選択。
高さタップはZ1..7、後タップはY42..50で、主径4の周囲0.8の全周材料ガードを確認。これは切削肉厚の確認であり、強度試験ではありません。

未評価：
特定のJazz/P Bassの取付高さ・穴・木部厚と空洞、実際の弦端の装填、荷重下の変形・疲労、ねじ/木部保持、ピエゾ信号と弦間分離。まず1弦分の実物で検証してください。
ピエゾは金属底へ接着し、厚さ総計1.2以下。木部との間に0.3以上の隙間を残す。各弦を個別の高インピーダンス入力で読み出す。木部を通じた振動の回り込みは残ります。
Ray Rossを参考にした独自の球端保持クラウン。メーカーのtone pinと同一の機構や音響特性の証明ではありません。

再生成：
Python: cad/requirements.txt（CadQuery/ezdxf/reportlab/svglib/Pillow）
python cad/build_bridge.py
blender --background --python-exit-code 1 --python cad/render_bridge.py
blender --background --python-exit-code 1 --python cad/render_six_views.py
python cad/compose_six_views.py
python cad/make_documents.py
PDF作成時は使用する実行環境のPDFスキルのマーカー手順に従ってください。

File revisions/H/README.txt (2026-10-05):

MB4 Rev H / compact base and simple planar webs / 2026-10-05 / mm

CNC parts for4 strings:
B06_compact_base, Aluminum6061-T6, quantity4, 18x86x25.
A06_smooth_anchor, Aluminum6061-T6, quantity4, unchanged local geometry from RevG.
Use the separate single-part STEP and matching PDF files for quotation.
The A06 component drawing is reused unchanged and is labelled RevG; this is intentional.
Do not use B05 or the RevG mounting template for the new base.

今回の変更：
ベースの前端を12 mm詰め、長さ98→86。
後壁を基準にした移動量：前木ねじ15 mm、ピエゾ16 mmをエンド側へ移動。
旧版座標では前木ねじY5→20、ピエゾY20→36、新しいベース前端は旧Y12。
新座標：前木ねじX0/Y8、後木ねじX0/Y81、ピエゾX0/Y24、固定パッドX±6/Y42。
前後木ねじ間73、木部への固定穴は引き続き2個/弦、4弦で計8個。
リブは幅3、上端Z16を維持。上辺を直線、側面を平面へ変更。
複雑な曲面Rの重なりと、リブ根元に入り込んでいたベース上縁のRを除去。
壁とリブの内角R2は工具のために保持。露出斜辺・アーチ稜線・前板上縁はC0.25。
リブとベースの外側面は一枚の平面としてつながる。斜視図では隠れ線を省略。
アンカーのクラウン、丸み、4本の高さねじ、長穴、裏面開放窓は変更なし。
ステンレスねじ、M4×30後方ネジ、ばね、座金もRevGと同じ。

組立：
前木ねじがアンカーの下に入るので、ベースをボディに固定してからアンカーを組む。
前取付穴はアンカーを装着したまま締める用途ではない。取り外す際は先にアンカーを外す。
前の木ねじの頭を皿座へ収め、金属上面から突出しないようにする。
ピエゾを金属裏面の窪みへ接着。φ12以下、接着・配線を含む厚さ1.2以下。
木部まで公称0.3以上離す。ピエゾを木部と金属で挟み込まない。
各弦を個別の高インピーダンス入力で読む。木部を通る弦間の振動は残る。

可動域：
新座標のアンカー前端q=-4..8。通常q=-4..6、10 mm。公称最大12 mmはばね実測条件付き。
ばねの作動長13-q。実測自由長からのたわみ15以下、密着させない。
最も前に出したq=-4では、アンカーの先端がベースより4 mm前へ出る。
このため、最前位置のモジュールの全長は90 mm。ベース板そのものは86 mm。
最低弦中心参考8、最高20。球端や巻き部の実物形状で弦軸の高さは変わり得る。
高さM4平先8/12/16、固定M3長12/16/20/25と座金厚はガイド表から選択。
M4後方の軸Z7..19、頭座Y69.5、先端Y39.5、非ねじ先端Y59.5。
A06の後方タップはY50より、裏面開放窓につながる短い貫通加工。全周ねじ8以上。

CAD確認：
各STEPの再読込有効、64ソリッドの参考組立有効。
9組の高さ/前後位置でCNC部品、金物、ばねOD6包絡を確認。指定タップ主径だけを嵌合域として除外。
高さ・固定ねじの長さと先端をg0..12の1201点で確認。
後木ねじのD6工具域、アンカー取り外し状態での前木ねじのD6工具域を確認。
前木ねじのD7/90皿頭包絡とアンカーに干渉なし。
リブ根元X±8.85/Y59..75.5/Z2.75..2.9の材料帯が切れずにつながることをSTEP上で確認。
M4タップ周囲の0.8 mm材料ガードはRevGの修正を維持。
固定M3の実際の下穴がX±6/Y42でボスを貫通し、その周囲に0.8 mm以上の材料が残ることを確認。
これは形状と干渉の確認であり、荷重下の強度・疲労を保証するものではありません。

JLCへ：
jlc_uploadの部品別ZIPを2種類、各4個で見積。Threads=YES、6061-T6、As-machined。
同名STEP/PDFを添付。組立STEP/STL/画像/ガイドは加工対象としてアップロードしない。
MB4_JLCCNC_upload_RevH.zipは2組のSTEP/PDFだけ。
受託可否、工具到達性、加工費と納期はJLCの手動審査で確定。こちらから送信・発注は未実施。
穴位置の変更に合わせた専用1:1 DXFを同梱。既存Jazz/P Bassの取付穴には非互換。
実弦、ボディ高さ/穴/空洞/厚さ、ねじ・木部保持、疲労、ピエゾ分離度はまず1弦で検証。

再生成：
Python依存はcad/requirements.txt。
python cad/build_bridge.py
blender --background --python-exit-code 1 --python cad/render_bridge.py
blender --background --python-exit-code 1 --python cad/render_six_views.py
python cad/compose_six_views.py
python cad/make_documents.py
python cad/package_outputs.py
PDF作成では利用するPDFスキルのマーカー手順を先に実施。A06のPDFは変更せず流用する。

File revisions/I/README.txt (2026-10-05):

MB4 Rev I / 20 mm continuous intonation travel / 2026-10-05 / mm

B07_long_travel_base: 6061-T6, quantity4, nominal18x86x25.
A07_long_travel_anchor: 6061-T6, quantity4, nominal18x55x10.
Use two separate single-part STEP + same-name English PDF pairs for JLC quotation.
Both CNC parts change from Rev H. Do not mix A06/B06 with A07/B07.

変更内容
ベース板の長さ86、幅18、木ねじ中心X0/Y8・Y81、ピエゾX0/Y24は維持。
連続オクターブ調整20 mm：アンカー前端q=-15..5。中央q=-5なら±10。
アンカー長50→55、長穴全長15.4→23.4、長穴幅3.4。
固定ボスX±6/Y36、アンカー長穴中心X±6/Y41。
高さねじ4本は維持。X±5.7/Y19・25。前皿穴を避けるため左右へ0.45移動。
後壁Y70.5..76.5（+7.5）、厚さ6を維持。リブ幅3、内角R2、露出稜線C0.25。
前リブ(Y,Z)(66,3)..(70.5,16)、後リブ(76.5,16)..(81.5,5)。根元の外側面は平面。
後壁移動で後リブの足は短縮。荷重下の剛性・疲労は未検証で、強度向上の保証はしません。
後方木ねじの皿頭座をZ3へ下げる（D7.4深さ2）。上面開放の8x8/R1.5深さ2の頭逃げトレー。
最低高さで後方M4の頭が木ねじや後端板へ当たらないようにした形。
後タップM4x0.7-6Hはアンカー局所Y55から12 mm加工、裏開放窓へ貫通。全周ねじY47..55の8。
中央開放窓4.4x22/depth6.3/R1.5、中心Y36。ねじ主径と窓側壁の公称片側隙間0.2。

金物
後方：NBK SNSS-M4-45-FT（ミスミSNSS-M4X45-FT）、SUSXM7/A2-50、全ねじM4x45。
半ねじSCB4-45は使用不可。長さだけ合わせた置換はしない。
ばね：UY6-35、OD6、wire0.4、L35±1.5、k0.098、密着参考6.8、許容たわみ26.25。
作動長15.5-q、30.5..10.5。自由長最短33.5時に予圧3、最長36.5時の最大たわみ26。
残り0.25はCAD公称値なので実寸を照合。必要なら端位置を制限。密着まで潰さない。
参考高さ8..20。高さM4平先8/12/16とM3固定長12/16/20/25・小形座金はガイド表で選択。
新しい2品の現在見積価格は未取得。BOM・購入候補表の確認状態を参照。

ベースを伸ばさない代わりに
最前q=-15でアンカーが前へ15 mm張り出す。端位置のモジュール全長は101 mm。
Rev Hの最前位置では張り出し4、全長90。この外形差はベース板の長さとは別。
最前位置で高さねじ中心はY4とY10、ベース上に全4 mm径の足が接地する。
弦の肩の参考位置はq+6、Y-9..11。実際の球端・巻き部で接点は変わり得る。
補正0..20に置くならベース前端=スケール長+9が参考位置。実弦とネックで取付位置を確定。

組立と調整
前後の木ねじを先に締めてベースを固定し、ピエゾ配線、アンカー、ばね、M4調整ボルトの順に組む。
前木ねじはアンカーの下。後木ねじ工具域は後方調整ボルトの頭と重なるので組立前に締める。
取り外す場合は先にアンカーと後方ボルトを外す。後方木ねじの頭もZ3の皿座へ完全に収める。
弦を緩め、長穴のM3固定ねじを緩め、後方M4を回して前後位置を調整。再度M3固定・チューニング。
高さ調整は4本のM4平先を均等に当て、固定ねじ・座金を高さに応じて選択。
ピエゾφ12以下、接着配線込み1.2以下、金属裏へ接着。木部と挟み込まず、各弦を個別入力で読む。

CAD確認
2部品の有効ソリッドとSTEP再読込、64ソリッド参考組立、9つの位置/高さで干渉を検証。
verify_travel.pyは輸出STEPでq=-15..5を1 mm刻みの21位置、g0を追加検証。
部品・後方ネジの長い側0.5公差・ばねOD6包絡・固定長穴・4本の高さ足の全面接地を確認。
実下穴の位置、M4主径周囲0.8材料ガード、根元材料の連続、高さ・固定金物1201高さ選択を確認。
CAD検証は実機の強度・疲労、具体的なベースへの適合、弦の球端、木部保持、ピエゾ分離度の保証ではない。
JLCへはまだ送信・発注していません。受託可否・工具到達性・価格と納期は見積審査で確定。

再生成
python cad/build_bridge.py
python cad/verify_travel.py
blender --background --python-exit-code 1 --python cad/render_bridge.py
blender --background --python-exit-code 1 --python cad/render_six_views.py
python cad/compose_six_views.py
python cad/make_documents.py
python cad/package_outputs.py
CAD生成の後にプレビューを作り、同じ版でPDFとZIPを出力。

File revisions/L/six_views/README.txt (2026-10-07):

MB4 Rev L — six orthographic views

全6面は同倍率の正投影。前面=-Y、後面=+Y、左面=-X、右面=+X、上面=+Z、下面=-Z。
ボディと長い弦の参考表示を非表示。ピエゾとボール端は参考外形。CAD形状の変更なし。
下面は上向きに見る方向のため、上面と比べて前後が反転する。
寸法を測る場合はSTEP・図面を使用。この画像は寸法図ではない。

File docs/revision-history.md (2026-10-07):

# Rev A〜Lの開発履歴

初期案から、外周の丸み、低弦高、補強、曲線外形、クラウン、アルミ加工性、短いベース、長い調整域へ進んだ履歴です。Rev A〜Iは2026-10-05、Rev J/Kは2026-10-06に保存した試作データです。Rev Lは2026-10-07の球端保持部改訂です。各版のSTEP・PDF・生成ソースを`revisions/`に保存しています。

Rev A〜Iの一覧

[高解像度PNG](assets/revision-history.png)。画像は保存された各版のCADレンダーで、縮尺・アンカー位置・高さは各版で異なります。

| 版 | 狙い・前版からの変更 | ベース長 mm | 参考弦中心 mm | 切削部品／弦 | 保存データ |
| --- | --- | --- | --- | --- | --- |
| A | 独立4弦と裏面ピエゾ。ベース＋キャリッジ＋黄銅アンカー | 82 | 15〜20 | 3 | [A](../revisions/A/) |
| B | 外周と稜線にRを追加。機能寸法は維持 | 82 | 15〜20 | 3 | [B](../revisions/B/) |
| C | キャリッジ・アンカーを一体化。ネジ＋ばね、前後12 mm調整、最低8 mmへ | 82 | 8〜20 | 2 | [C](../revisions/C/) |
| D | 前後リブ、厚い固定パッド、後方M4を採用 | 82 | 8〜20 | 2 | [D](../revisions/D/) |
| E | R9アーチと曲線リブ。後方左右2穴を追加、木ねじ計12穴 | 90 | 8〜20 | 2 | [E](../revisions/E/) |
| F | 後方を中央1穴へ戻し、木ねじ計8穴。一体クラウン、M4高さねじ、ミスミ品を採用 | 90 | 8〜20 | 2 | [F](../revisions/F/) |
| G | 両部品を6061-T6へ。高さ穴の交差と長い止まりタップを修正し、丸みを追加 | 98 | 8〜20 | 2 | [G](../revisions/G/) |
| H | 前取付穴・ピエゾをエンド側へ移動。98→86 mmに短縮、リブを平面化 | 86 | 8〜20 | 2 | [H](../revisions/H/) |
| I | 長穴・裏窓と後壁位置を変更。M4×45全ねじと長いばねで20 mm調整 | 86 | 8〜20 | 2 | [I](../revisions/I/) |
| J | Rev Iの機構・寸法を維持し、外周・アーチ・リブ斜辺とアンカーの稜線に丸みを追加 | 86 | 8〜20 | 2 | [J](../revisions/J/) |
| K | 滑らかな上面と単純なアーチ・曲線リブ。高さ穴の位置・入口径を変えて縁を保護 | 86 | 8〜20 | 2 | [K](../revisions/K/) |
| L | 球端保持部をカプセル座・入口Rへ変更し、後方の不要な細溝を削除 | 86 | 8〜20 | 2 | [L](../revisions/L/) |

## Rev IからJ：丸みの追加

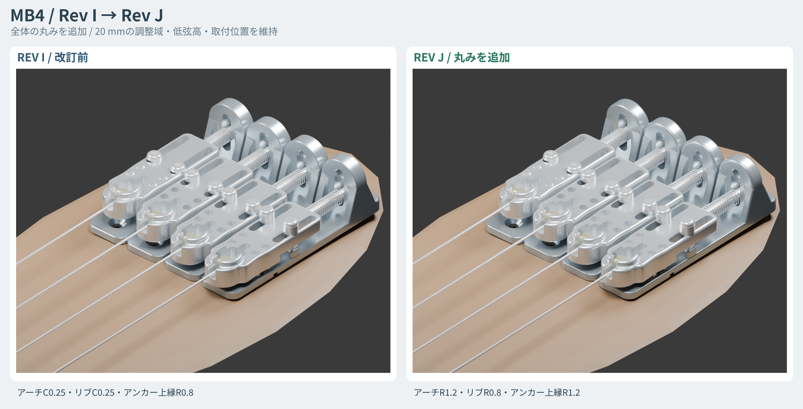
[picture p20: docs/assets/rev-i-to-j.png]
Rev IとJの比較


Rev Jは一定Rの稜線仕上げによる外観改訂です。後壁アーチ縁C0.25→R1.2、リブ外側C0.25→R0.8、内側R0.5追加、前板上縁C0.25→R0.5、アンカー上縁R0.8→R1.2、下縁R0.4→R0.6。クラウンは上縁R1.2・根元R0.6とし、高さ2 mm内でRが重ならない組合せにしています。ベース・アンカーの外形寸法、穴、保持肩、調整域、金物は維持します。

## Rev JからK：流線的な外形と穴の縁

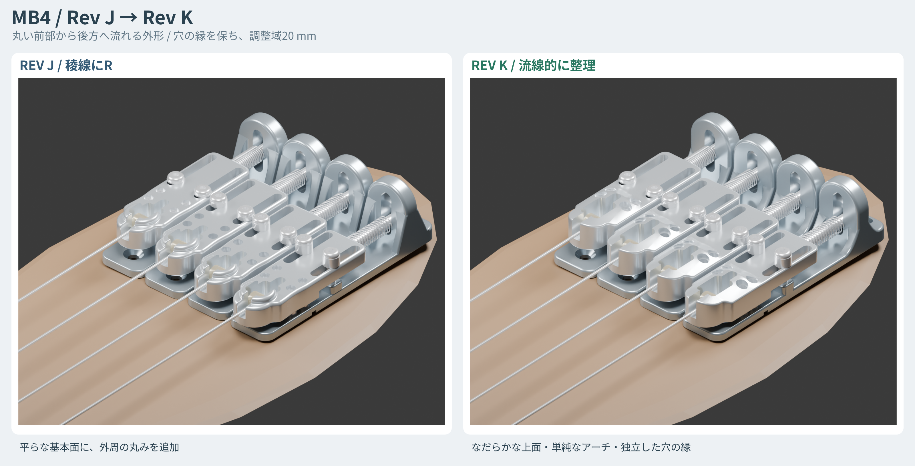
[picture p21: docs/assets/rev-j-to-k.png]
Rev JとKの比較


Rev Kは丸い前部から低い後部へ滑らかにつながる上面、単純なアーチ、曲線リブへ整理しました。最高部は10→10.5 mm。中央の盛り上がった筋や別の座ボスを設けず、後部は一段の平面にしています。高さ穴をX±5.5/Y19・24、入口φ4.2へ変え、穴の縁が外周や隣の加工へ切れないようにします。

最低参考弦高8 mm、前後調整20 mm、ベース86 mm、木ねじ・ピエゾ位置と金物候補を維持します。曲面加工費・工具アクセス・受託可否と実物強度は未確定です。

## Rev KからL：ボールエンド保持部

角丸四角形の保持窪みを、前の平らな肩と奥のR4.1の半円を持つカプセル座へ変えました。上面と入口を実形状R0.6でつなぎ、球端後方へ延びる不要な細溝を削除しています。保持肩Y6・底Z2と参考弦軸Z5、調整域と市販金物は維持します。B10ベースはRev KのB09と同じ形状です。

Rev Lの保持座

## 調整範囲の表記

Rev C〜Eは当時の12 mm調整設計です。Rev Fは公称12 mmですが、ばねの自由長公差によって端位置を制限する条件があります。Rev G/Hでは通常10 mm、実測したばねが条件を満たす場合のみ最大12 mmとして整理しています。

Rev Iは、Rev Hの通常10 mmを20 mmへ拡大した設計です。新しいばねの自由長公差も考慮したCAD寸法ですが、実寸の座面・ばねから端位置を確認する必要があります。86 mmはベース板の長さで、前方限界のモジュール全長は101 mmです。

## 過去版の位置づけ

Rev Fの保存資料には、後の加工確認で見つかったねじ周囲の問題を記載しています。Rev Gで形状を修正しています。旧版は設計過程の参照用で、現行発注用データではありません。

Rev D/Eの簡易断面比較は、仮荷重350 N／弦と限定した片持ち梁モデルによる相対比較です。実測荷重・許容張力・FEA・実機強度試験ではありません。材料や形状が異なる後続版へ強度数値を転用しません。

## 保存対象

各版の部品・組立STEP、加工PDF、CAD生成ソース、設計パラメータ、部品表、加工指示、プレビュー、検証JSONを保存しています。参照用STEPがあるRev D/Eはそのファイルも保存しています。元のバイナリは変更せずコピーしています。

再生成可能なSTL、作業ログ、Python環境と大きなBlenderファイルはGitには収録していません。最新版のフルパッケージは[Releases](https://github.com/Bongorian/mb4-independent-bass-bridge/releases)で配布します。

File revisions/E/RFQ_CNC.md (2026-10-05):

# CNC試作見積依頼 — MB4 Rev E

単位mm、切削部品は2種類。B03ベース=A6061-T6、A04アンカー=C3604。まず各1個の試作と、各4個の価格・納期を見積希望。組立STEPの汎用金物・弦・ピエゾ参考外形は切削発注対象外。

個別STEPを曲面外形の基準とし、PDF・features.csvを機能穴／タップ／公差の指示として併用する。不一致は加工前に照会。タップはSTEPでは下穴形状です。

B03：18×90×最高25。前側板厚3、固定パッド6、後方座面5。平面外形R4、前上縁R0.5、下縁R0.2、後方上縁R0.6。後壁Y67〜73、幅18、肩Z16、頂部Z25、真円R9（中心X0/Z16）。後壁前後外周R0.8、中央前根元R1。

左右リブ幅3、X[-9,-6]および[6,9]。前の上辺は二次BezierのYZ制御点(60.5,3),(63.75,3),(67,16)。後は(80,5),(76.5,5),(73,16)。露出曲線縁R0.6。底面Z3。後方座面はY80〜90、上面Z5。Y78〜80の遷移は三次Bezier：(78,3),(78+2/3,3),(78+4/3,5),(80,5)。平面押出し／一定Rの形状で、複雑な自由曲面の造形は不要。

前木ねじ穴(0,5)φ3.8貫通3、後方(±4.5,85)φ3.8貫通5。皿座は全穴φ7／90°／深さ1.6、前底残り1.4／後底残り3.4。左右固定M3位置(±6,46)、パッド6×6上面Z6、下穴φ2.5、M3×0.5-6H貫通6。裏面ピエゾ(0,20)φ12.5深さ1.5、配線溝X0〜9/Y18.9〜21.1深さ1.2。後壁長穴X0/Z13、幅4.5全長16.5、Y方向貫通6。後方座金逃げはSTEP参照。

A04：18×42、前Y0〜22高さ10／後尾Y20〜42高さ8。平面R3、前上縁R1.2、下面R0.3、後尾上縁R0.2。ボールポケットX±4/Y6〜22、底Z2、平面R1.5、保持肩Y6。弦スリット幅3.4、底Z3.3、長い上縁R0.25。高さM3×0.5-6H貫通10：(±6,11),(±6,18)。固定長穴(±6,32)、幅3.4全長15.4。裏面逃げ6×20深さ3、中心(±6,32)、四隅R1、側面開放。後尾M4×0.7-6HはX0/Z4、Y42より前方、有効ねじ20以上。φ3.3下穴深さ22＋ドリル先端1.0。

一般寸法±0.10、機能穴・座標±0.05、指定R±0.05。接触平面は平面度0.05、Ra3.2を目安。指定以外の穴口・溝縁はC0.1以下でバリ取り。ボール保持肩、ねじ座、接触面、弦軸基準を大きく丸めない。表面処理は見積別項、タップ・支持面・ピエゾ接着面の寸法を保護する。

3軸切削＋反転＋後端穴加工を想定。最小工具径、R部加工、長いM4有効ねじと下穴底、タップ出口、バリ処理の実現性を見積時に確認希望。指定精度の実現が難しい箇所は加工前に代案を提示してください。

付属取付テンプレートはRev E専用（全幅75、弦間19、奥行90）。実機適合と新規穴位置はユーザー側で実測。実物強度／疲労／音響は試作評価予定。比較用350 Nは許容荷重指示ではありません。

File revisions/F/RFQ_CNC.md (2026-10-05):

# CNC試作見積依頼 — MB4 Rev F

単位mm、切削部品は2種類。B04ベース=A6061-T6、A05アンカー=C3604。まず各1個の試作と、各4個の価格・納期を見積希望。組立STEPの汎用金物・弦・ピエゾ参考外形は切削発注対象外。

個別STEPを曲面外形の基準とし、PDF・features.csvを機能穴／タップ／公差の指示として併用する。不一致は加工前に照会。タップはSTEPでは下穴形状です。

B04：18×90×最高25。前側板厚3、固定パッド6、後方座面5。平面外形R4、前上縁R0.5、下縁R0.2、後方上縁R0.6。後壁Y67〜73、幅18、肩Z16、頂部Z25、真円R9（中心X0/Z16）。後壁前後外周R0.8、中央前根元R0.8。

左右リブ幅3、X[-9,-6]および[6,9]。前の上辺は二次BezierのYZ制御点(60.5,3),(63.75,3),(67,16)。後は(80,5),(76.5,5),(73,16)。露出曲線縁R0.6。底面Z3。後方座面はY80〜90、上面Z5。Y78〜80の遷移は三次Bezier：(78,3),(78+2/3,3),(78+4/3,5),(80,5)。平面押出し／一定Rの形状で、複雑な自由曲面の造形は不要。

前木ねじ穴(0,5)φ3.8貫通3、後方(0,85)φ3.8貫通5。皿座は全穴φ7／90°／深さ1.6、前底残り1.4／後底残り3.4。左右固定M3位置(±6,46)、パッド6×6上面Z6、下穴φ2.5、M3×0.5-6H貫通6。裏面ピエゾ(0,20)φ12.5深さ1.5、配線溝X0〜9/Y18.9〜21.1深さ1.2。後壁長穴X0/Z13、幅4.5全長16.5、Y方向貫通6。後方座金逃げはSTEP参照。

A05：外形18×42、本体Z0〜8、クラウン最高Z10。先端真円R7、後端角R3、くびれは三次Bezier（STEP基準）。上縁R0.5、下縁R0.3。クラウンは中心(0,9)、φ12、一体、上縁R0.8／本体接続R0.4。ボールポケットX±4/Y6〜17、底Z2、R1.5。保持肩Y6。弦スリット幅3.4、底Z3.3、クラウン上の縁R0.25。高さM4×0.7-6H貫通8：(±5,15),(±5,20.5)、下穴φ3.3。固定長穴(±6,32)、幅3.4全長15.4。裏面逃げ6×20深さ3、中心(±6,32)、四隅R1、側面開放。後尾M4×0.7-6HはX0/Z4、Y42より前方、有効ねじ20以上。φ3.3下穴深さ22＋ドリル先端1.0。

一般寸法±0.10、機能穴・座標±0.05、指定R±0.05。接触平面は平面度0.05、Ra3.2を目安。指定以外の穴口・溝縁はC0.1以下でバリ取り。ボール保持肩、ねじ座、接触面、弦軸基準を大きく丸めない。表面処理は見積別項、タップ・支持面・ピエゾ接着面の寸法を保護する。

3軸切削＋反転＋後端穴加工を想定。最小工具径、R部加工、長いM4有効ねじと下穴底、タップ出口、バリ処理の実現性を見積時に確認希望。指定精度の実現が難しい箇所は加工前に代案を提示してください。

付属取付テンプレートはRev F専用（全幅75、弦間19、奥行90）。実機適合と新規穴位置はユーザー側で実測。実物強度／疲労／音響は試作評価予定。本版の許容張力は未認定です。

木ねじ穴は1弦につき前1＋後1の2穴、4弦で8穴。旧版の後方左右2穴から中央1穴へ変更。アンカーの形状・高さタップ位置とサイズも異なります。Rev Fのデータ一式を使用してください。

後方購入ねじはMISUMI SCB4-30（M4×30、半ねじ20）、高さはMSSFS4-8/12/16（平先）。購入品とばねの寸法公差を含む組立適合は試作時に照合します。ねじ、ばね、ピエゾは本CNC見積対象外です。

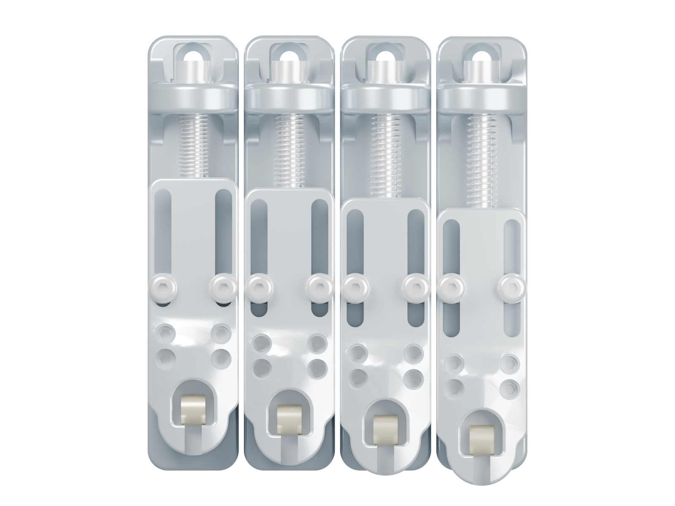
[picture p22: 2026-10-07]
revisions/L/six_views/05_top.png

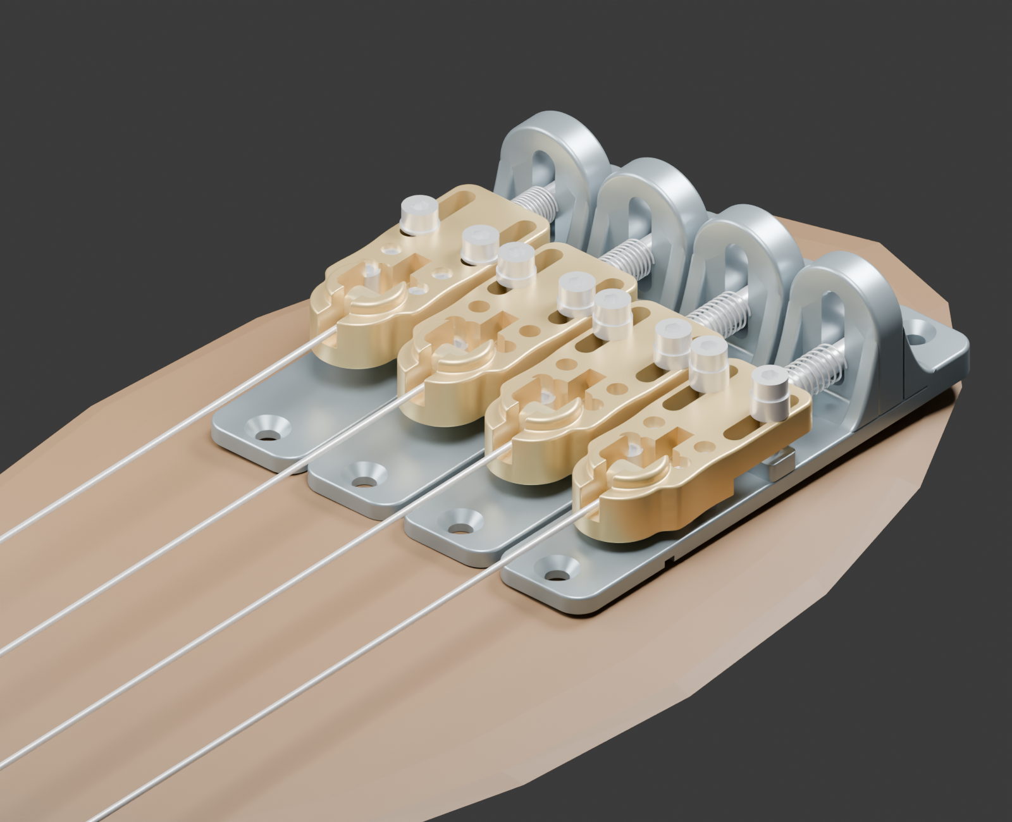
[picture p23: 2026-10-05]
revisions/F/bridge_preview.png

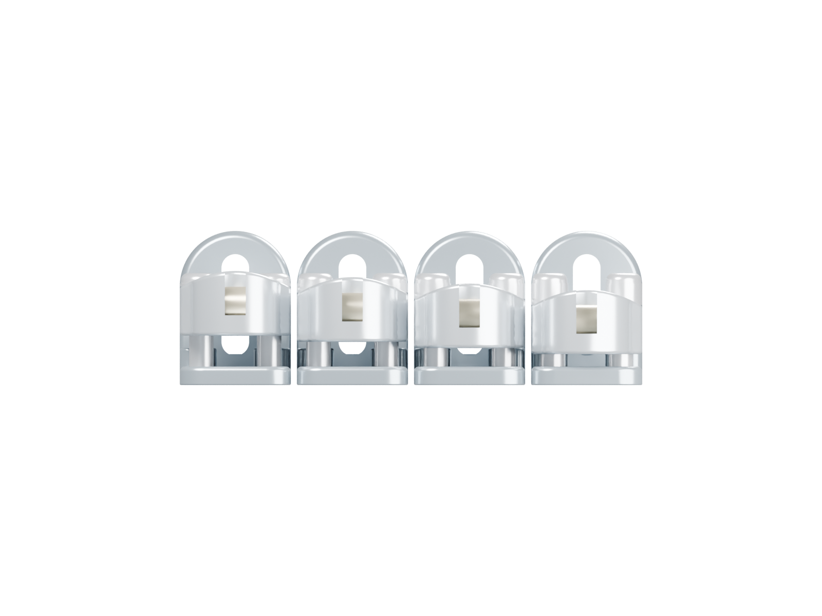
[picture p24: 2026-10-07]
revisions/L/six_views/01_front.png

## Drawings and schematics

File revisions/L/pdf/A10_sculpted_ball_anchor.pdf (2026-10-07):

## A10 / REFINED BALL-END ANCHOR

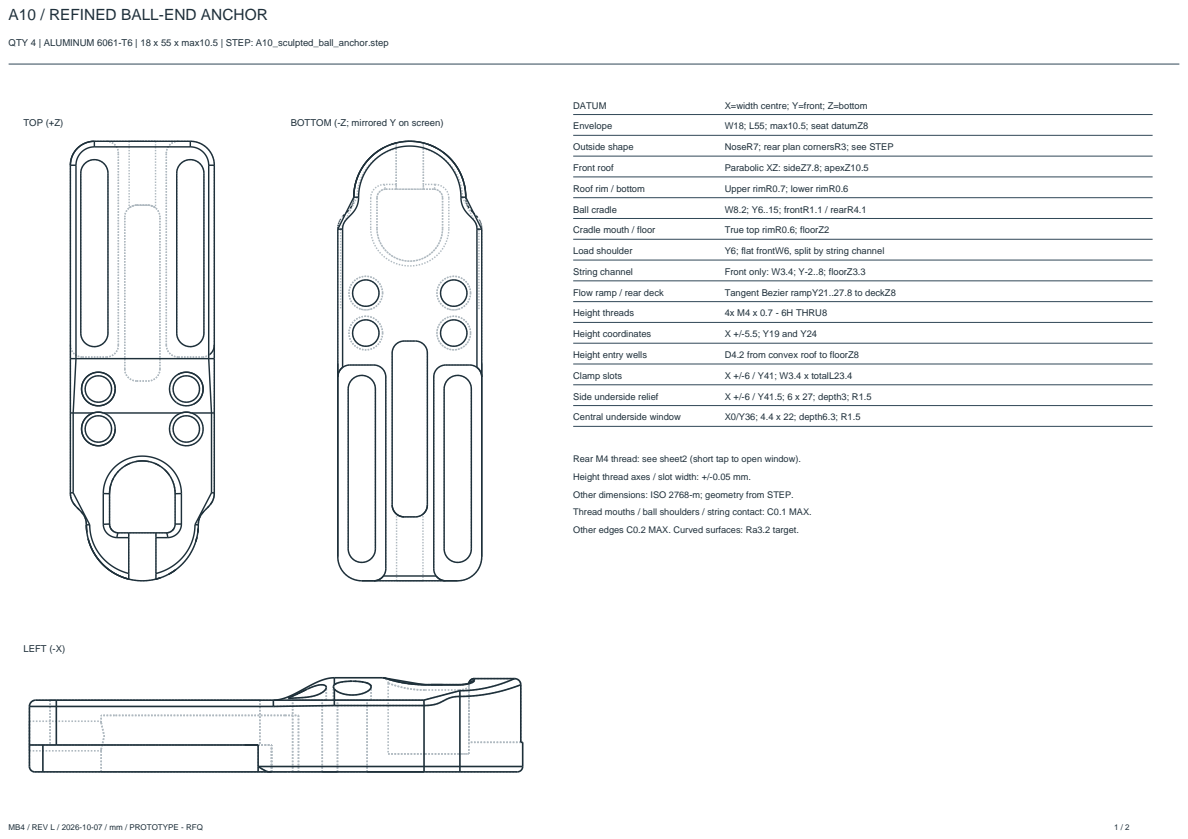
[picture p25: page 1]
MB4 / REV L / 2026-10-07 / mm / PROTOTYPE - RFQ; TOP (+Z); BOTTOM (-Z; mirrored Y on screen); LEFT (-X); DATUM; X=width centre; Y=front; Z=bottom; Envelope; W18; L55; max10.5; seat datumZ8; Outside shape; NoseR7; rear plan cornersR3; see STEP; Front roof; Parabolic XZ: sideZ7.8; apexZ10.5; Roof rim / bottom; Upper rimR0.7; lower rimR0.6; Ball cradle; W8.2; Y6..15; frontR1.1 / rearR4.1; Cradle mouth / floor; True top rimR0.6; floorZ2; Load shoulder; Y6; flat frontW6, split by string channel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

QTY 4 | ALUMINUM 6061-T6 | 18 x 55 x max10.5 | STEP: A10_sculpted_ball_anchor.step

Rear M4 thread: see sheet2 (short tap to open window).
Height thread axes / slot width: +/-0.05 mm.
Other dimensions: ISO 2768-m; geometry from STEP.
Thread mouths / ball shoulders / string contact: C0.1 MAX.
Other edges C0.2 MAX. Curved surfaces: Ra3.2 target.

## A10 / REAR TAP AND OPEN SCREW WINDOW

M4 x 0.7 - 6H; enter at Y55 in -Y direction. Axis X0/Z4. Tap through into the open underside window.

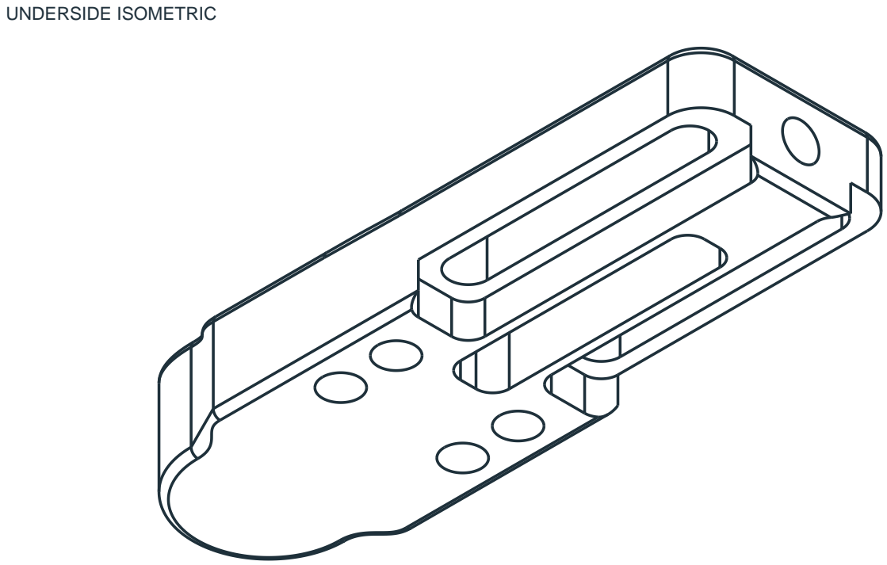
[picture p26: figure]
UNDERSIDE ISOMETRIC

MB4 / REV L / 2026-10-07 / mm / PROTOTYPE - RFQ | 2 / 2

REAR (+Y): axial M4 tap / pilotD3.3

OPEN WINDOW Y25..47 (22)

FULL THREAD LAND: 8 MIN

CENTRE SECTION X=0 - Y27.8..55 FLAT ROOF (front ramp omitted)

1. Drill D3.3 from Y55 to Y43 (12), fully breaking into open window.
2. Tap M4 x 0.7 - 6H through to the window, including partial outlet walls.
3. Require full circumferential thread over Y47..55: 8 mm MIN.
4. Deburr outlet from underside; do not leave an undersized untapped outlet.
5. No blind-hole tip allowance is needed; the outlet is open.

Central window roofZ6.3; rear deckZ8 (top1.7).

M4 screw major radius2: topZ6, roof clearance0.3.

WindowW4.4: nominal side clearance0.2 each.

Full thread land is outside the window.

Nominal window-to-height-tap bulk:1.5.

Capsule cradle; trueR0.6 mouth; no redundant rear slit.

Rear height taps remain forward of side reliefY28.

An extra cross pin / retaining ring is not required.

Tap depth12 = 3 x M4 nominal diameter.

Confirm outlet tapping and tool access at quotation.

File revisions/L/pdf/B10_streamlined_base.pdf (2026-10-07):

## B10 / STREAMLINED ARCH BASE

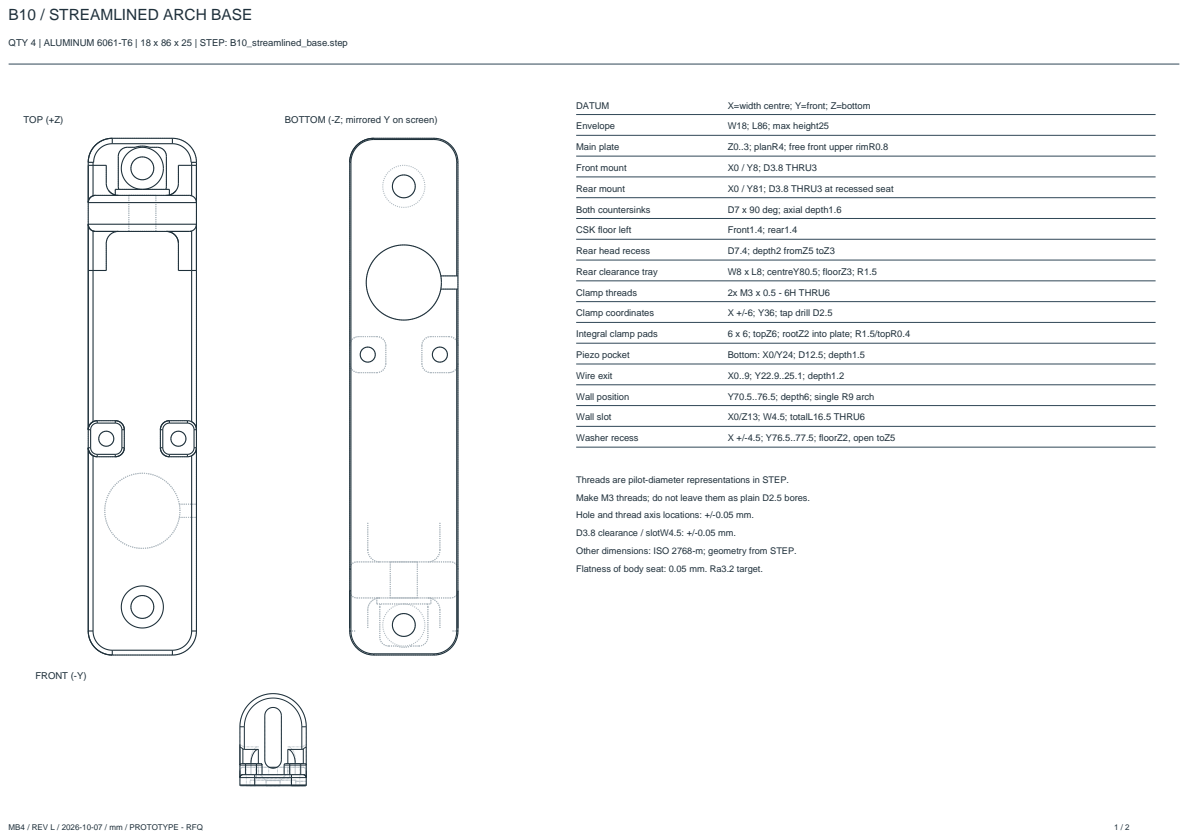
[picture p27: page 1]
MB4 / REV L / 2026-10-07 / mm / PROTOTYPE - RFQ; TOP (+Z); BOTTOM (-Z; mirrored Y on screen); FRONT (-Y); DATUM; X=width centre; Y=front; Z=bottom; Envelope; W18; L86; max height25; Main plate; Z0..3; planR4; free front upper rimR0.8; Front mount; X0 / Y8; D3.8 THRU3; Rear mount; X0 / Y81; D3.8 THRU3 at recessed seat; Both countersinks; D7 x 90 deg; axial depth1.6; CSK floor left; Front1.4; rear1.4; Rear head recess; D7.4; depth2 fromZ5 toZ3; Rear clearance tray; W8 x L8; centreY80.5; floorZ3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

QTY 4 | ALUMINUM 6061-T6 | 18 x 86 x 25 | STEP: B10_streamlined_base.step

Threads are pilot-diameter representations in STEP.
Make M3 threads; do not leave them as plain D2.5 bores.
Hole and thread axis locations: +/-0.05 mm.
D3.8 clearance / slotW4.5: +/-0.05 mm.
Other dimensions: ISO 2768-m; geometry from STEP.
Flatness of body seat: 0.05 mm. Ra3.2 target.

## B10 / SINGLE ARCH AND SWEPT WEBS

Top/bottom/end plus 3D finishing setups. STEP governs convex surfaces; protected planar seats must remain flat.

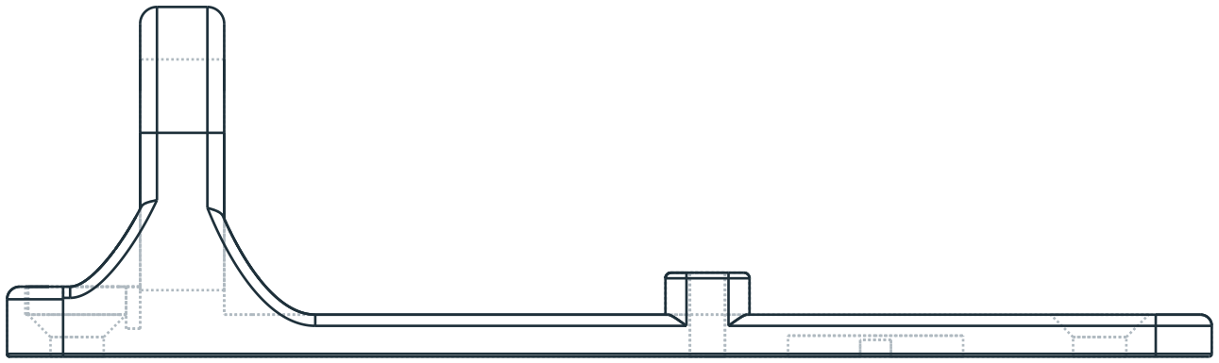
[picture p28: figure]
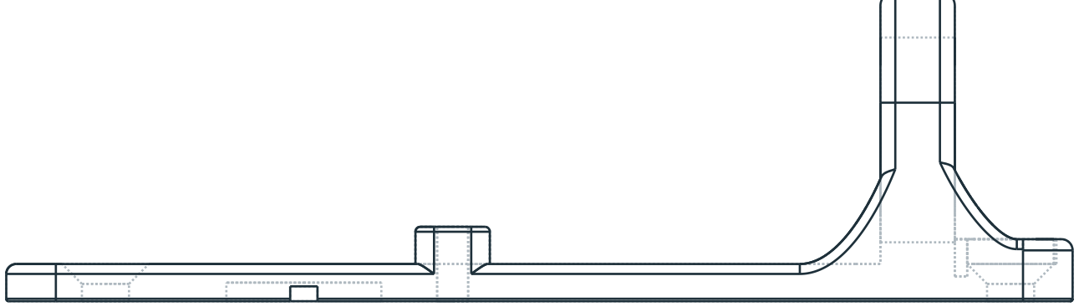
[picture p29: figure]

MB4 / REV L / 2026-10-07 / mm / PROTOTYPE - RFQ | 2 / 2

LEFT (-X)

RIGHT (+X)

ISOMETRIC (illustration; not dimensioned)

One R9 arch centred X0/Z16; apexZ25.

Wall thickness6; exposed arch rimR1.2.

No separate raised washer/spring bosses.

Flat front/rear faces support spring/washer.

Internal wall/floor roots may be eased R0.2 MAX; preserve spring envelope.

Do not enlarge the slot/recess or remove integral ribs without approval.

Remaining cosmetic edges: C0.2 MAX. Thread mouths and countersink seats: C0.1 MAX.

Rear flange: Y76..86, topZ5; free rear end/corners R0.9.

Smooth ramp: Y74..76, Z3..5; profile from STEP.

Ribs width3: X[-9,-6] and X[6,9].

Front swept web: Y64/Z3 to Y72.5/Z16; tip2 into wall.

Rear swept web: Y74.5/Z16 to Y81.5/Z5; tip2 into wall.

Web rootsR2; outerR0.8; innerC0.2 MAX.

Cubic profiles/ramp from STEP; do not replace by triangles.

Aluminum threads: gauge M3 x 0.5 - 6H.

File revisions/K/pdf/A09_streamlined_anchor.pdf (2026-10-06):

## A09 / STREAMLINED ANCHOR

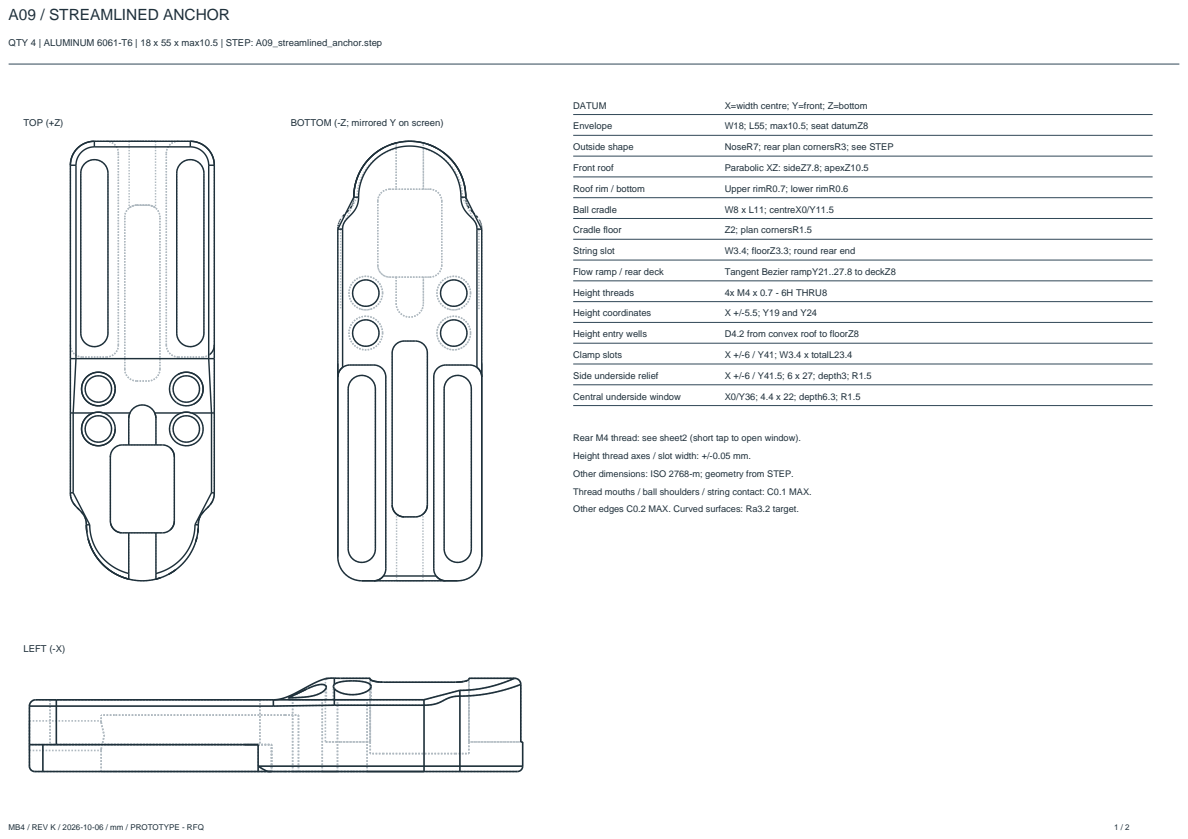
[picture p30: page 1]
MB4 / REV K / 2026-10-06 / mm / PROTOTYPE - RFQ; TOP (+Z); BOTTOM (-Z; mirrored Y on screen); LEFT (-X); DATUM; X=width centre; Y=front; Z=bottom; Envelope; W18; L55; max10.5; seat datumZ8; Outside shape; NoseR7; rear plan cornersR3; see STEP; Front roof; Parabolic XZ: sideZ7.8; apexZ10.5; Roof rim / bottom; Upper rimR0.7; lower rimR0.6; Ball cradle; W8 x L11; centreX0/Y11.5; Cradle floor; Z2; plan cornersR1.5; String slot; W3.4; floorZ3.3; round rear end; Flow ramp / rear deck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

QTY 4 | ALUMINUM 6061-T6 | 18 x 55 x max10.5 | STEP: A09_streamlined_anchor.step

Rear M4 thread: see sheet2 (short tap to open window).
Height thread axes / slot width: +/-0.05 mm.
Other dimensions: ISO 2768-m; geometry from STEP.
Thread mouths / ball shoulders / string contact: C0.1 MAX.
Other edges C0.2 MAX. Curved surfaces: Ra3.2 target.

## A09 / REAR TAP AND OPEN SCREW WINDOW

M4 x 0.7 - 6H; enter at Y55 in -Y direction. Axis X0/Z4. Tap through into the open underside window.

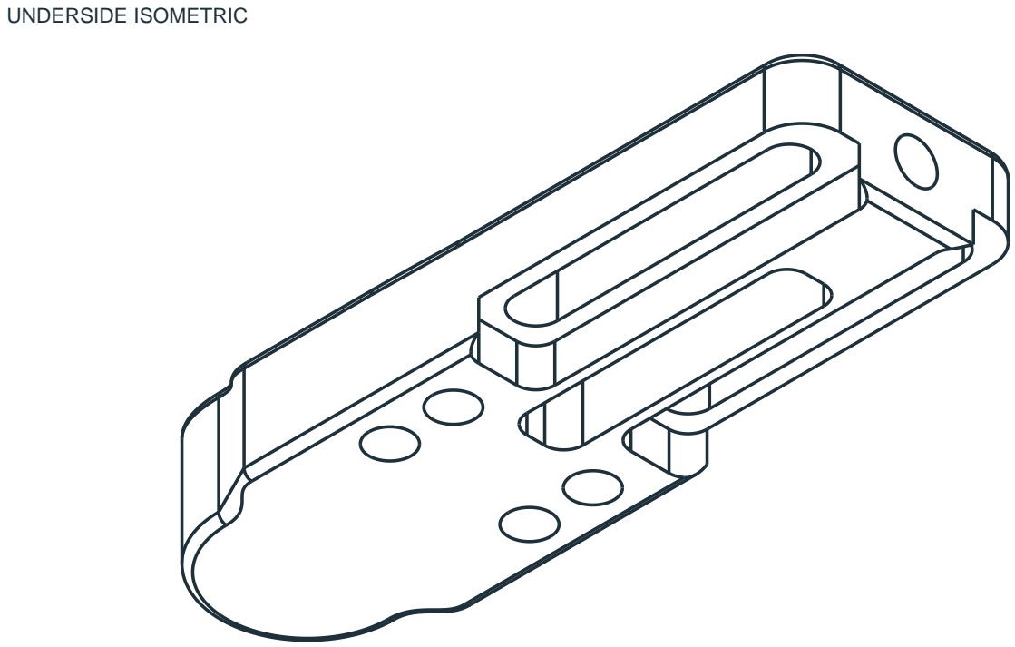
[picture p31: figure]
UNDERSIDE ISOMETRIC

MB4 / REV K / 2026-10-06 / mm / PROTOTYPE - RFQ | 2 / 2

REAR (+Y): axial M4 tap / pilotD3.3

OPEN WINDOW Y25..47 (22)

FULL THREAD LAND: 8 MIN

CENTRE SECTION X=0 - Y27.8..55 FLAT ROOF (front ramp omitted)

1. Drill D3.3 from Y55 to Y43 (12), fully breaking into open window.
2. Tap M4 x 0.7 - 6H through to the window, including partial outlet walls.
3. Require full circumferential thread over Y47..55: 8 mm MIN.
4. Deburr outlet from underside; do not leave an undersized untapped outlet.
5. No blind-hole tip allowance is needed; the outlet is open.

Central window roofZ6.3; rear deckZ8 (top1.7).

M4 screw major radius2: topZ6, roof clearance0.3.

WindowW4.4: nominal side clearance0.2 each.

Full thread land is outside the window.

Nominal window-to-height-tap bulk:1.5.

Front screws no longer break into the ball cradle.

Rear height taps remain forward of side reliefY28.

An extra cross pin / retaining ring is not required.

Tap depth12 = 3 x M4 nominal diameter.

Confirm outlet tapping and tool access at quotation.

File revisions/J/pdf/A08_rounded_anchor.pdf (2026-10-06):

## A08 / SMOOTH CROWN ANCHOR

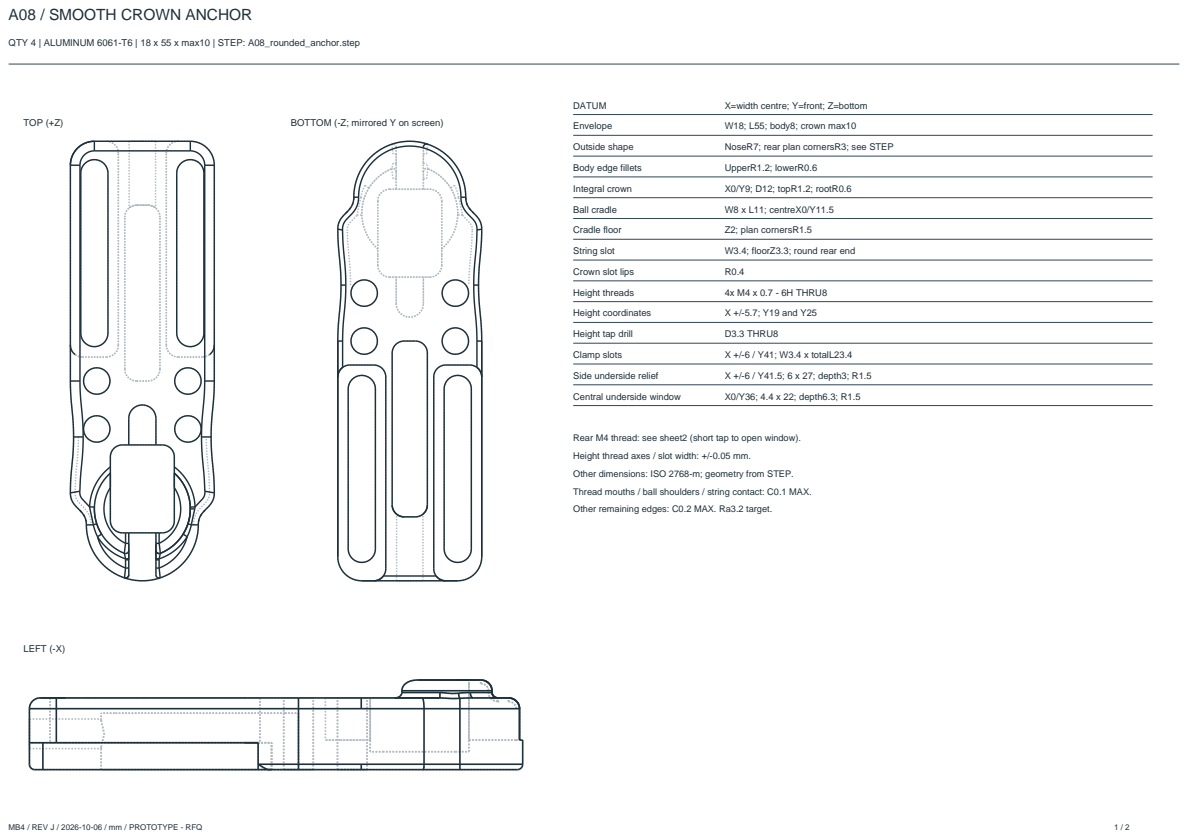
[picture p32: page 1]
MB4 / REV J / 2026-10-06 / mm / PROTOTYPE - RFQ; TOP (+Z); BOTTOM (-Z; mirrored Y on screen); LEFT (-X); DATUM; X=width centre; Y=front; Z=bottom; Envelope; W18; L55; body8; crown max10; Outside shape; NoseR7; rear plan cornersR3; see STEP; Body edge fillets; UpperR1.2; lowerR0.6; Integral crown; X0/Y9; D12; topR1.2; rootR0.6; Ball cradle; W8 x L11; centreX0/Y11.5; Cradle floor; Z2; plan cornersR1.5; String slot; W3.4; floorZ3.3; round rear end; Crown slot lips; Height threads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

QTY 4 | ALUMINUM 6061-T6 | 18 x 55 x max10 | STEP: A08_rounded_anchor.step

Rear M4 thread: see sheet2 (short tap to open window).
Height thread axes / slot width: +/-0.05 mm.
Other dimensions: ISO 2768-m; geometry from STEP.
Thread mouths / ball shoulders / string contact: C0.1 MAX.
Other remaining edges: C0.2 MAX. Ra3.2 target.

## A08 / REAR TAP AND OPEN SCREW WINDOW

M4 x 0.7 - 6H; enter at Y55 in -Y direction. Axis X0/Z4. Tap through into the open underside window.

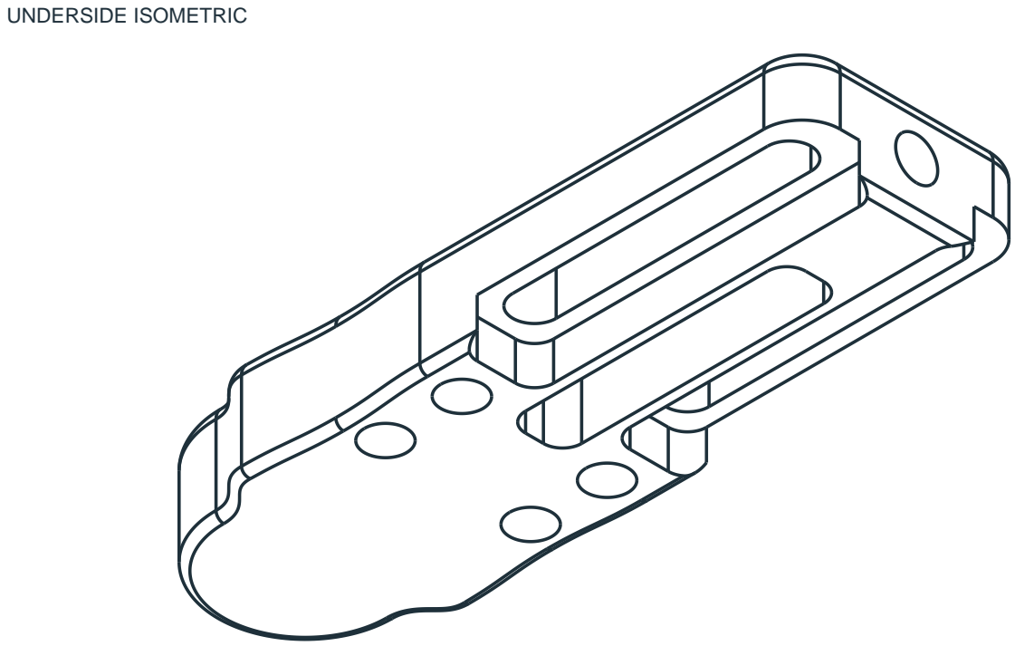
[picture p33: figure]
UNDERSIDE ISOMETRIC

MB4 / REV J / 2026-10-06 / mm / PROTOTYPE - RFQ | 2 / 2

REAR (+Y): axial M4 tap / pilotD3.3

OPEN WINDOW Y25..47 (22)

FULL THREAD LAND: 8 MIN

CENTRE SECTION X=0 - REAR HALF ONLY (pilot-diameter profile)

1. Drill D3.3 from Y55 to Y43 (12), fully breaking into open window.
2. Tap M4 x 0.7 - 6H through to the window, including partial outlet walls.
3. Require full circumferential thread over Y47..55: 8 mm MIN.
4. Deburr outlet from underside; do not leave an undersized untapped outlet.
5. No blind-hole tip allowance is needed; the outlet is open.

Central window: roofZ6.3, remaining top1.7.

M4 screw major radius2: topZ6, roof clearance0.3.

WindowW4.4: nominal side clearance0.2 each.

Full thread land is outside the window.

Nominal window-to-height-tap bulk:1.5.

Front screws no longer break into the ball cradle.

Rear height taps remain forward of side reliefY28.

An extra cross pin / retaining ring is not required.

Tap depth12 = 3 x M4 nominal diameter.

Confirm outlet tapping and tool access at quotation.

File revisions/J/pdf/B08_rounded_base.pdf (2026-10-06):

## B08 / SMOOTH BASE

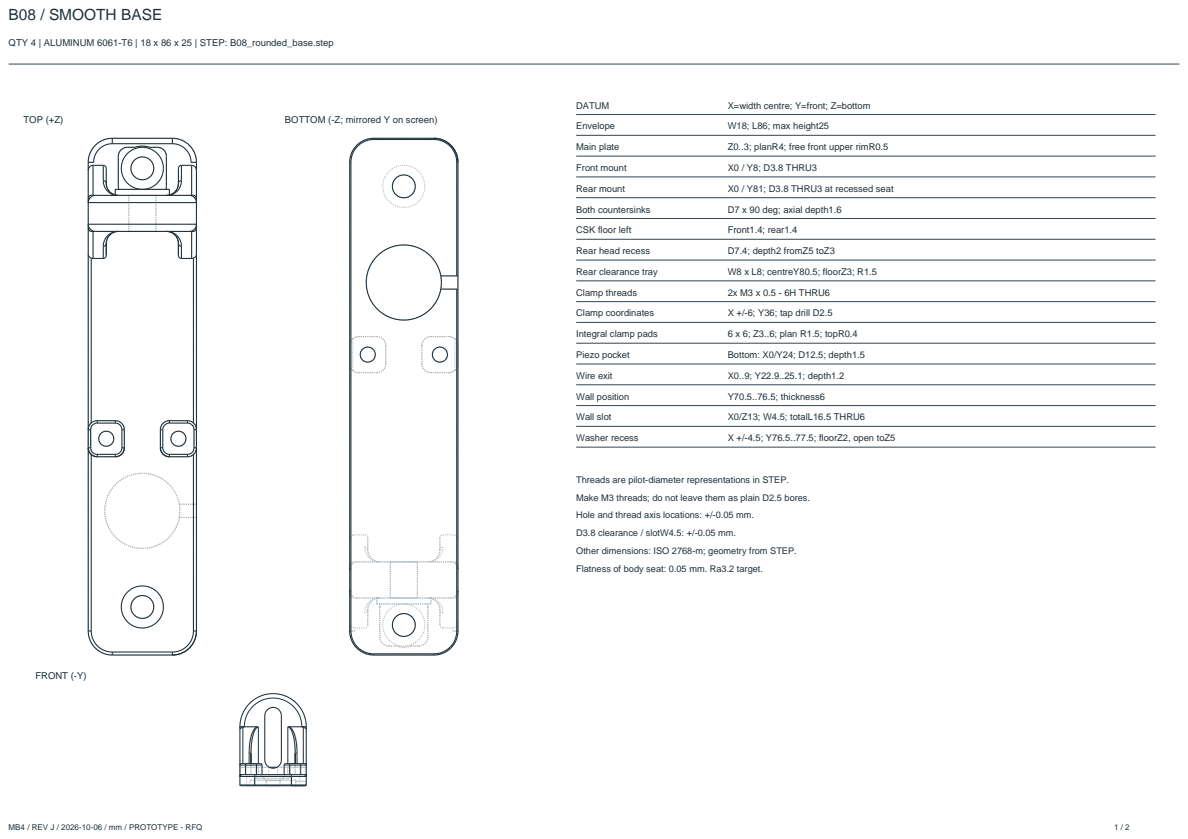
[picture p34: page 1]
MB4 / REV J / 2026-10-06 / mm / PROTOTYPE - RFQ; TOP (+Z); BOTTOM (-Z; mirrored Y on screen); FRONT (-Y); DATUM; X=width centre; Y=front; Z=bottom; Envelope; W18; L86; max height25; Main plate; Z0..3; planR4; free front upper rimR0.5; Front mount; X0 / Y8; D3.8 THRU3; Rear mount; X0 / Y81; D3.8 THRU3 at recessed seat; Both countersinks; D7 x 90 deg; axial depth1.6; CSK floor left; Front1.4; rear1.4; Rear head recess; D7.4; depth2 fromZ5 toZ3; Rear clearance tray; W8 x L8; centreY80.5; floorZ3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

QTY 4 | ALUMINUM 6061-T6 | 18 x 86 x 25 | STEP: B08_rounded_base.step

Threads are pilot-diameter representations in STEP.
Make M3 threads; do not leave them as plain D2.5 bores.
Hole and thread axis locations: +/-0.05 mm.
D3.8 clearance / slotW4.5: +/-0.05 mm.
Other dimensions: ISO 2768-m; geometry from STEP.
Flatness of body seat: 0.05 mm. Ra3.2 target.

## B08 / ROUNDED EDGES AND PLAIN WEBS

Top, bottom and end setups. No enclosed undercuts. Planar web faces and constant edge radii are defined by STEP.

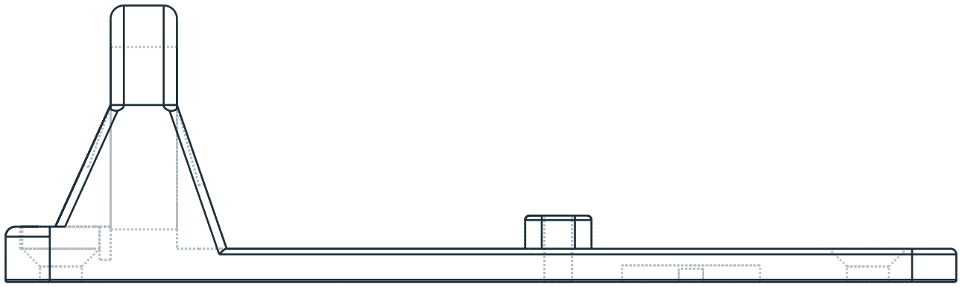
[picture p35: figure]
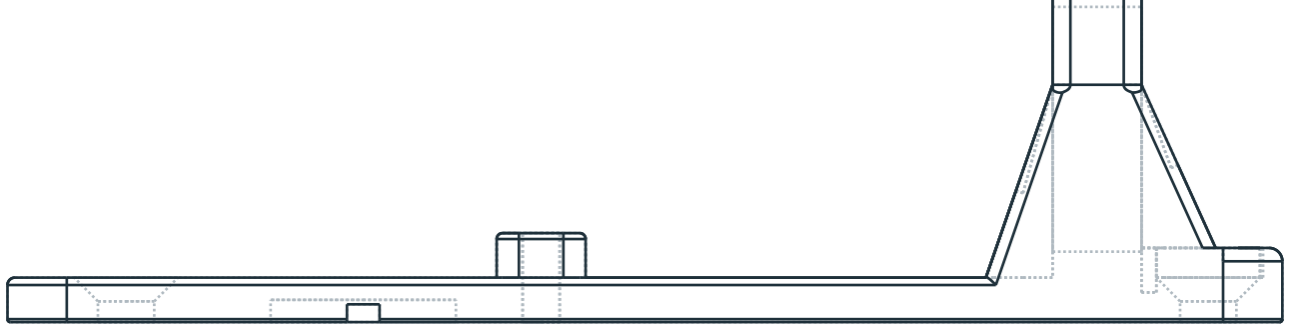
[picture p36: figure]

MB4 / REV J / 2026-10-06 / mm / PROTOTYPE - RFQ | 2 / 2

LEFT (-X)

RIGHT (+X)

ISOMETRIC (illustration; not dimensioned)

Wall arch: true R9, centre X0/Z16; apexZ25.

Arch front/rear rim: R1.2.

Wall/rib vertical inside corners: R2.0.

Web diagonals: outsideR0.8; insideR0.5.

Internal wall/floor roots may be eased R0.2 MAX; preserve spring envelope.

Do not enlarge the slot/recess or remove integral ribs without approval.

Remaining cosmetic edges: C0.2 MAX. Thread mouths and countersink seats: C0.1 MAX.

Rear flange: Y76..86, topZ5; free rear end/corners R0.9.

Smooth ramp: Y74..76, Z3..5; profile from STEP.

Ribs width3: X[-9,-6] and X[6,9].

Front web slope: (Y,Z) (66,3) to (70.5,16).

Rear web slope: (76.5,16) to (81.5,5).

Planar webs width3; rounded edges; no under-root rim groove.

As-machined finish; no polishing of functional seats.

Aluminum threads: gauge M3 x 0.5 - 6H.

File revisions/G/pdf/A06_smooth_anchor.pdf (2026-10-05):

## A06 / SMOOTH CROWN ANCHOR

MB4 / REV G / 2026-10-05 / mm / PROTOTYPE - RFQ; TOP (+Z); BOTTOM (-Z; mirrored Y on screen); LEFT (-X); DATUM; X=width centre; Y=front; Z=bottom; Envelope; W18; L50; body8; crown max10; Outside shape; NoseR7; rear plan cornersR3; see STEP; Body edge fillets; UpperR0.8; lowerR0.4; Integral crown; X0/Y9; D12; topR1.0; rootR0.8; Ball cradle; W8 x L11; centreX0/Y11.5; Cradle floor; Z2; plan cornersR1.5; String slot; W3.4; floorZ3.3; round rear end; Crown slot lips; Height threads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

QTY 4 | ALUMINUM 6061-T6 | 18 x 50 x max10 | STEP: A06_smooth_anchor.step

Rear M4 thread: see sheet2 (short tap to open window).
Height thread axes / slot width: +/-0.05 mm.
Other dimensions: ISO 2768-m; geometry from STEP.
Thread mouths / ball shoulders / string contact: C0.1 MAX.
Other remaining edges: C0.2 MAX. Ra3.2 target.

## A06 / REAR TAP AND OPEN SCREW WINDOW

M4 x 0.7 - 6H; enter at Y50 in -Y direction. Axis X0/Z4. Tap through into the open underside window.

UNDERSIDE ISOMETRIC; FULL THREAD LAND: 8 MIN

MB4 / REV G / 2026-10-05 / mm / PROTOTYPE - RFQ | 2 / 2

REAR (+Y): axial M4 tap / pilotD3.3

OPEN WINDOW Y25..40 (15)

CENTRE SECTION X=0 - REAR HALF ONLY (pilot-diameter profile)

1. Drill D3.3 from Y50 to Y38 (12), fully breaking into open window.
2. Tap M4 x 0.7 - 6H through to the window, including partial outlet walls.
3. Require full circumferential thread over Y42..50: 8 mm MIN.
4. Deburr outlet from underside; do not leave an undersized untapped outlet.
5. No blind-hole tip allowance is needed; the outlet is open.

Central window: roofZ6.3, remaining top1.7.

M4 screw major radius2: topZ6, roof clearance0.3.

WindowW4.4: nominal side clearance0.2 each.

Full thread land is outside the window.

Nominal minimum bulk web to height tap:1.05.

Front screws no longer break into the ball cradle.

Rear height taps remain forward of side reliefY30.

An extra cross pin / retaining ring is not required.

Tap depth12 = 3 x M4 nominal diameter.

Confirm outlet tapping and tool access at quotation.

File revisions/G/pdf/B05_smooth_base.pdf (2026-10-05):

## B05 / SMOOTH BASE

MB4 / REV G / 2026-10-05 / mm / PROTOTYPE - RFQ; TOP (+Z); BOTTOM (-Z; mirrored Y on screen); FRONT (-Y); DATUM; X=width centre; Y=front; Z=bottom; Envelope; W18; L98; max height25; Main plate; Z0..3; plan corners R4; Front mount; X0 / Y5; D3.8 THRU3; Rear mount; X0 / Y93; D3.8 THRU5; Both countersinks; D7 x 90 deg; axial depth1.6; CSK floor left; Front1.4; rear3.4; Clamp threads; 2x M3 x 0.5 - 6H THRU6; Clamp coordinates; X +/-6; Y54; tap drill D2.5; Integral clamp pads; 6 x 6; Z3..6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

QTY 4 | ALUMINUM 6061-T6 | 18 x 98 x 25 | STEP: B05_smooth_base.step

Threads are pilot-diameter representations in STEP.
Make M3 threads; do not leave them as plain D2.5 bores.
Hole and thread axis locations: +/-0.05 mm.
D3.8 clearance / slotW4.5: +/-0.05 mm.
Other dimensions: ISO 2768-m; geometry from STEP.
Flatness of body seat: 0.05 mm. Ra3.2 target.

## B05 / CURVED RIBS AND MACHINING ACCESS

Top, bottom and end setups. No enclosed undercuts. Formed curves and fillets are defined by STEP.


MB4 / REV G / 2026-10-05 / mm / PROTOTYPE - RFQ | 2 / 2

LEFT (-X)

RIGHT (+X)

ISOMETRIC (illustration; not dimensioned)

Wall arch: true R9, centre X0/Z16; apexZ25.

Front and rear wall outside profile edges: R1.4.

Wall/rib vertical inside corners: R2.0.

Outside curved rib rims: R0.8.

Internal wall/floor roots may be eased R0.2 MAX; preserve spring envelope.

Do not enlarge the slot/recess or remove integral ribs without approval.

Remaining cosmetic edges: C0.2 MAX. Thread mouths and countersink seats: C0.1 MAX.

Rear flange: Y88..98, topZ5; outside upper rim R0.9.

Smooth ramp: Y86..88, Z3..5; profile from STEP.

Ribs width3: X[-9,-6] and X[6,9].

Front rib curve: (Y,Z) (68.5,3),(71.75,3),(75,16).

Rear rib curve: (88,5),(84.5,5),(81,16).

Both are quadratic Bezier profiles.

As-machined finish; no polishing of functional seats.

Aluminum threads: gauge M3 x 0.5 - 6H.

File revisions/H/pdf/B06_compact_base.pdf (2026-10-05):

## B06 / SMOOTH BASE

MB4 / REV H / 2026-10-05 / mm / PROTOTYPE - RFQ; TOP (+Z); BOTTOM (-Z; mirrored Y on screen); FRONT (-Y); DATUM; X=width centre; Y=front; Z=bottom; Envelope; W18; L86; max height25; Main plate; Z0..3; planR4; free front upper rimC0.25; Front mount; X0 / Y8; D3.8 THRU3; Rear mount; X0 / Y81; D3.8 THRU5; Both countersinks; D7 x 90 deg; axial depth1.6; CSK floor left; Front1.4; rear3.4; Clamp threads; 2x M3 x 0.5 - 6H THRU6; Clamp coordinates; X +/-6; Y42; tap drill D2.5; Integral clamp pads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

QTY 4 | ALUMINUM 6061-T6 | 18 x 86 x 25 | STEP: B06_compact_base.step

Threads are pilot-diameter representations in STEP.
Make M3 threads; do not leave them as plain D2.5 bores.
Hole and thread axis locations: +/-0.05 mm.
D3.8 clearance / slotW4.5: +/-0.05 mm.
Other dimensions: ISO 2768-m; geometry from STEP.
Flatness of body seat: 0.05 mm. Ra3.2 target.

## B06 / PLAIN WEBS AND MACHINING ACCESS

Top, bottom and end setups. No enclosed undercuts. Straight web faces and specified edge breaks are defined by STEP.


MB4 / REV H / 2026-10-05 / mm / PROTOTYPE - RFQ | 2 / 2

LEFT (-X)

RIGHT (+X)

ISOMETRIC (illustration; not dimensioned)

Wall arch: true R9, centre X0/Z16; apexZ25.

Arch rim and exposed web diagonals: C0.25.

Wall/rib vertical inside corners: R2.0.

Coplanar web/base side face; no stacked rim fillets.

Internal wall/floor roots may be eased R0.2 MAX; preserve spring envelope.

Do not enlarge the slot/recess or remove integral ribs without approval.

Remaining cosmetic edges: C0.2 MAX. Thread mouths and countersink seats: C0.1 MAX.

Rear flange: Y76..86, topZ5; outside upper rim R0.9.

Smooth ramp: Y74..76, Z3..5; profile from STEP.

Ribs width3: X[-9,-6] and X[6,9].

Front web slope: (Y,Z) (58.5,3) to (63,16).

Rear web slope: (69,16) to (76,5).

Integral planar webs, 3 mm thick; no under-root rim groove.

As-machined finish; no polishing of functional seats.

Aluminum threads: gauge M3 x 0.5 - 6H.

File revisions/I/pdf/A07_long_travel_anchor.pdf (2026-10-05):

## A07 / SMOOTH CROWN ANCHOR

MB4 / REV I / 2026-10-05 / mm / PROTOTYPE - RFQ; TOP (+Z); BOTTOM (-Z; mirrored Y on screen); LEFT (-X); DATUM; X=width centre; Y=front; Z=bottom; Envelope; W18; L55; body8; crown max10; Outside shape; NoseR7; rear plan cornersR3; see STEP; Body edge fillets; UpperR0.8; lowerR0.4; Integral crown; X0/Y9; D12; topR1.0; rootR0.8; Ball cradle; W8 x L11; centreX0/Y11.5; Cradle floor; Z2; plan cornersR1.5; String slot; W3.4; floorZ3.3; round rear end; Crown slot lips; Height threads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

QTY 4 | ALUMINUM 6061-T6 | 18 x 55 x max10 | STEP: A07_long_travel_anchor.step

Rear M4 thread: see sheet2 (short tap to open window).
Height thread axes / slot width: +/-0.05 mm.
Other dimensions: ISO 2768-m; geometry from STEP.
Thread mouths / ball shoulders / string contact: C0.1 MAX.
Other remaining edges: C0.2 MAX. Ra3.2 target.

## A07 / REAR TAP AND OPEN SCREW WINDOW

M4 x 0.7 - 6H; enter at Y55 in -Y direction. Axis X0/Z4. Tap through into the open underside window.

UNDERSIDE ISOMETRIC

MB4 / REV I / 2026-10-05 / mm / PROTOTYPE - RFQ | 2 / 2

REAR (+Y): axial M4 tap / pilotD3.3

OPEN WINDOW Y25..47 (22)

FULL THREAD LAND: 8 MIN

CENTRE SECTION X=0 - REAR HALF ONLY (pilot-diameter profile)

1. Drill D3.3 from Y55 to Y43 (12), fully breaking into open window.
2. Tap M4 x 0.7 - 6H through to the window, including partial outlet walls.
3. Require full circumferential thread over Y47..55: 8 mm MIN.
4. Deburr outlet from underside; do not leave an undersized untapped outlet.
5. No blind-hole tip allowance is needed; the outlet is open.

Central window: roofZ6.3, remaining top1.7.

M4 screw major radius2: topZ6, roof clearance0.3.

WindowW4.4: nominal side clearance0.2 each.

Full thread land is outside the window.

Nominal window-to-height-tap bulk:1.5.

Front screws no longer break into the ball cradle.

Rear height taps remain forward of side reliefY28.

An extra cross pin / retaining ring is not required.

Tap depth12 = 3 x M4 nominal diameter.

Confirm outlet tapping and tool access at quotation.

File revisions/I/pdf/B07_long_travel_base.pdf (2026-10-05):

## B07 / SMOOTH BASE

MB4 / REV I / 2026-10-05 / mm / PROTOTYPE - RFQ; TOP (+Z); BOTTOM (-Z; mirrored Y on screen); FRONT (-Y); DATUM; X=width centre; Y=front; Z=bottom; Envelope; W18; L86; max height25; Main plate; Z0..3; planR4; free front upper rimC0.25; Front mount; X0 / Y8; D3.8 THRU3; Rear mount; X0 / Y81; D3.8 THRU3 at recessed seat; Both countersinks; D7 x 90 deg; axial depth1.6; CSK floor left; Front1.4; rear1.4; Rear head recess; D7.4; depth2 fromZ5 toZ3; Rear clearance tray; W8 x L8; centreY80.5; floorZ3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

QTY 4 | ALUMINUM 6061-T6 | 18 x 86 x 25 | STEP: B07_long_travel_base.step

Threads are pilot-diameter representations in STEP.
Make M3 threads; do not leave them as plain D2.5 bores.
Hole and thread axis locations: +/-0.05 mm.
D3.8 clearance / slotW4.5: +/-0.05 mm.
Other dimensions: ISO 2768-m; geometry from STEP.
Flatness of body seat: 0.05 mm. Ra3.2 target.

## B07 / PLAIN WEBS AND MACHINING ACCESS

Top, bottom and end setups. No enclosed undercuts. Straight web faces and specified edge breaks are defined by STEP.


MB4 / REV I / 2026-10-05 / mm / PROTOTYPE - RFQ | 2 / 2

LEFT (-X)

RIGHT (+X)

ISOMETRIC (illustration; not dimensioned)

Wall arch: true R9, centre X0/Z16; apexZ25.

Arch rim and exposed web diagonals: C0.25.

Wall/rib vertical inside corners: R2.0.

Coplanar web/base side face; no stacked rim fillets.

Internal wall/floor roots may be eased R0.2 MAX; preserve spring envelope.

Do not enlarge the slot/recess or remove integral ribs without approval.

Remaining cosmetic edges: C0.2 MAX. Thread mouths and countersink seats: C0.1 MAX.

Rear flange: Y76..86, topZ5; free rear end/corners R0.9.

Smooth ramp: Y74..76, Z3..5; profile from STEP.

Ribs width3: X[-9,-6] and X[6,9].

Front web slope: (Y,Z) (66,3) to (70.5,16).

Rear web slope: (76.5,16) to (81.5,5).

Integral planar webs, 3 mm thick; no under-root rim groove.
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

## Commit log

2026-10-05 Publish MB4 Rev A-I CAD archive and standalone design documentation
    [A01_anchor.step, A02_integrated_anchor.step, A03_strengthened_anchor.step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]
2026-10-06 Add Rev J rounded exterior with matching CAD drawings and validation
    [A08_rounded_anchor.step, B08_rounded_base.step, BOM.csv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]
2026-10-06 Add Rev K streamlined bridge with protected height-hole rims
    [A09_streamlined_anchor.step, B09_streamlined_base.step, BOM.csv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]
2026-10-07 Refine Rev L ball-end cradle with rounded mouth and front-only string exit
    [A10_sculpted_ball_anchor.step, B10_streamlined_base.step, BOM.csv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]
